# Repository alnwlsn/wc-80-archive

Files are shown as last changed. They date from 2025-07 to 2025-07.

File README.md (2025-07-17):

# The WC-80 (archive)

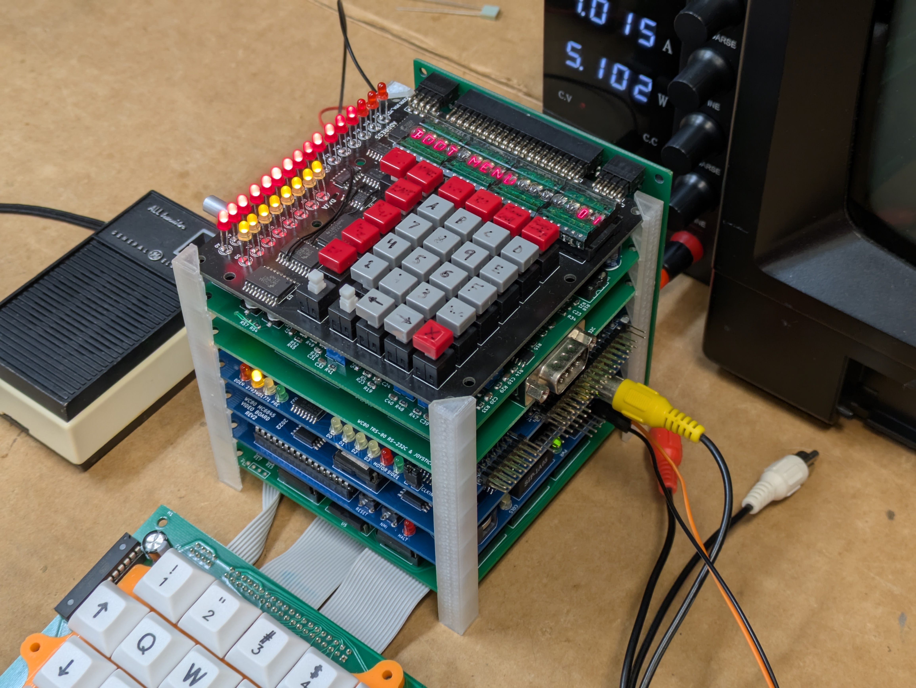
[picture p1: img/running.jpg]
image of WC-80 Cube running


My homebrew Z80 computer which is not exactly a TRS-80 Model 1 clone. Archive from 2020-2023.

## Background
Some time ago when I was in college (not that long ago, mind you, it was like 2018), I found a TRS-80 Model 1. It was the first (non-IBM PC) retrocomputer I had ever got my hands on, and in my book, is absolutely legendary, for reasons I'll have to get into some other time. What's important is that what I got was *only* the keyboard, so no power supply, no cables, no display. The first thing I tried to do with it was cobble up a power supply, and wire up an adapter so I could plug the machine into a regular TV's composite video. I powered it on. It was a working unit. 

What you get with just the base Model 1 "keyboard" is:
- Z80 CPU @ 1.77 MHz
- ROM with Level II (microsoft) BASIC
- 16K of RAM
- video output
    - "almost" NTSC / RS170 (black and white only)
    - 64 columns x 16 rows, 6x12 px character resolution, fixed character set
- cassette interface
- the keyboard itself

That's  pretty limiting if you want to do stuff(tm) with the machine. In particular, the cassette interface is a real bottleneck, taking minutes on end to load things, and it's the only way to do so besides typing it in. People thought so too in the TRS-80's heyday, so the platform evolved to have floppy disks, more memory, various operating systems, a serial port, maybe even a hard drive. These were provided by a box that plugs into the TRS-80's keyboard called the 'Expansion Interface (EI)' I did not an Expansion Interface, and they were rare and expensive on Ebay. But, the TRS-80 is old enough that it is made mostly out of standard 74 logic ICs, rather than custom chips like the C64 or later machines have, and all the schematics are right there in the manual. Having more time than any other resource back then, I thought to myself "how hard can it be?"

Following the schematics, this is what led me to create my [hand-wired Expansion Interface unit](https://alnwlsn.com/projectrepository/index.php?title=TRS-80_Model_1_-_Wilson_Expansion_Interface) and had me boot my TRS-80 from a floppy disk for possibly the first time in its life. That was not quite built as stock though:
- SRAM for extra RAM instead of DRAMs
    - why not, RAM is cheap here in the future
    - 128K ram used, in 4 swappable banks of 32K
        - just because I can, haven't done much with this
- Arduino with 1K dual port RAM put in 'hole' in TRS-80 memory map at 0x3000
    - easy and quick way to get data from modern laptop to TRS-80 RAM
- 'equivalent' logic gates, not exact chips used in EI (based on what chips I happened to have or get easily)

The hand built unit had obvious problems though:
- tedious soldering assembly
- unreliable "stacked pin header" interconnects
- not very modular, hard to add more hardware
- fragile

I then started this project to clean up the hand built unit into some real PCBs, which would go into a backplane. If I wanted to add more hardware, I could just make another card. After building most of the EI, I realized that there wasn't all that much to the rest of the computer, so I built modules for that too. Thus, the WC-80 (W Cube Z80) was born.

It's a bit like a Model 1, with some Model III (more IO on the IO ports) and Model 4 (some peripherals like the video ram and keyboard can be moved around in the memory map, and there are multiple banks of memory). The main difference is that most of the hardware options are software controlled, so it needs to boot a rom that can initialize all the hardware, then load the TRS-80 ROMs and jump to the beginning of it.

As the system took shape, I thought I might install it into a case, and make a portable machine, but soon obtained a good number of real TRS-80 machines to work on instead. I haven't touched the WC-80 much since around 2022, which means I've forgotten most of whatever I was doing on it. Still, it's probably more useful published here as incomplete than just sitting on my hard drive. When I pick up this project again, I'll probably continue in a new repo, which will be linked here if it exists.

loading frogger from a cassette

## General guidelines:
- 100x100mm typical board size
    - this is the cheap "loss leader" size offered by PCBWay and JLC. A board twice this area costs more than double the price.
- where possible, SMD SOIC packages
    - much more compact than DIP, but still easily solderable by hand with an iron
        - plus, you don't have to flip the board over
- 2 layer boards (cheapest)
- 0.2mm track width for data signals
    - fits between SOIC pads
- 74HCT (CMOS w/ TTL level inputs) over HC or LS parts, where possible
- autorouted (w/ some manual routing) with [TopoR](https://en.wikipedia.org/wiki/TopoR)
    - usually get my fill of manually routing boards at work
- designed around whatever ICs I can get for cheap
- fit as much stuff as I can onto each board
    - I paid for the whole board, I'm gonna use the whole board

## Boards
### Backplane
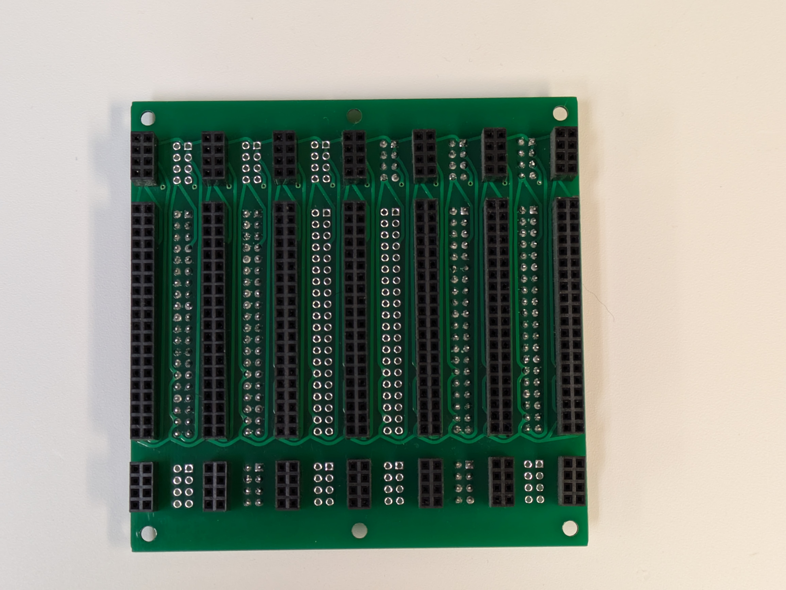
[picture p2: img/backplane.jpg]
backplane

- 40-pin interconnect is derived from the 40-pin card edge on the back of the TRS-80 Model 1, though a few pins are different, so it can't be plugged in directly.
- 8 pin connectors on either side are for power and misc. signals.
- [next revision](boards/backplane2/new/) is just a straight interconnect, which is how it probably should be.
- [this version shown](boards/backplane/) has named nets, and the power rails and GNDs are connected together on the backplane.

### CPU board
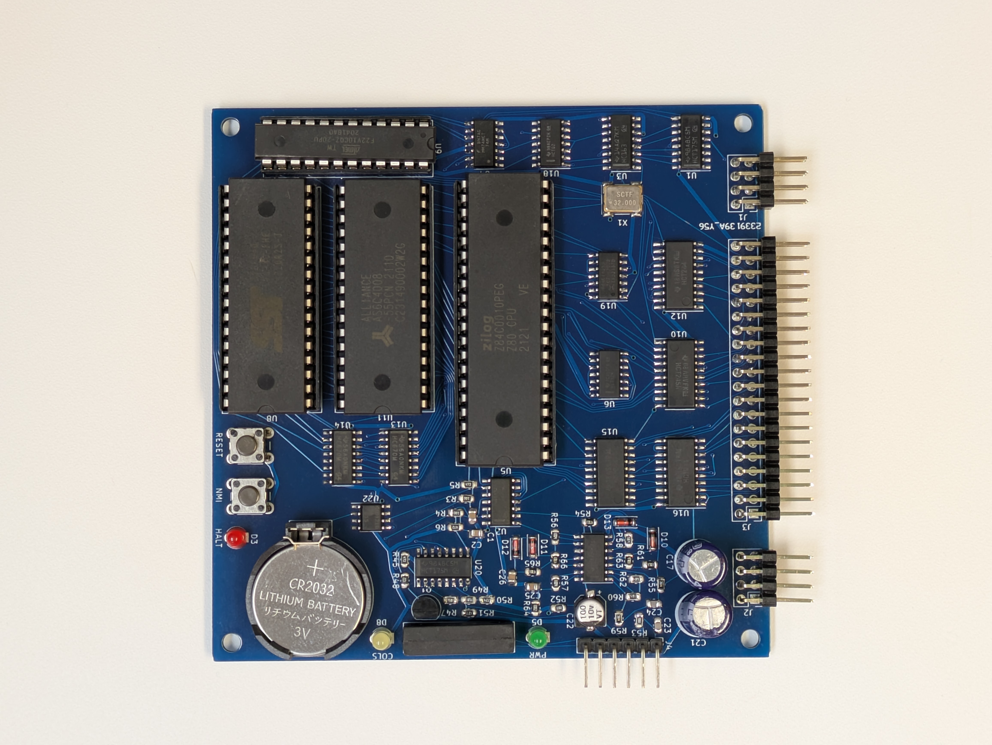
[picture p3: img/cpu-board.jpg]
cpu

- Z80 CPU
- memory map divided into 4x 16k slots, into which any 1 of 32 pages of RAM or 1 of any 32 pages of Flash ROM can be installed. 
    - bank selection by IO port
    - whole memory space is filled, but there is an INUSE pin on the backplane by which other boards can signal the CPU board that they want to use the memory space currently being accessed, in which case on-board memory will be disabled
- software selectable clock rate from 1.77MHz to 8MHz
    - CPU clock provided by a 16MHz clock feeding a counter chip which can count from 2 to 9. 16/9 happens to be pretty close to the 1.77MHz of the model 1. You also get more traditional clock rates of 2, 4 and 8Mhz.
- added the Model 1's cassette interface
    - can read and write TRS-80 Model 1 Level II tapes when running Level II ROMs
    - it can even load tapes played back at 4x speed in 8Mhz mode, seems to work just fine
    - includes reed relay for cassette remote switch
- battery backed RAM with integral RTC via [DS1315 Phantom Time chip](https://www.analog.com/en/products/ds1315.html)
    -   to get and set the RTC, you write a sequential series of special bytes to the RAM and the next byte written will come from the RTC
        - execution must be done either in a ROM or from external RAM, since you can't be both read the instructions and write the special sequence while being on the internal RAM
        - probably get rid of this in the next version, the Arduino board has the same thing already
- [I think this is the current version of the CPU](boards/cpu/cpu-rev2/)

### Keyboard
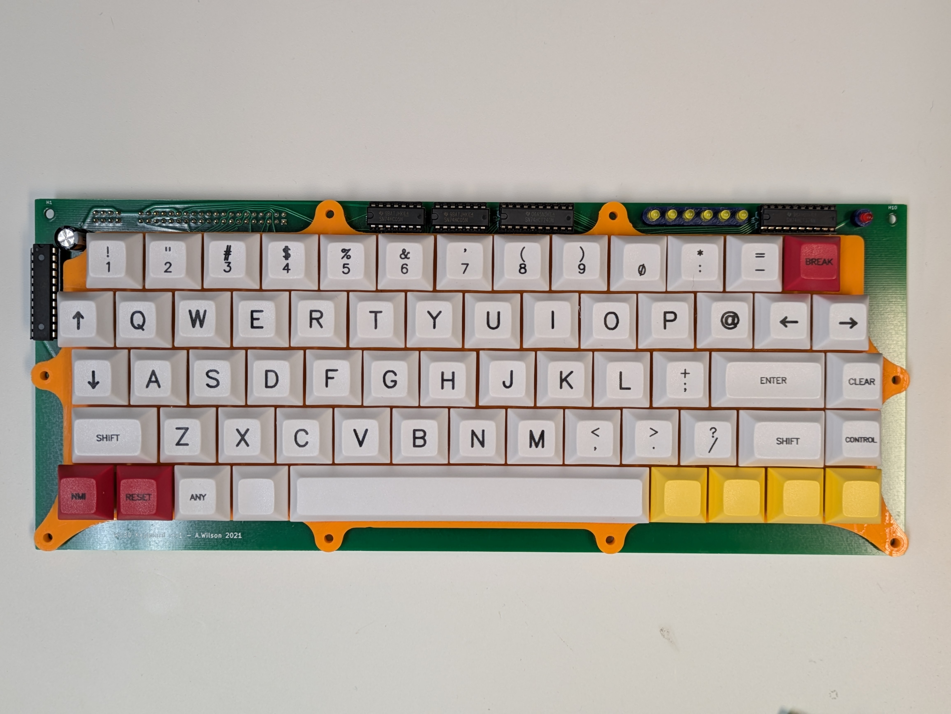
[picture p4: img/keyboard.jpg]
keyboard

- key switches wired per TRS-80 key matrix
- NMI and Reset keys broken out on board
- some extra keys for which there is room on the matrix but normally no switch there (Control key, etc) have been added 
- memory mapped, but relocatable from the default 3800 address, like a model 4
    - only uses 256 addresses, not the minimally decoded 1K the Model 1 has
- 8 leds
- a fairly standard mechanical keyboard build otherwise
- keycaps are [custom labeled](keyboard-labels/) using the [lasered toner method](https://www.youtube.com/watch?v=_V5DmHmCMaU)
- this was supposed to be a simple PCB mounted switch design, but the switches I got ended up being plate mounted. I had to reconfigure my CNC machine to be a 3D printer, as I did not have one large enough to print a full-sized backplate at the time.
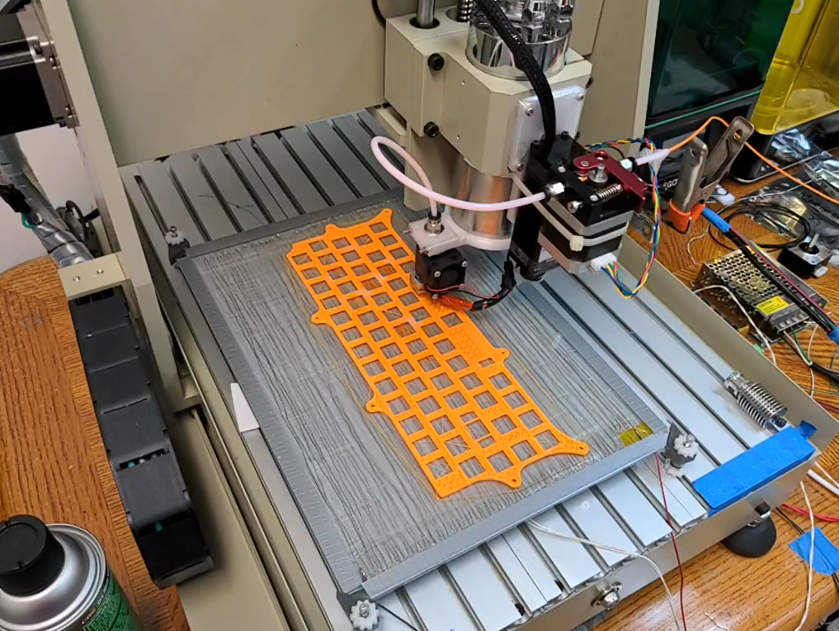
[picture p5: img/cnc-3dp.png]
cnc 3d printer


### Old CPU
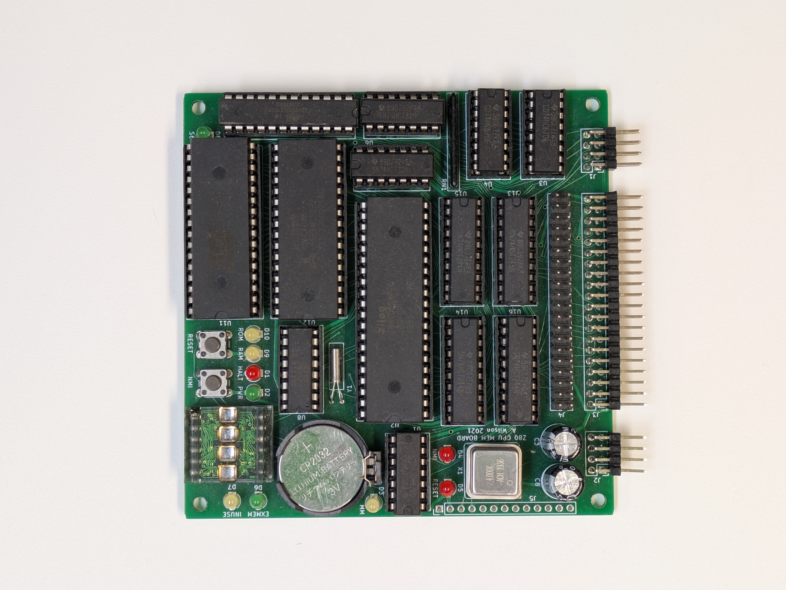
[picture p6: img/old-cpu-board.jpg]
Old CPU

- [despite being called 'cpu5' and the new one being 'cpu2', this is the older one](boards/cpu/cpu5/)
- same as the current CPU board, only using DIP chips and having a HP Dl1414 4-character LED display instead of the cassette interface. This display is usually not visible, so I got rid of it.

```alnwlsn-ssg
title: The WC-80 (archive)
subtitle: homebrew TRS-80 I made one time
date: 2025-07-16
labels: retrocomputing, trs80
```

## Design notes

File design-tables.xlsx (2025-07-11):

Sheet: io-addresses
Function | MEM | IO | 7 | 6 | 5 | 4 | 3 | 2 | 1 | 0 | 7 | 6 | 5 | 4 | 3 | 2 | 1 | 0 | value set on system reset boot
Disk Command/Status | 37EC | F0 |  |  |  |  |  |  |  |  |  |  |  |  |  |  |  |  | 0
Density Select | 37EC | F0 |  |  |  |  |  |  |  |  | 1 | 1 | 1 | 1 | 1 | x | x | DD | f8
Disk Track | 37ED | F1 |  |  |  |  |  |  |  |  |  |  |  |  |  |  |  |  | 0
Disk Sector | 37EE | F2 |  |  |  |  |  |  |  |  |  |  |  |  |  |  |  |  | 0
5/8 Select | 37EE | F2 |  |  |  |  |  |  |  |  | 1 | 8INCH | x | x | x | x | x | x | 80
Disk Data | 37EF | F3 |  |  |  |  |  |  |  |  |  |  |  |  |  |  |  |  | 0
Disk Select | 37E1 | F4 |  |  |  |  |  |  |  |  |  |  |  |  | DRV3 | DRV2 | DRV1 | DRV0 | 0
Model 3 Options | N/A | F4 |  |  |  |  |  |  |  |  | DD | x | WPRE | SIDE1 |  |  |  |  | 0
Interrupt Status | 37E0 | F6 | Clock | Disk |  |  |  |  |  |  |  |  |  |  |  |  |  |  | 0
WC80 Options | N/A | F6 |  |  |  |  |  |  |  |  |  |  |  |  | x | x | MOD3 | 2793 | 1
Printer | 37E8 | F8 |  |  |  |  |  |  |  |  |  |  |  |  |  |  |  |  | 0
mem bank 0 |  | 70 |  |  |  |  |  |  |  |  | !EXMEM 0000-3FFF |  | RAM !ROM
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

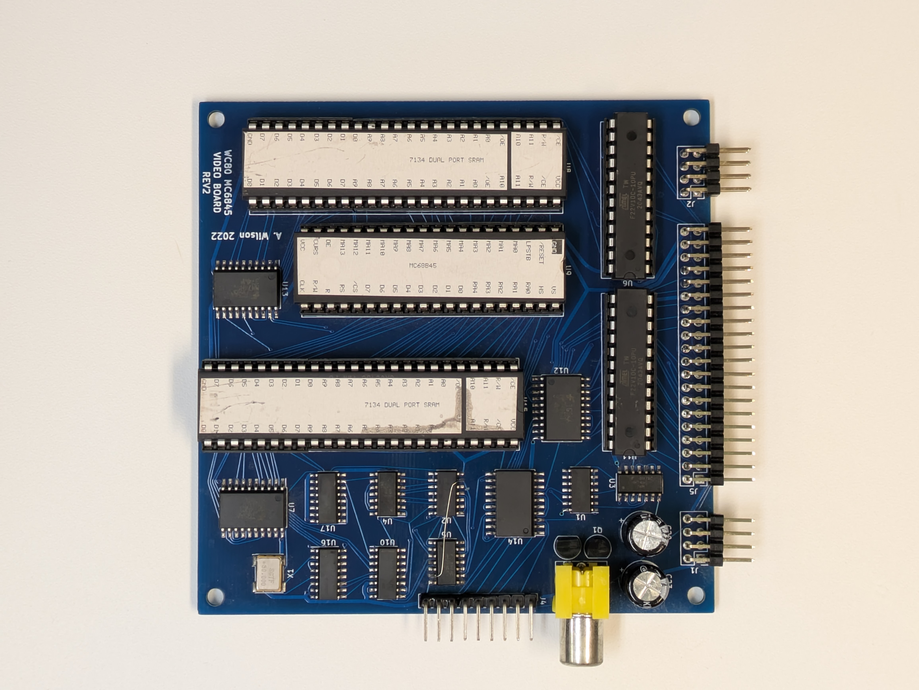
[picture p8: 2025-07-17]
img/video-board.jpg

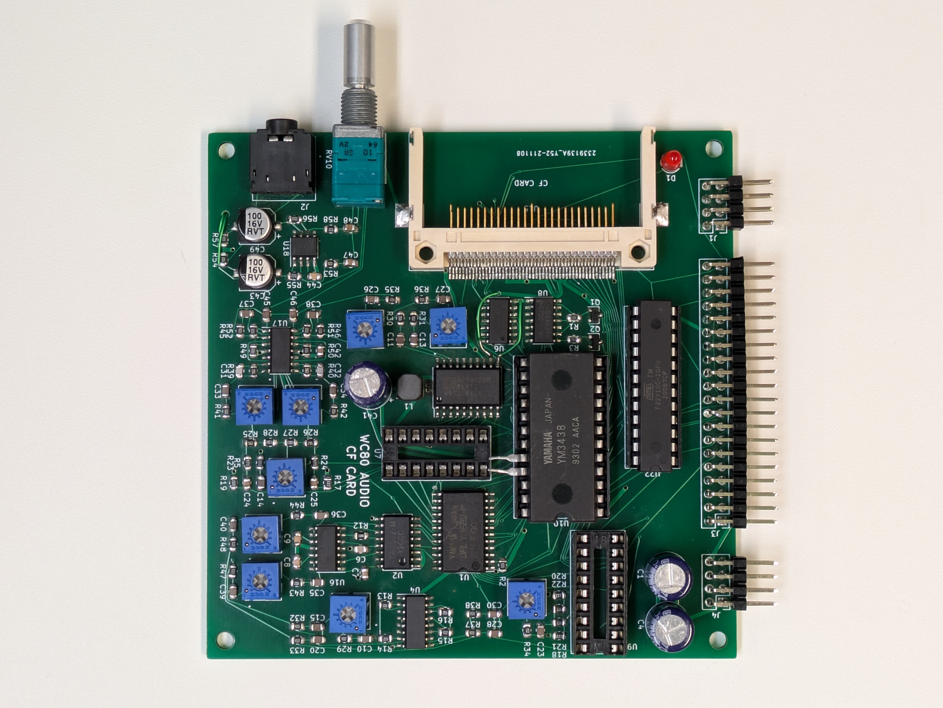
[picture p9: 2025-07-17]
img/sound-board.jpg

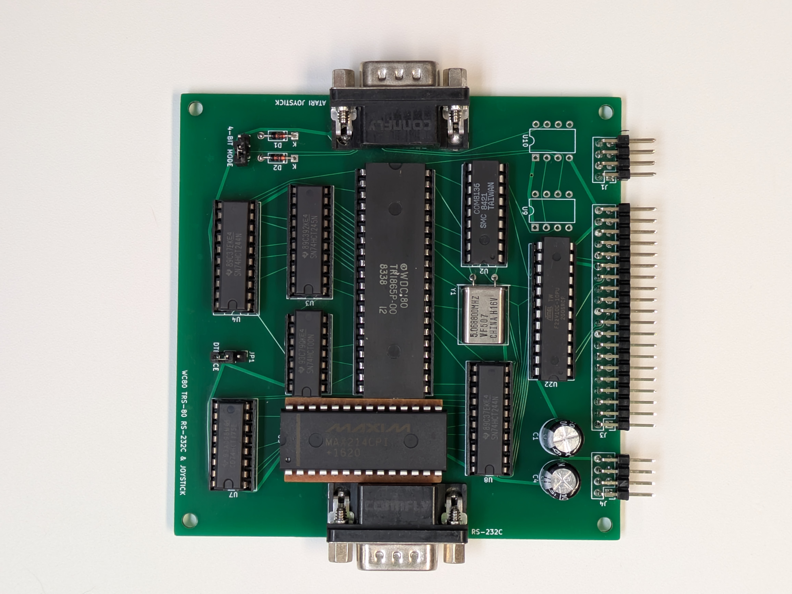
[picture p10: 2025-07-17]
img/rs-232 board.jpg

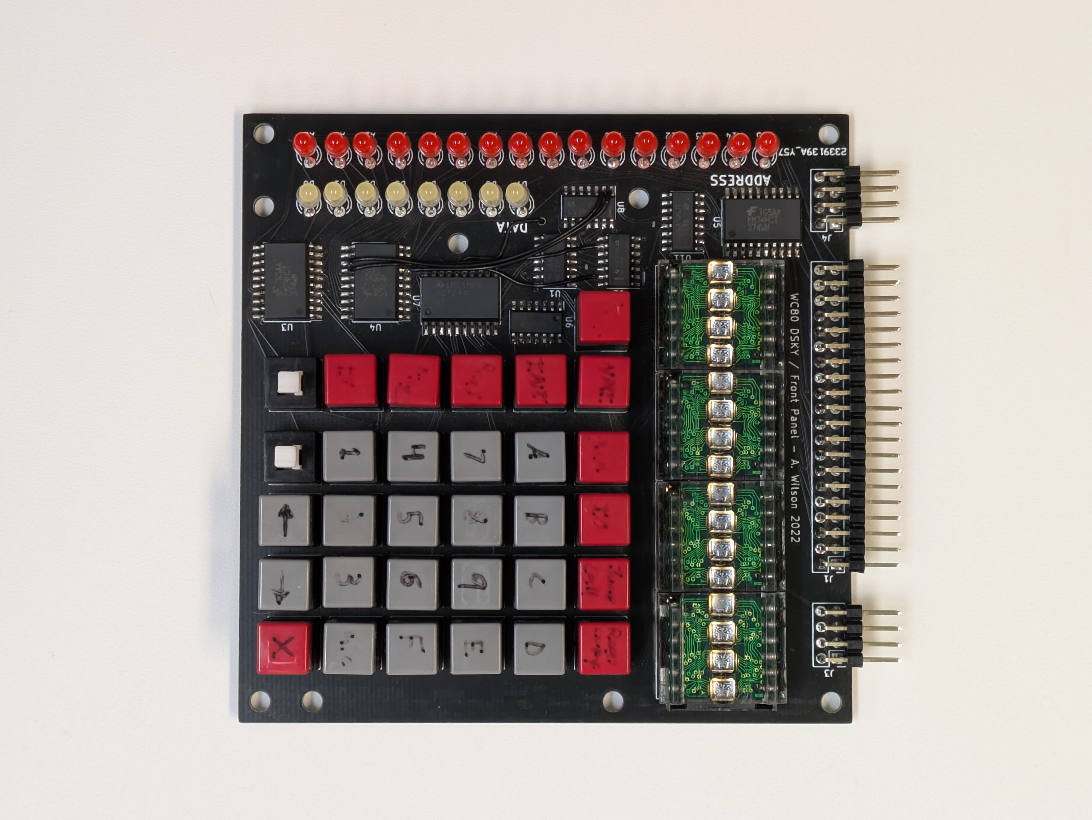
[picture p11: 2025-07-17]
img/front-panel.jpg

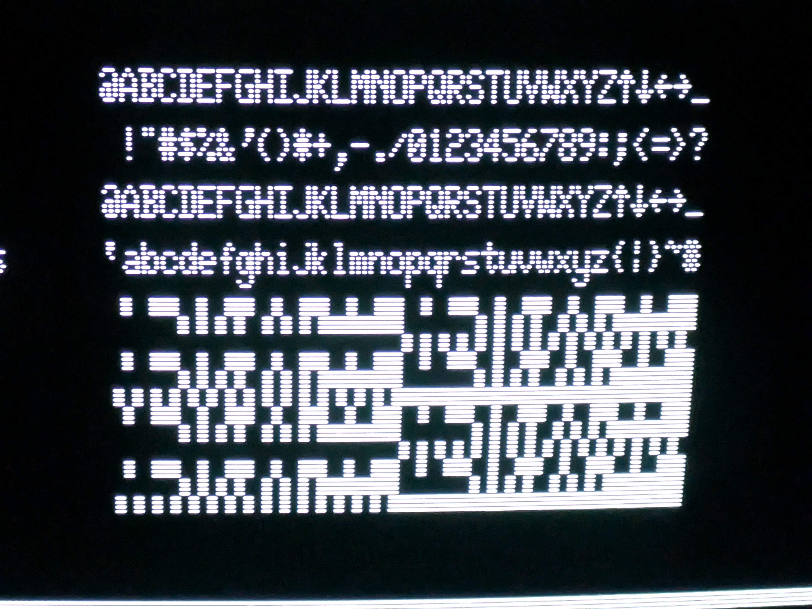
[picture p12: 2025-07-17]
img/video-quality.jpg

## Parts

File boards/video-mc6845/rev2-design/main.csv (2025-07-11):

Reference | Value | Footprint | Datasheet
C8 | 470uF | Capacitor_THT:CP_Radial_D8.0mm_P3.50mm | ~
C10 | 100n | Capacitor_SMD:C_0805_2012Metric | ~
C9 | 100n | Capacitor_SMD:C_0805_2012Metric | ~
C11 | 470uF | Capacitor_THT:CP_Radial_D8.0mm_P3.50mm | ~
J2 | Conn_02x04_Odd_Even | Connector_PinHeader_2.54mm:PinHeader_2x04_P2.54mm_Vertical | ~
J1 | Conn_02x04_Odd_Even | Connector_PinHeader_2.54mm:PinHeader_2x04_P2.54mm_Vertical | ~
C1 | 100n | Capacitor_SMD:C_0805_2012Metric | ~
C7 | 100n | Capacitor_SMD:C_0805_2012Metric | ~
C2 | 100n | Capacitor_SMD:C_0805_2012Metric | ~
C3 | 100n | Capacitor_SMD:C_0805_2012Metric | ~
C4 | 100n | Capacitor_SMD:C_0805_2012Metric | ~
C5 | 100n | Capacitor_SMD:C_0805_2012Metric | ~
C6 | 100n | Capacitor_SMD:C_0805_2012Metric | ~
U15 | 74LS175 | Package_SO:SOIC-16_3.9x9.9mm_P1.27mm | http://www.ti.com/lit/gpn/sn74LS175
R12 | 10K | Resistor_SMD:R_0805_2012Metric | ~
U13 | 74LS374 | Package_SO:SOIC-20W_7.5x12.8mm_P1.27mm | http://www.ti.com/lit/gpn/sn74LS374
U2 | 74LS02 | Package_SO:SOIC-14_3.9x8.7mm_P1.27mm | http://www.ti.com/lit/gpn/sn74ls02
U1 | 74LS02 | Package_SO:SOIC-14_3.9x8.7mm_P1.27mm | http://www.ti.com/lit/gpn/sn74ls02
U18 | 74LS165 | Package_SO:SO-16_3.9x9.9mm_P1.27mm | https://www.ti.com/lit/ds/symlink/sn74ls165a.pdf
R2 | 10K | Resistor_SMD:R_0805_2012Metric | ~
R13 | 10K | Resistor_SMD:R_0805_2012Metric | ~
U4 | 74LS74 | Package_SO:SOIC-14_3.9x8.7mm_P1.27mm | 74xx/74hc_hct74.pdf
U3 | 74LS74 | Package_SO:SOIC-14_3.9x8.7mm_P1.27mm | 74xx/74hc_hct74.pdf
U6 | 74LS374 | Package_SO:SOIC-20W_7.5x12.8mm_P1.27mm | http://www.ti.com/lit/gpn/sn74LS374
R5 | 10K | Resistor_SMD:R_0805_2012Metric | ~
R4 | 10K | Resistor_SMD:R_0805_2012Metric | ~
R15 | 10K | Resistor_SMD:R_0805_2012Metric | ~
J3 | LIGHT_PEN | Connector_PinHeader_2.54mm:PinHeader_1x04_P2.54mm_Horizontal | ~
J4 | CRT_SIGNALS | Connector_PinHeader_2.54mm:PinHeader_1x05_P2.54mm_Vertical | ~
U14 | 74LS244 | Package_SO:SOIC-20W_7.5x12.8mm_P1.27mm | http://www.ti.com/lit/ds/symlink/sn74ls244.pdf
R1 | 10K | Resistor_SMD:R_0805_2012Metric | ~
R6 | 1800 | Resistor_SMD:R_0805_2012Metric | ~
R8 | 2000 | Resistor_SMD:R_0805_2012Metric | ~
R10 | 470 | Resistor_SMD:R_0805_2012Metric | ~
R11 | 470 | Resistor_SMD:R_0805_2012Metric | ~
Q1 | 2N3904 | Package_TO_SOT_THT:TO-92_Inline | https://www.onsemi.com/pub/Collateral/2N3903-D.PDF
U17 | 74LS163 | Package_SO:SOIC-16_3.9x9.9mm_P1.27mm | http://www.ti.com/lit/gpn/sn74LS163
R14 | 10K | Resistor_SMD:R_0805_2012Metric | ~
X1 | SG-7050CAN | Oscillator:Oscillator_SMD_SeikoEpson_SG8002CA-4Pin_7.0x5.0mm | https://support.epson.biz/td/api/doc_check.php?dl=brief_SG7050CAN&lang=en
U9 | 74LS163 | Package_SO:SOIC-16_3.9x9.9mm_P1.27mm | http://www.ti.com/lit/gpn/sn74LS163
R7 | 10 | Resistor_SMD:R_0805_2012Metric | ~
R3 | optional | Resistor_SMD:R_0805_2012Metric | ~
U12 | 74LS374 | Package_SO:SOIC-20W_7.5x12.8mm_P1.27mm | http://www.ti.com/lit/gpn/sn74LS374
Q2 | BSS138 | Package_TO_SOT_SMD:SOT-23 | https://www.onsemi.com/pub/Collateral/BSS138-D.PDF
R9 | 100 | Resistor_SMD:R_0805_2012Metric | ~
R16 | 100 | Resistor_SMD:R_0805_2012Metric | ~
Q3 | BSS138 | Package_TO_SOT_SMD:SOT-23 | https://www.onsemi.com/pub/Collateral/BSS138-D.PDF
C12 | 100n | Capacitor_SMD:C_0805_2012Metric | ~
C13 | 100n | Capacitor_SMD:C_0805_2012Metric | ~
C14 | 100n | Capacitor_SMD:C_0805_2012Metric | ~
C15 | 100n | Capacitor_SMD:C_0805_2012Metric | ~
C16 | 100n | Capacitor_SMD:C_0805_2012Metric | ~
C17 | 100n | Capacitor_SMD:C_0805_2012Metric | ~
C18 | 100n | Capacitor_SMD:C_0805_2012Metric | ~
C19 | 100n | Capacitor_SMD:C_0805_2012Metric | ~
C20 | 100n | Capacitor_SMD:C_0805_2012Metric | ~
C21 | 100n | Capacitor_SMD:C_0805_2012Metric | ~
C22 | 100n | Capacitor_SMD:C_0805_2012Metric | ~
J6 | Conn_Coaxial | wilson-z80:AV-5 | ~

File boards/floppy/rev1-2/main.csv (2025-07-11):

Reference | Value | Footprint | Datasheet | Mouser
C10 | 100n | Capacitor_SMD:C_0805_2012Metric | ~
C11 | 100n | Capacitor_SMD:C_0805_2012Metric | ~
C16 | 100n | Capacitor_SMD:C_0805_2012Metric | ~
C17 | 100n | Capacitor_SMD:C_0805_2012Metric | ~
C18 | 100n | Capacitor_SMD:C_0805_2012Metric | ~
C19 | 100n | Capacitor_SMD:C_0805_2012Metric | ~
C2 | 100n | Capacitor_SMD:C_0805_2012Metric | ~
C20 | 100n | Capacitor_SMD:C_0805_2012Metric | ~
C21 | 100n | Capacitor_SMD:C_0805_2012Metric | ~
C22 | 100n | Capacitor_SMD:C_0805_2012Metric | ~
C23 | 100n | Capacitor_SMD:C_0805_2012Metric | ~
C24 | 100n | Capacitor_SMD:C_0805_2012Metric | ~
C25 | 100n | Capacitor_SMD:C_0805_2012Metric | ~
C26 | 100n | Capacitor_SMD:C_0805_2012Metric | ~
C27 | 100n | Capacitor_SMD:C_0805_2012Metric | ~
C28 | 100n | Capacitor_SMD:C_0805_2012Metric | ~
C29 | 100n | Capacitor_SMD:C_0805_2012Metric | ~
C3 | 100n | Capacitor_SMD:C_0805_2012Metric | ~
C30 | 100n | Capacitor_SMD:C_0805_2012Metric | ~
C31 | 100n | Capacitor_SMD:C_0805_2012Metric | ~
C32 | 100n | Capacitor_SMD:C_0805_2012Metric | ~
C33 | 100n | Capacitor_SMD:C_0805_2012Metric | ~
C34 | 100n | Capacitor_SMD:C_0805_2012Metric | ~
C35 | 100n | Capacitor_SMD:C_0805_2012Metric | ~
C36 | 100n | Capacitor_SMD:C_0805_2012Metric | ~
C37 | 100n | Capacitor_SMD:C_0805_2012Metric | ~
C38 | 100n | Capacitor_SMD:C_0805_2012Metric | ~
C39 | 100n | Capacitor_SMD:C_0805_2012Metric | ~
C40 | 100n | Capacitor_SMD:C_0805_2012Metric | ~
C41 | 100n | Capacitor_SMD:C_0805_2012Metric | ~
C42 | 100n | Capacitor_SMD:C_0805_2012Metric | ~
C43 | 100n | Capacitor_SMD:C_0805_2012Metric | ~
C6 | 100n | Capacitor_SMD:C_0805_2012Metric | ~
C7 | 100n | Capacitor_SMD:C_0805_2012Metric | ~
C8 | 100n | Capacitor_SMD:C_0805_2012Metric | ~
C9 | 150nF | Capacitor_SMD:C_0805_2012Metric | ~
C12 | 15pF | Capacitor_SMD:C_0805_2012Metric | ~
C13 | 15pF | Capacitor_SMD:C_0805_2012Metric | ~
C14 | 15pF | Capacitor_SMD:C_0805_2012Metric | ~
C15 | 200p | Capacitor_SMD:C_0805_2012Metric | ~
C5 | 33uF | Capacitor_SMD:C_0805_2012Metric | ~
C44 | 60pF | Capacitor_THT:C_Rect_L7.0mm_W6.0mm_P5.00mm | ~
C1 | 470uF | Capacitor_THT:CP_Radial_D8.0mm_P3.50mm | ~
C4 | 470uF | Capacitor_THT:CP_Radial_D8.0mm_P3.50mm | ~
JP1 | SIDE | Connector_PinHeader_2.54mm:PinHeader_1x02_P2.54mm_Vertical | ~
JP2 | TEST | Connector_PinHeader_2.54mm:PinHeader_1x02_P2.54mm_Vertical | ~
J1 | Conn_02x04_Odd_Even | Connector_PinHeader_2.54mm:PinHeader_2x04_P2.54mm_Vertical | ~
J4 | Conn_02x04_Odd_Even | Connector_PinHeader_2.54mm:PinHeader_2x04_P2.54mm_Vertical | ~
J5 | Conn_01x16_Male | Connector_PinHeader_2.54mm:PinHeader_2x08_P2.54mm_Vertical | ~
J2 | Floppy-header | Connector_PinHeader_2.54mm:PinHeader_2x17_P2.54mm_Vertical
J3 | TRS80W-header | Connector_PinHeader_2.54mm:PinHeader_2x20_P2.54mm_Vertical
D1 | DIODE | Diode_SMD:D_0805_2012Metric | ~
D6 | D0 | LED_THT:LED_D3.0mm | ~
D7 | D1 | LED_THT:LED_D3.0mm | ~
D8 | D2 | LED_THT:LED_D3.0mm | ~
D9 | D3 | LED_THT:LED_D3.0mm | ~
D4 | DDEN | LED_THT:LED_D3.0mm | ~
D10 | MOTOR | LED_THT:LED_D3.0mm | ~
D5 | PRE | LED_THT:LED_D3.0mm | ~
D11 | SIDE1 | LED_THT:LED_D3.0mm | ~
D3 | WD1771 | LED_THT:LED_D3.0mm | ~
D2 | WD2793 | LED_THT:LED_D3.0mm | ~
M1 | 3mm-mounting-hole | MountingHole:MountingHole_3.2mm_M3_DIN965
M2 | 3mm-mounting-hole | MountingHole:MountingHole_3.2mm_M3_DIN965
M3 | 3mm-mounting-hole | MountingHole:MountingHole_3.2mm_M3_DIN965
M4 | 3mm-mounting-hole | MountingHole:MountingHole_3.2mm_M3_DIN965
X1 | CXO_DIP8 | Oscillator:Oscillator_DIP-8 | http://cdn-reichelt.de/documents/datenblatt/B400/OSZI.pdf | 815-ACH-4-EK
U22 | ATF22V10C | Package_DIP:DIP-24_W7.62mm_Socket
U5 | WD1771 | Package_DIP:DIP-40_W15.24mm_Socket
U16 | WD2793 | Package_DIP:DIP-40_W15.24mm_Socket
U3 | 74LS123 | Package_SO:SO-16_5.3x10.2mm_P1.27mm | http://www.ti.com/lit/gpn/sn74LS123 | 595-SN74LS123NSR
U23 | 74LS244 | Package_SO:SO-20_5.3x12.6mm_P1.27mm | http://www.ti.com/lit/ds/symlink/sn74ls244.pdf | 595-SN74HCT244NSR
U17 | 74LS245 | Package_SO:SO-20_5.3x12.6mm_P1.27mm | http://www.ti.com/lit/gpn/sn74LS245 | 595-SN74LS245NS
U24 | 74LS273 | Package_SO:SO-20_5.3x12.6mm_P1.27mm | http://www.ti.com/lit/gpn/sn74LS273 | 595-SN74LS273NSR
U6 | 74LS640 | Package_SO:SO-20_5.3x12.6mm_P1.27mm | http://www.ti.com/lit/gpn/sn74LS245 | 595-SN74LS640NSR
U12 | 74LS00 | Package_SO:SOIC-14_3.9x8.7mm_P1.27mm | http://www.ti.com/lit/gpn/sn74ls00 | 595-SN74HCT00DE4
U18 | 74LS00 | Package_SO:SOIC-14_3.9x8.7mm_P1.27mm | http://www.ti.com/lit/gpn/sn74ls00 | 595-SN74HCT00DE4
U25 | 74LS00 | Package_SO:SOIC-14_3.9x8.7mm_P1.27mm | http://www.ti.com/lit/gpn/sn74ls00 | 595-SN74HCT00DE4
U30 | 74LS00 | Package_SO:SOIC-14_3.9x8.7mm_P1.27mm | http://www.ti.com/lit/gpn/sn74ls00 | 595-SN74HCT00DE4
U13 | 74LS02 | Package_SO:SOIC-14_3.9x8.7mm_P1.27mm | http://www.ti.com/lit/gpn/sn74ls02 | 595-SN74HCT02DR
U19 | 74LS02 | Package_SO:SOIC-14_3.9x8.7mm_P1.27mm | http://www.ti.com/lit/gpn/sn74ls02 | 595-SN74HCT02DR
U1 | 74LS06 | Package_SO:SOIC-14_3.9x8.7mm_P1.27mm | http://www.ti.com/lit/gpn/sn74LS06 | 595-SN74LS06D
U4 | 74LS06 | Package_SO:SOIC-14_3.9x8.7mm_P1.27mm | http://www.ti.com/lit/gpn/sn74LS06 | 595-SN74LS06D
U11 | 74LS32 | Package_SO:SOIC-14_3.9x8.7mm_P1.27mm | http://www.ti.com/lit/gpn/sn74LS32 | 595-SN74HCT32D
U20 | 74LS32 | Package_SO:SOIC-14_3.9x8.7mm_P1.27mm | http://www.ti.com/lit/gpn/sn74LS32 | 595-SN74HCT32D
U26 | 74LS32 | Package_SO:SOIC-14_3.9x8.7mm_P1.27mm | 74xx/74hc_hct74.pdf | 595-SN74HCT32D
U14 | 74LS74 | Package_SO:SOIC-14_3.9x8.7mm_P1.27mm | 74xx/74hc_hct74.pdf | 863-MC74HCT74ADR2G
U15 | 74LS74 | Package_SO:SOIC-14_3.9x8.7mm_P1.27mm | 74xx/74hc_hct74.pdf | 863-MC74HCT74ADR2G
U21 | 74LS74 | Package_SO:SOIC-14_3.9x8.7mm_P1.27mm | 74xx/74hc_hct74.pdf | 863-MC74HCT74ADR2G
U27 | 74LS74 | Package_SO:SOIC-14_3.9x8.7mm_P1.27mm | 74xx/74hc_hct74.pdf | 863-MC74HCT74ADR2G
U10 | 4518 | Package_SO:SOP-16_3.9x9.9mm_P1.27mm | http://www.intersil.com/content/dam/Intersil/documents/cd45/cd4518bms-20bms.pdf | 595-CD4518BM
U8 | 4518 | Package_SO:SOP-16_3.9x9.9mm_P1.27mm | http://www.intersil.com/content/dam/Intersil/documents/cd45/cd4518bms-20bms.pdf | 595-CD4518BM
U9 | 4518 | Package_SO:SOP-16_3.9x9.9mm_P1.27mm | http://www.intersil.com/content/dam/Intersil/documents/cd45/cd4518bms-20bms.pdf | 595-CD4518BM
U29 | 74LS157 | Package_SO:SOP-16_3.9x9.9mm_P1.27mm | http://www.ti.com/lit/gpn/sn74LS157 | 595-SN74HCT157D
U7 | 74LS157 | Package_SO:SOP-16_3.9x9.9mm_P1.27mm | http://www.ti.com/lit/gpn/sn74LS157 | 595-SN74HCT157D
U2 | 74LS175 | Package_SO:SOP-16_3.9x9.9mm_P1.27mm | http://www.ti.com/lit/gpn/sn74LS175 | 595-CD74HCT175M
U28 | 74LS175 | Package_SO:SOP-16_3.9x9.9mm_P1.27mm | http://www.ti.com/lit/gpn/sn74LS175 | 595-CD74HCT175M
RV2 | 10K | Potentiometer_THT:Potentiometer_Bourns_3266W_Vertical | ~
RV1 | 50K | Potentiometer_THT:Potentiometer_Bourns_3266W_Vertical | ~
R17 | 150 | Resistor_SMD:R_0805_2012Metric | ~
R18 | 150 | Resistor_SMD:R_0805_2012Metric | ~
R19 | 150 | Resistor_SMD:R_0805_2012Metric | ~
R20 | 150 | Resistor_SMD:R_0805_2012Metric | ~
R21 | 470 | Resistor_SMD:R_0805_2012Metric | ~
R22 | 470 | Resistor_SMD:R_0805_2012Metric | ~
R24 | 470 | Resistor_SMD:R_0805_2012Metric | ~
R25 | 470 | Resistor_SMD:R_0805_2012Metric | ~
R26 | 470 | Resistor_SMD:R_0805_2012Metric | ~
R27 | 470 | Resistor_SMD:R_0805_2012Metric | ~
R28 | 470 | Resistor_SMD:R_0805_2012Metric | ~
R29 | 470 | Resistor_SMD:R_0805_2012Metric | ~
R30 | 470 | Resistor_SMD:R_0805_2012Metric | ~
R31 | 470 | Resistor_SMD:R_0805_2012Metric | ~
R10 | 10K | Resistor_SMD:R_0805_2012Metric | ~
R12 | 10K | Resistor_SMD:R_0805_2012Metric | ~
R14 | 10K | Resistor_SMD:R_0805_2012Metric | ~
R23 | 10K | Resistor_SMD:R_0805_2012Metric | ~
R3 | 10K | Resistor_SMD:R_0805_2012Metric | ~
R4 | 10K | Resistor_SMD:R_0805_2012Metric | ~
R5 | 10K | Resistor_SMD:R_0805_2012Metric | ~
R6 | 10K | Resistor_SMD:R_0805_2012Metric | ~
R7 | 10K | Resistor_SMD:R_0805_2012Metric | ~
R8 | 10K | Resistor_SMD:R_0805_2012Metric | ~
R9 | 10K | Resistor_SMD:R_0805_2012Metric | ~
R11 | 1K | Resistor_SMD:R_0805_2012Metric | ~
R1 | 200K | Resistor_SMD:R_0805_2012Metric | ~
R13 | 20K | Resistor_SMD:R_0805_2012Metric | ~
R15 | 4K7 | Resistor_SMD:R_0805_2012Metric | ~
R16 | 4K7 | Resistor_SMD:R_0805_2012Metric | ~
R2 | 4K7 | Resistor_SMD:R_0805_2012Metric | ~

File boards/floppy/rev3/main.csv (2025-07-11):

Reference | Value | Footprint | Datasheet | Mouser
J1 | Floppy-header | Connector_PinHeader_2.54mm:PinHeader_2x17_P2.54mm_Vertical
U4 | 74LS245 | Package_SO:SO-20_5.3x12.6mm_P1.27mm | http://www.ti.com/lit/gpn/sn74LS245 | 595-SN74LS245NS
U9 | WD2793 | Package_DIP:DIP-40_W15.24mm_Socket
U8 | WD1771 | Package_DIP:DIP-40_W15.24mm_Socket
U3 | 74LS640 | Package_SO:SO-20_5.3x12.6mm_P1.27mm | http://www.ti.com/lit/gpn/sn74LS245 | 595-SN74LS640NSR
R4 | 10K | Resistor_SMD:R_0805_2012Metric | ~
U18 | 74LS06 | Package_SO:SOIC-14_3.9x8.7mm_P1.27mm | http://www.ti.com/lit/gpn/sn74LS06 | 595-SN74LS06D
U15 | 74LS157 | Package_SO:SOP-16_3.9x9.9mm_P1.27mm | http://www.ti.com/lit/gpn/sn74LS157 | 595-SN74HCT157D
R8 | 10K | Resistor_SMD:R_0805_2012Metric | ~
U13 | ATF22V10C | Package_DIP:DIP-24_W7.62mm_Socket
U19 | 74LS06 | Package_SO:SOIC-14_3.9x8.7mm_P1.27mm | http://www.ti.com/lit/gpn/sn74LS06 | 595-SN74LS06D
U10 | 74LS123 | Package_SO:SO-16_5.3x10.2mm_P1.27mm | http://www.ti.com/lit/gpn/sn74LS123 | 595-SN74LS123NSR
U14 | 74LS175 | Package_SO:SOP-16_3.9x9.9mm_P1.27mm | http://www.ti.com/lit/gpn/sn74LS175 | 595-CD74HCT175M
JP10 | SIDE | Connector_PinHeader_2.54mm:PinHeader_1x02_P2.54mm_Vertical | ~
U30 | 74LS273 | Package_SO:SO-20_5.3x12.6mm_P1.27mm | http://www.ti.com/lit/gpn/sn74LS273 | 595-SN74LS273NSR
R37 | 4K7 | Resistor_SMD:R_0805_2012Metric | ~
R36 | 20K | Resistor_SMD:R_0805_2012Metric | ~
C45 | 200p | Capacitor_SMD:C_0805_2012Metric | ~
R38 | 4K7 | Resistor_SMD:R_0805_2012Metric | ~
U26 | 74LS244 | Package_SO:SO-20_5.3x12.6mm_P1.27mm | http://www.ti.com/lit/ds/symlink/sn74ls244.pdf | 595-SN74HCT244NSR
J6 | Conn_01x16_Male | Connector_PinHeader_2.54mm:PinHeader_2x08_P2.54mm_Vertical | ~
R3 | 200K | Resistor_SMD:R_0805_2012Metric | ~
R35 | 10K | Resistor_SMD:R_0805_2012Metric | ~
U12 | 74LS02 | Package_SO:SOIC-14_3.9x8.7mm_P1.27mm | http://www.ti.com/lit/gpn/sn74ls02 | 595-SN74HCT02DR
R1 | 10K | Resistor_SMD:R_0805_2012Metric | ~
R6 | 10K | Resistor_SMD:R_0805_2012Metric | ~
R5 | 10K | Resistor_SMD:R_0805_2012Metric | ~
RV1 | 50K | Potentiometer_THT:Potentiometer_Bourns_3266W_Vertical | ~
RV2 | 10K | Potentiometer_THT:Potentiometer_Bourns_3266W_Vertical | ~
D1 | DIODE | Diode_SMD:D_0805_2012Metric | ~
C7 | 150nF | Capacitor_SMD:C_0805_2012Metric | ~
R7 | 1K | Resistor_SMD:R_0805_2012Metric | ~
JP1 | TEST | Connector_PinHeader_2.54mm:PinHeader_1x02_P2.54mm_Vertical | ~
C4 | 15pF | Capacitor_SMD:C_0805_2012Metric | ~
C5 | 15pF | Capacitor_SMD:C_0805_2012Metric | ~
C6 | 15pF | Capacitor_SMD:C_0805_2012Metric | ~
U11 | 74LS00 | Package_SO:SOIC-14_3.9x8.7mm_P1.27mm | http://www.ti.com/lit/gpn/sn74ls00 | 595-SN74HCT00DE4
U5 | 74LS02 | Package_SO:SOIC-14_3.9x8.7mm_P1.27mm | http://www.ti.com/lit/gpn/sn74ls02 | 595-SN74HCT02DR
U6 | 74LS32 | Package_SO:SOIC-14_3.9x8.7mm_P1.27mm | http://www.ti.com/lit/gpn/sn74LS32 | 595-SN74HCT32D
U7 | 74LS00 | Package_SO:SOIC-14_3.9x8.7mm_P1.27mm | http://www.ti.com/lit/gpn/sn74ls00 | 595-SN74HCT00DE4
U20 | 74LS74 | Package_SO:SOIC-14_3.9x8.7mm_P1.27mm | 74xx/74hc_hct74.pdf | 863-MC74HCT74ADR2G
R11 | 10K | Resistor_SMD:R_0805_2012Metric | ~
U17 | 74LS32 | Package_SO:SOIC-14_3.9x8.7mm_P1.27mm | 74xx/74hc_hct74.pdf | 595-SN74HCT32D
C18 | 470uF | Capacitor_THT:CP_Radial_D8.0mm_P3.50mm | ~
C13 | 100n | Capacitor_SMD:C_0805_2012Metric | ~
C14 | 100n | Capacitor_SMD:C_0805_2012Metric | ~
C15 | 100n | Capacitor_SMD:C_0805_2012Metric | ~
C16 | 100n | Capacitor_SMD:C_0805_2012Metric | ~
C17 | 100n | Capacitor_SMD:C_0805_2012Metric | ~
C20 | 100n | Capacitor_SMD:C_0805_2012Metric | ~
C19 | 100n | Capacitor_SMD:C_0805_2012Metric | ~
C21 | 470uF | Capacitor_THT:CP_Radial_D8.0mm_P3.50mm | ~
J4 | Conn_02x04_Odd_Even | Connector_PinHeader_2.54mm:PinHeader_2x04_P2.54mm_Vertical | ~
J3 | Conn_02x04_Odd_Even | Connector_PinHeader_2.54mm:PinHeader_2x04_P2.54mm_Vertical | ~
M4 | 3mm-mounting-hole | MountingHole:MountingHole_3.2mm_M3_DIN965
M3 | 3mm-mounting-hole | MountingHole:MountingHole_3.2mm_M3_DIN965
M2 | 3mm-mounting-hole | MountingHole:MountingHole_3.2mm_M3_DIN965
M1 | 3mm-mounting-hole | MountingHole:MountingHole_3.2mm_M3_DIN965
J2 | TRS80W-header | Connector_PinHeader_2.54mm:PinHeader_2x20_P2.54mm_Vertical
U25 | 4518 | Package_SO:SOP-16_3.9x9.9mm_P1.27mm | http://www.intersil.com/content/dam/Intersil/documents/cd45/cd4518bms-20bms.pdf | 595-CD4518BM
U24 | 74LS74 | Package_SO:SOIC-14_3.9x8.7mm_P1.27mm | 74xx/74hc_hct74.pdf | 863-MC74HCT74ADR2G
R33 | 10K | Resistor_SMD:R_0805_2012Metric | ~
R34 | 10K | Resistor_SMD:R_0805_2012Metric | ~
U27 | 4518 | Package_SO:SOP-16_3.9x9.9mm_P1.27mm | http://www.intersil.com/content/dam/Intersil/documents/cd45/cd4518bms-20bms.pdf | 595-CD4518BM
U28 | 4518 | Package_SO:SOP-16_3.9x9.9mm_P1.27mm | http://www.intersil.com/content/dam/Intersil/documents/cd45/cd4518bms-20bms.pdf | 595-CD4518BM
U29 | 74LS74 | Package_SO:SOIC-14_3.9x8.7mm_P1.27mm | 74xx/74hc_hct74.pdf | 863-MC74HCT74ADR2G
R39 | 10K | Resistor_SMD:R_0805_2012Metric | ~
R15 | 150 | Resistor_SMD:R_0805_2012Metric | ~
R16 | 150 | Resistor_SMD:R_0805_2012Metric | ~
R14 | 150 | Resistor_SMD:R_0805_2012Metric | ~
U16 | 74LS00 | Package_SO:SOIC-14_3.9x8.7mm_P1.27mm | http://www.ti.com/lit/gpn/sn74ls00 | 595-SN74HCT00DE4
U1 | 74LS00 | Package_SO:SOIC-14_3.9x8.7mm_P1.27mm | http://www.ti.com/lit/gpn/sn74ls00 | 595-SN74HCT00DE4
U21 | 74LS74 | Package_SO:SOIC-14_3.9x8.7mm_P1.27mm | 74xx/74hc_hct74.pdf | 863-MC74HCT74ADR2G
U23 | 74LS157 | Package_SO:SOP-16_3.9x9.9mm_P1.27mm | http://www.ti.com/lit/gpn/sn74LS157 | 595-SN74HCT157D
U22 | 74LS175 | Package_SO:SOP-16_3.9x9.9mm_P1.27mm | http://www.ti.com/lit/gpn/sn74LS175 | 595-CD74HCT175M
R20 | 10K | Resistor_SMD:R_0805_2012Metric | ~
C22 | 100n | Capacitor_SMD:C_0805_2012Metric | ~
C46 | 100n | Capacitor_SMD:C_0805_2012Metric | ~
C9 | 100n | Capacitor_SMD:C_0805_2012Metric | ~
C10 | 100n | Capacitor_SMD:C_0805_2012Metric | ~
C23 | 100n | Capacitor_SMD:C_0805_2012Metric | ~
C24 | 100n | Capacitor_SMD:C_0805_2012Metric | ~
C25 | 100n | Capacitor_SMD:C_0805_2012Metric | ~
C26 | 100n | Capacitor_SMD:C_0805_2012Metric | ~
C27 | 100n | Capacitor_SMD:C_0805_2012Metric | ~
C28 | 100n | Capacitor_SMD:C_0805_2012Metric | ~
C29 | 100n | Capacitor_SMD:C_0805_2012Metric | ~
C30 | 100n | Capacitor_SMD:C_0805_2012Metric | ~
C31 | 100n | Capacitor_SMD:C_0805_2012Metric | ~
C32 | 100n | Capacitor_SMD:C_0805_2012Metric | ~
C33 | 100n | Capacitor_SMD:C_0805_2012Metric | ~
C34 | 100n | Capacitor_SMD:C_0805_2012Metric | ~
D2 | 2793 | LED_THT:LED_D3.0mm | ~
R13 | 150 | Resistor_SMD:R_0805_2012Metric | ~
R22 | 470 | Resistor_SMD:R_0805_2012Metric | ~
R24 | 470 | Resistor_SMD:R_0805_2012Metric | ~
D4 | DDEN | LED_THT:LED_D3.0mm | ~
R25 | 470 | Resistor_SMD:R_0805_2012Metric | ~
R26 | 470 | Resistor_SMD:R_0805_2012Metric | ~
D5 | PRE | LED_THT:LED_D3.0mm | ~
R27 | 470 | Resistor_SMD:R_0805_2012Metric | ~
D6 | D0 | LED_THT:LED_D3.0mm | ~
R28 | 470 | Resistor_SMD:R_0805_2012Metric | ~
D7 | D1 | LED_THT:LED_D3.0mm | ~
R29 | 470 | Resistor_SMD:R_0805_2012Metric | ~
D8 | D2 | LED_THT:LED_D3.0mm | ~
R30 | 470 | Resistor_SMD:R_0805_2012Metric | ~
D9 | D3 | LED_THT:LED_D3.0mm | ~
R31 | 470 | Resistor_SMD:R_0805_2012Metric | ~
D10 | MOTOR | LED_THT:LED_D3.0mm | ~
R32 | 470 | Resistor_SMD:R_0805_2012Metric | ~
D11 | SIDE1 | LED_THT:LED_D3.0mm | ~
C12 | 100n | Capacitor_SMD:C_0805_2012Metric | ~
C11 | 100n | Capacitor_SMD:C_0805_2012Metric | ~
C35 | 100n | Capacitor_SMD:C_0805_2012Metric | ~
C36 | 100n | Capacitor_SMD:C_0805_2012Metric | ~
C37 | 100n | Capacitor_SMD:C_0805_2012Metric | ~
C38 | 100n | Capacitor_SMD:C_0805_2012Metric | ~
C39 | 100n | Capacitor_SMD:C_0805_2012Metric | ~
C40 | 100n | Capacitor_SMD:C_0805_2012Metric | ~
C41 | 100n | Capacitor_SMD:C_0805_2012Metric | ~
C42 | 100n | Capacitor_SMD:C_0805_2012Metric | ~
C43 | 100n | Capacitor_SMD:C_0805_2012Metric | ~
C44 | 100n | Capacitor_SMD:C_0805_2012Metric | ~
C8 | 60pF | Capacitor_THT:C_Rect_L7.0mm_W6.0mm_P5.00mm | ~
C3 | 33uF | Capacitor_SMD:C_0805_2012Metric | ~
R2 | 4K7 | Resistor_SMD:R_0805_2012Metric | ~
U2 | 74LS08 | Package_SO:SOIC-14_3.9x8.7mm_P1.27mm | http://www.ti.com/lit/gpn/sn74LS08
C2 | 33uF | Capacitor_SMD:C_0805_2012Metric | ~
C1 | 33uF | Capacitor_SMD:C_0805_2012Metric | ~
R21 | 10K | Resistor_SMD:R_0805_2012Metric | ~
J5 | 5V | Connector_PinHeader_2.54mm:PinHeader_1x02_P2.54mm_Vertical | ~
JP9 | M1 | Jumper:SolderJumper-2_P1.3mm_Bridged_RoundedPad1.0x1.5mm | ~
JP8 | M3 | Jumper:SolderJumper-2_P1.3mm_Open_RoundedPad1.0x1.5mm | ~
R19 | 10K | Resistor_SMD:R_0805_2012Metric | ~
JP6 | 2793 | Jumper:SolderJumper-2_P1.3mm_Bridged_RoundedPad1.0x1.5mm | ~
JP7 | 1771 | Jumper:SolderJumper-2_P1.3mm_Open_RoundedPad1.0x1.5mm | ~
R17 | 10K | Resistor_SMD:R_0805_2012Metric | ~
R18 | 10K | Resistor_SMD:R_0805_2012Metric | ~
JP5 | SD | Jumper:SolderJumper-2_P1.3mm_Bridged_RoundedPad1.0x1.5mm | ~
JP4 | DD | Jumper:SolderJumper-2_P1.3mm_Open_RoundedPad1.0x1.5mm | ~
R10 | 10K | Resistor_SMD:R_0805_2012Metric | ~
JP3 | SD | Jumper:SolderJumper-2_P1.3mm_Bridged_RoundedPad1.0x1.5mm | ~
JP2 | DD | Jumper:SolderJumper-2_P1.3mm_Open_RoundedPad1.0x1.5mm | ~
R12 | 10K | Resistor_SMD:R_0805_2012Metric | ~
R9 | 10K | Resistor_SMD:R_0805_2012Metric | ~
X1 | SG-7050CAN | Oscillator:Oscillator_SMD_SeikoEpson_SG8002CA-4Pin_7.0x5.0mm | https://support.epson.biz/td/api/doc_check.php?dl=brief_SG7050CAN&lang=en
JP11 | CLKINT | Connector_PinHeader_2.54mm:PinHeader_1x02_P2.54mm_Vertical | ~
D3 | WD1771 | LED_THT:LED_D3.0mm | ~

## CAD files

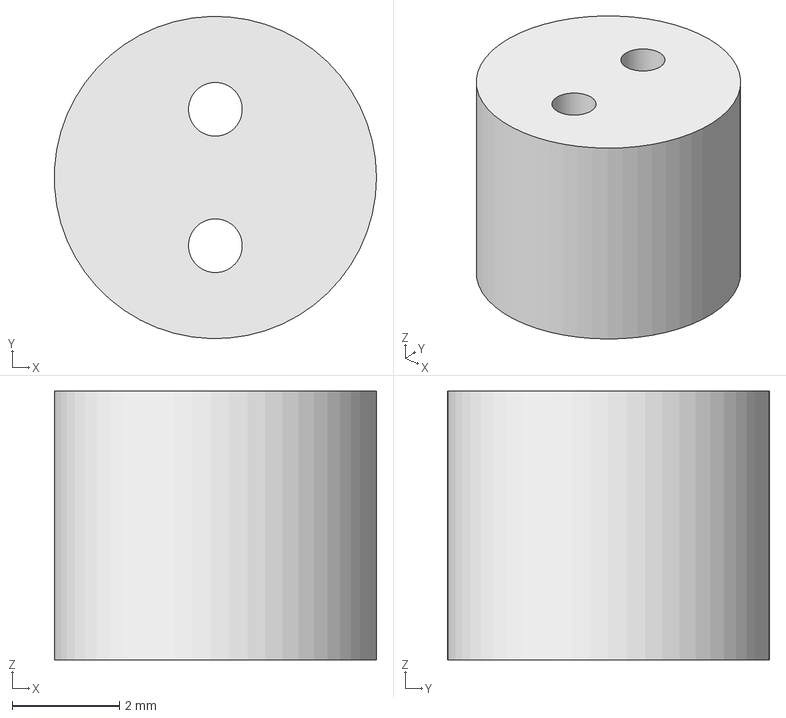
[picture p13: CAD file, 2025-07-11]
keyboard-cad/led-holder-single.FCStd
6.00 x 6.00 x 5.00 mm

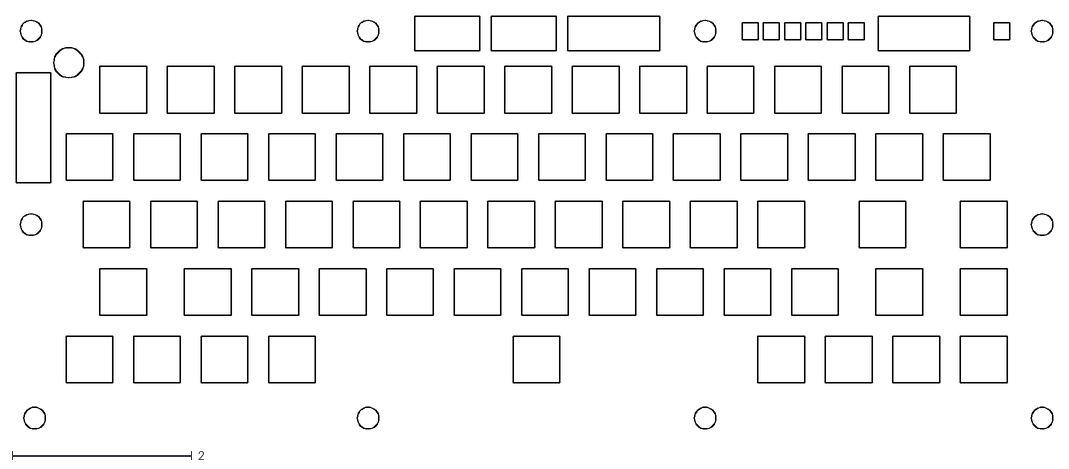
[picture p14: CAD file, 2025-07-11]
keyboard-cad/keyboard-matrix-scrap-layout-F_CrtYd.dxf
11.5 x 4.59

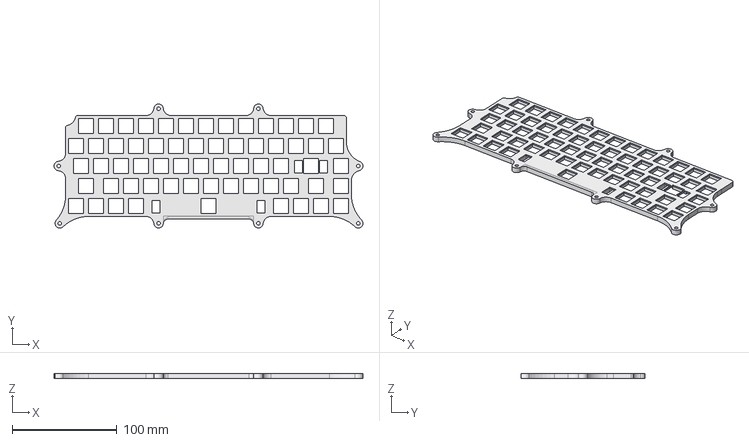
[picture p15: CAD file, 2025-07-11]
keyboard-cad/keyplate-v2.FCStd
294.5 x 118.2 x 5.00 mm

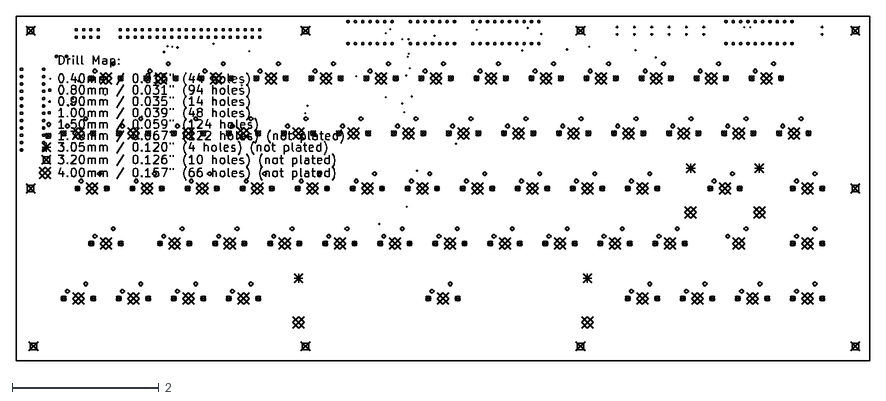
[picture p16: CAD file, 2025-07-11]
keyboard-cad/keyboard-matrix-scrap-layout-drl_map.dxf
11.6 x 4.69

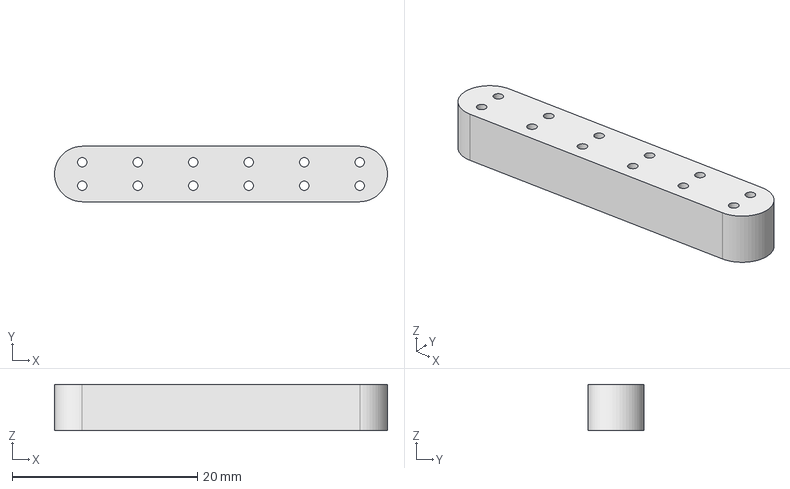
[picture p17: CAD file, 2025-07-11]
keyboard-cad/led-holder-multi.FCStd
36.0 x 6.00 x 5.00 mm

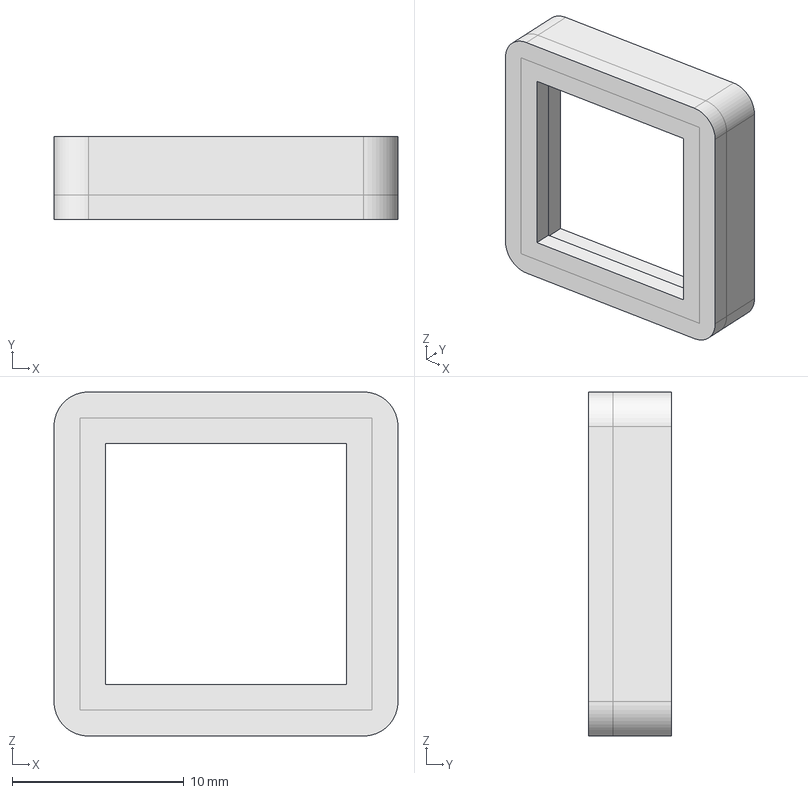
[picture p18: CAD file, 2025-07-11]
keyboard-cad/switch-fit-test1.FCStd
20.0 x 4.80 x 20.0 mm

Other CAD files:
keyboard-cad/keyplate-v1.FCStd
keyboard-cad/keyboard-matrix-scrap-layout-F_Mask.dxf

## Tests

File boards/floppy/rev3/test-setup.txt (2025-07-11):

WD-80 2793 Floppy Controller Calibration

no test link
dd mode - out (0xf0),fa
insert test link
measure 2793 pin #31 (WD)
look at pulse width
adjust write precompensation pot (RV2) so pulse width is 125 - 150 nS

measure 2793 pin #29 (TG43)
look at pulse width
adjust data seperator pot (RV1) so pulse width is 500 nS

measure 2793 pin #16 (DIRC) 
look at frequency
adjust trimmer cap so that frequency is 250 kHz

remove test link

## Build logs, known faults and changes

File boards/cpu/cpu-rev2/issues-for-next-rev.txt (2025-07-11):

silkscreen for r3 and c1 was swapped (fixed)

labels RAMROM and MEMCHIP should be swapped

possibly connect MEMCHIP to the selector register file

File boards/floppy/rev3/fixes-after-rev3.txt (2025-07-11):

diode on charge pump should be a better package

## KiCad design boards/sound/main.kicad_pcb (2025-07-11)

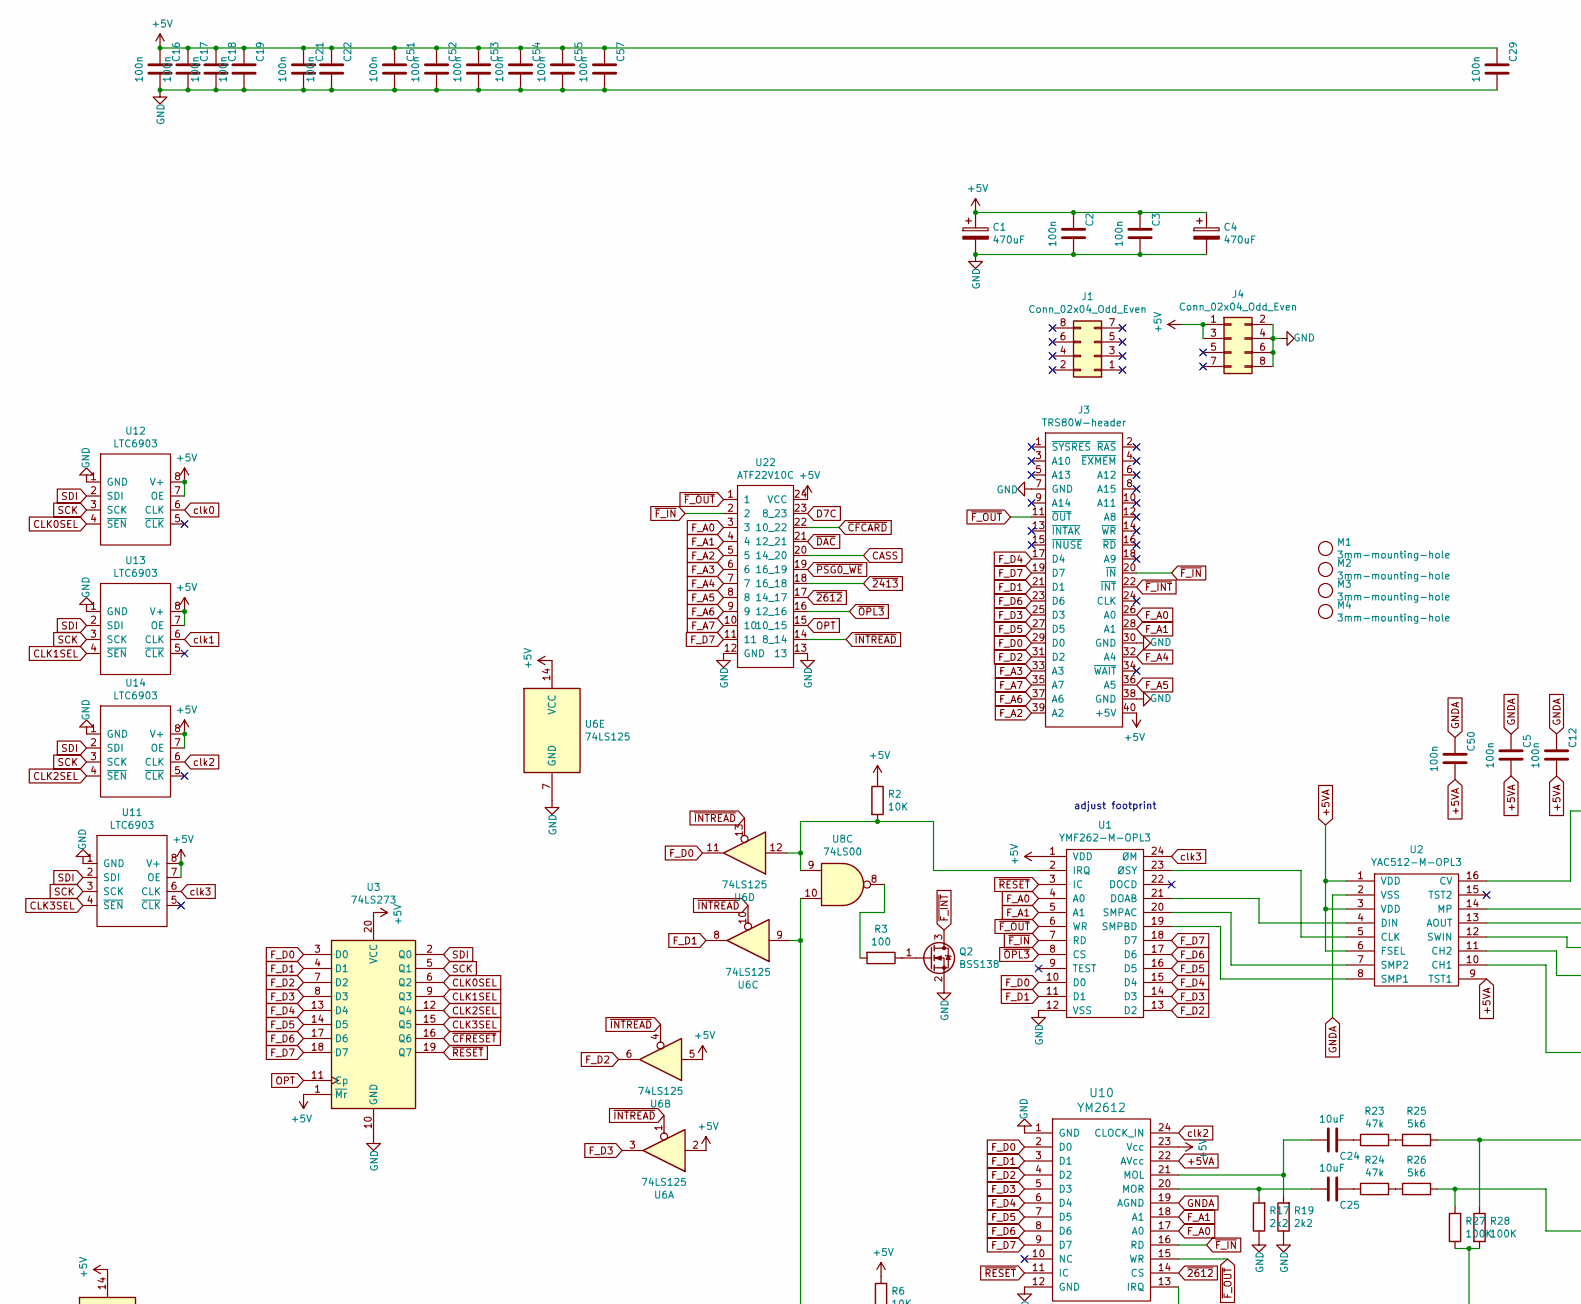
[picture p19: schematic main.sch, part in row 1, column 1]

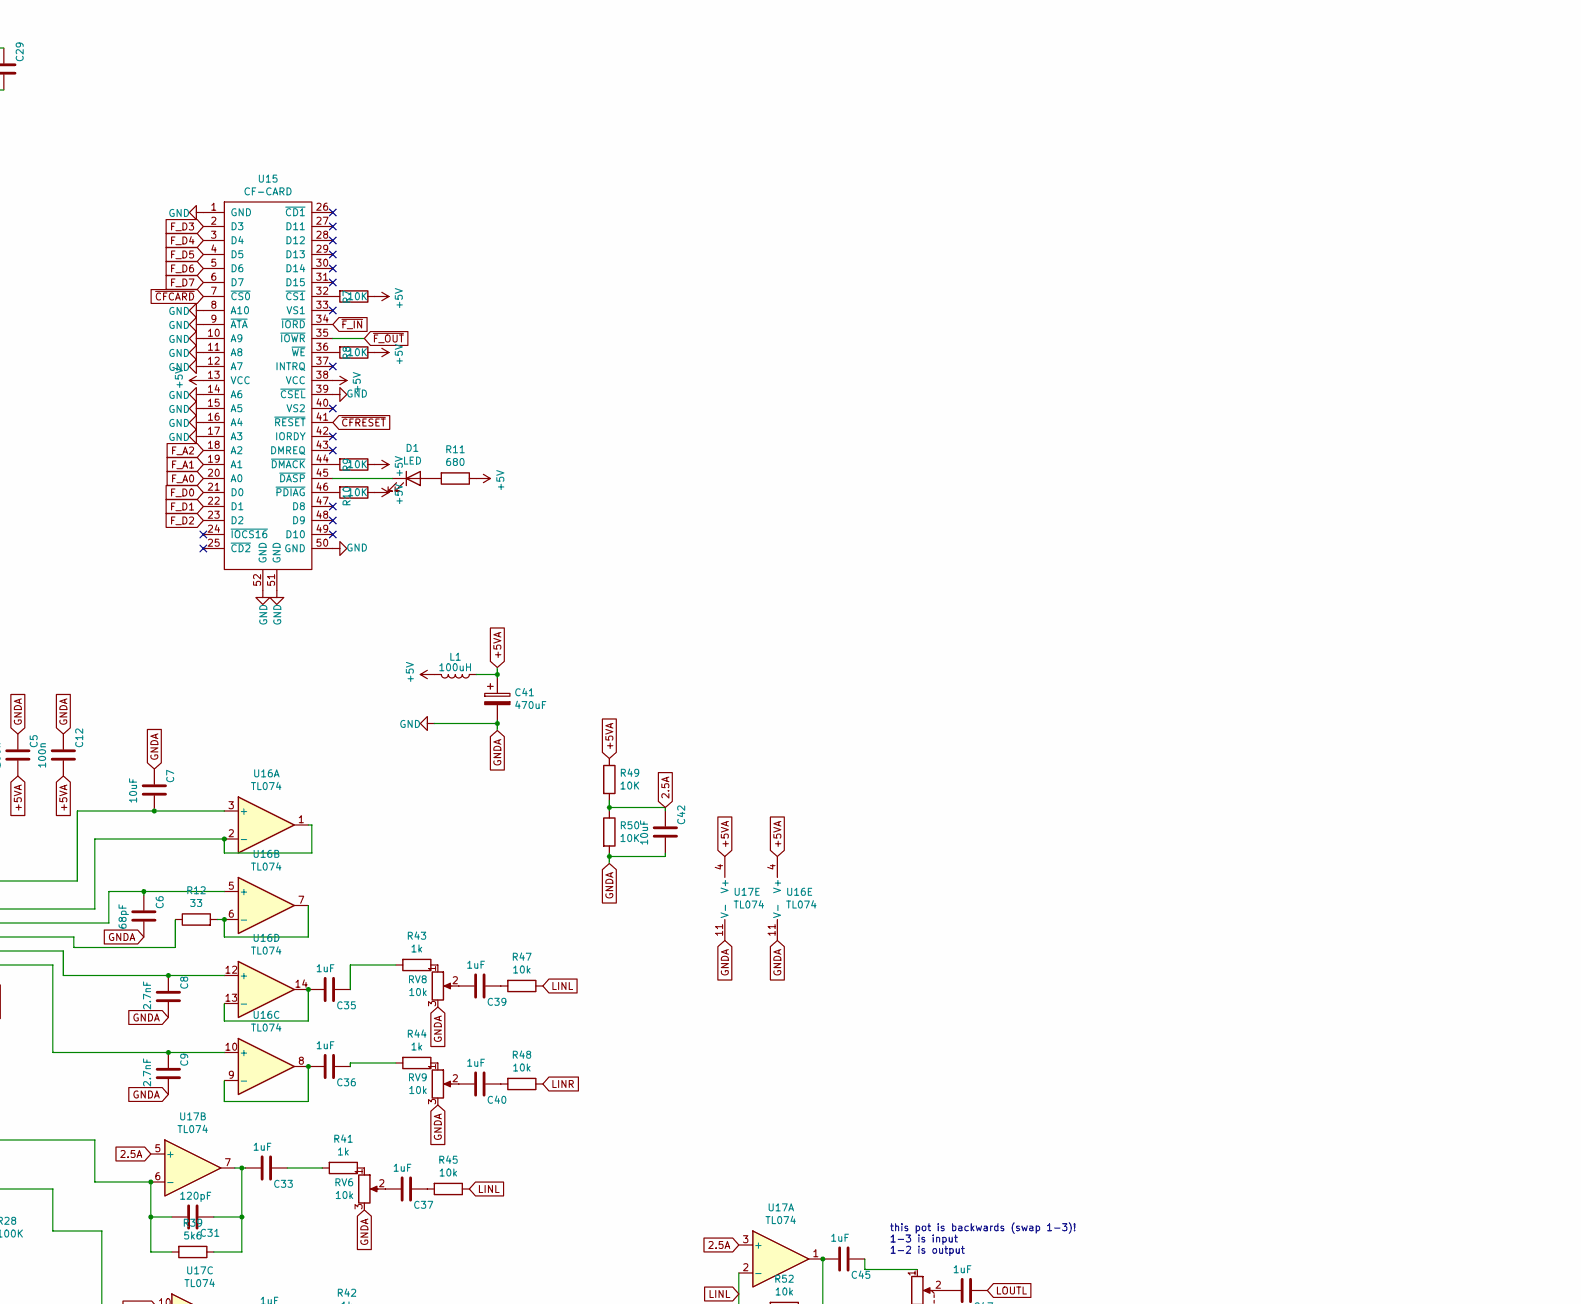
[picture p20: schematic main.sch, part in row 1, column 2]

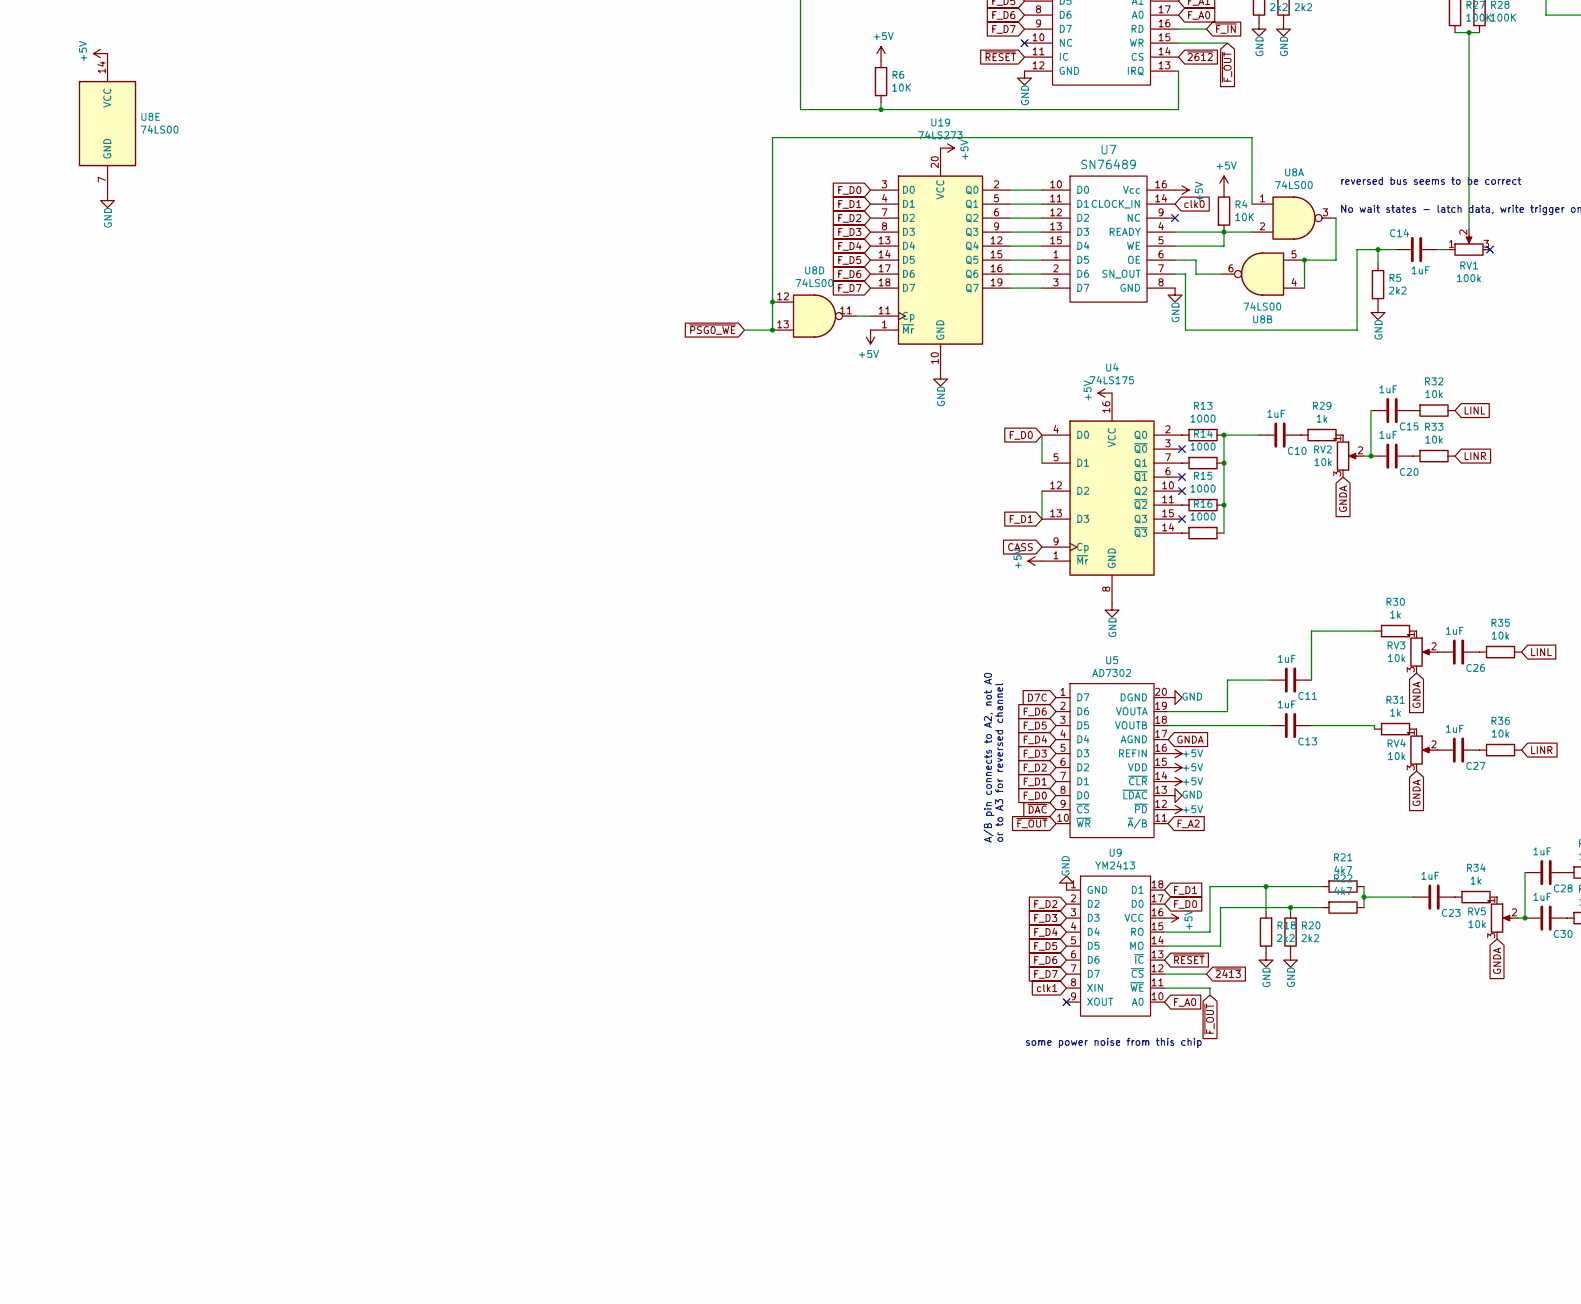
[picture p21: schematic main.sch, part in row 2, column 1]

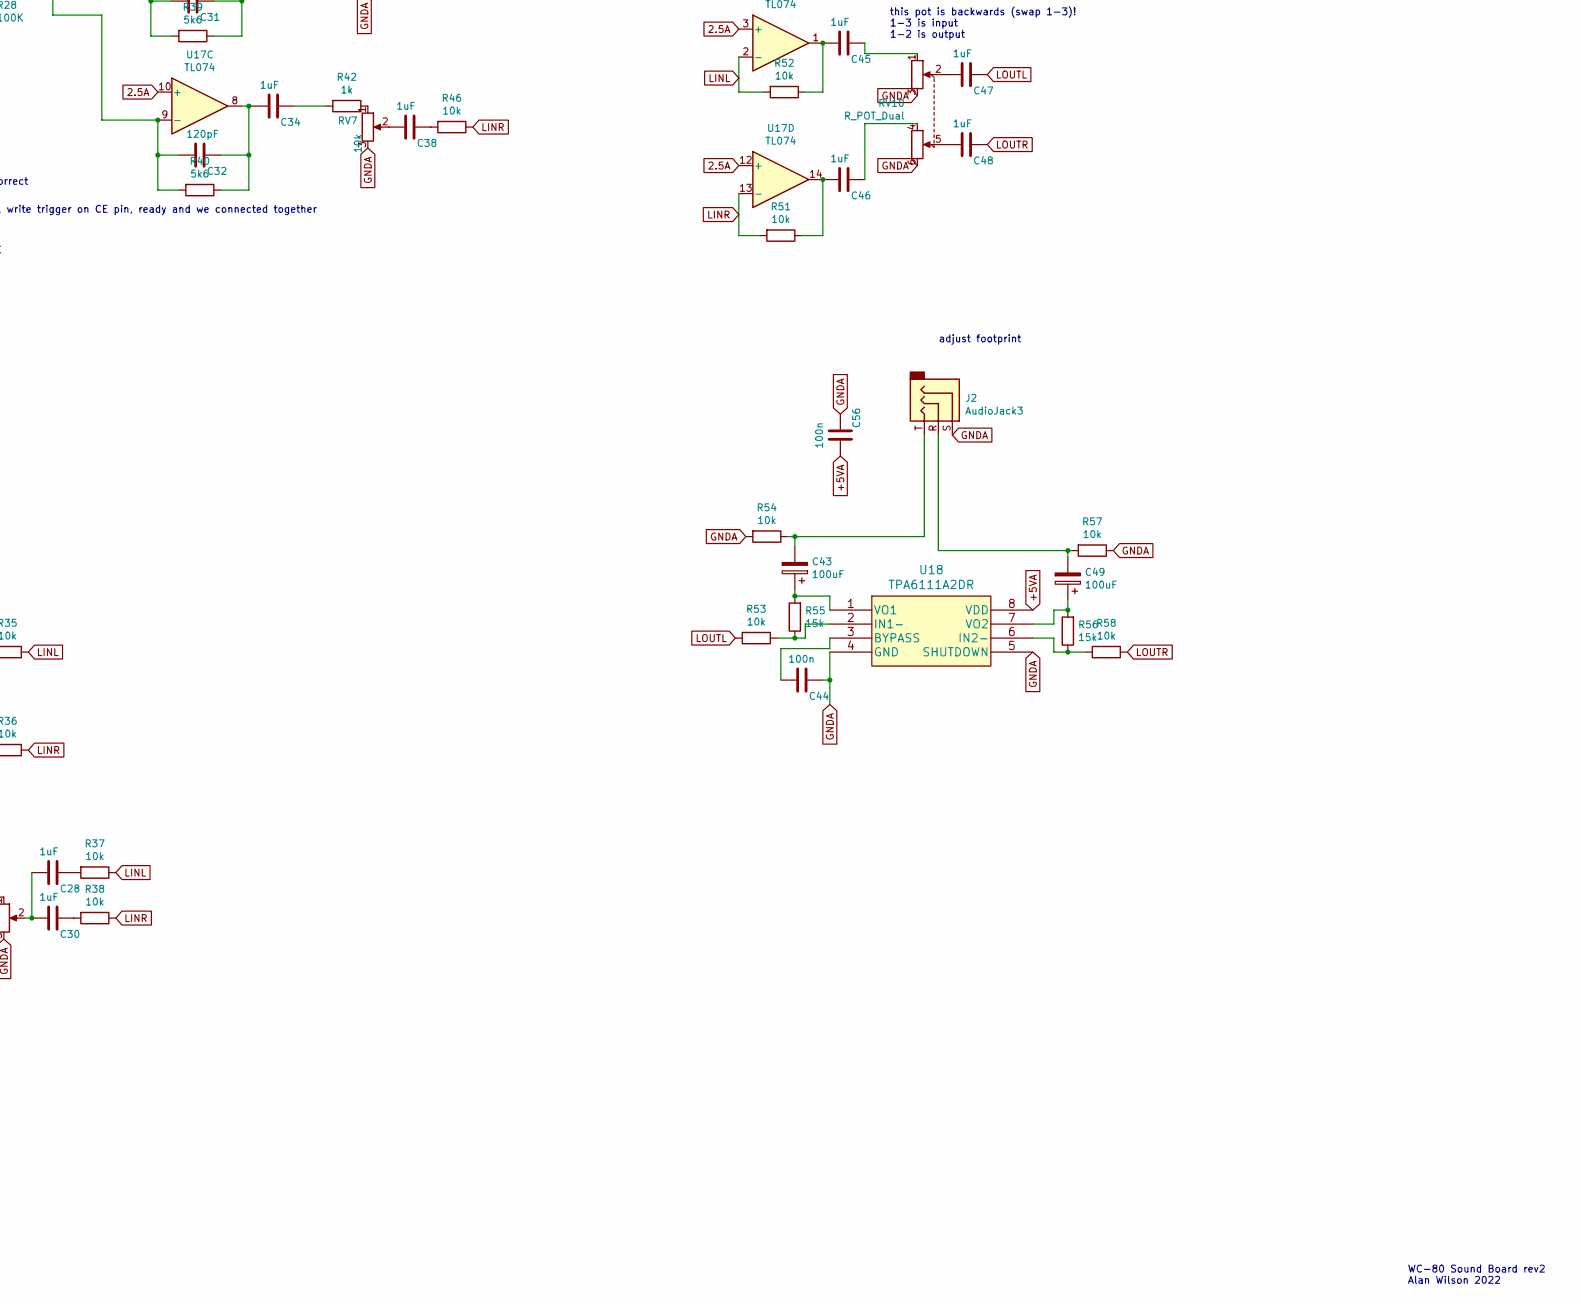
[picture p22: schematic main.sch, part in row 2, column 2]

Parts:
C1, C4, C41: 470uF; CP_Radial_D8.0mm_P3.50mm
C2, C3, C5, C12, C16, C17, C18, C19, C21, C22, C29, C44, C50, C51, C52, C53, C54, C55, C56, C57: 100n; C_0805_2012Metric
C6: 68pF; C_0805_2012Metric
C7, C24, C25, C42: 10uF; C_0805_2012Metric
C8, C9: 2.7nF; C_0805_2012Metric
C10, C11, C13, C14, C15, C20, C23, C26, C27, C28, C30, C33, C34, C35, C36, C37, C38, C39, C40, C45, C46, C47, C48: 1uF; C_0805_2012Metric
C31, C32: 120pF; C_0805_2012Metric
C43, C49: 100uF; CP_Elec_6.3x5.4
D1: LED; LED_D3.0mm
J1, J4: Conn_02x04_Odd_Even; PinHeader_2x04_P2.54mm_Vertical
J2: AudioJack3; SWITCHCRAFT_35RAPC4BHN2
J3: TRS80W-header; PinHeader_2x20_P2.54mm_Vertical
L1: 100uH; SWPA5040S
M1, M2, M3, M4: 3mm-mounting-hole; MountingHole_3.2mm_M3_DIN965
Q2: BSS138; SOT-23
R2, R4, R6, R7, R8, R9, R10, R49, R50: 10K; R_0805_2012Metric
R3: 100; R_0805_2012Metric
R5, R17, R18, R19, R20: 2k2; R_0805_2012Metric
R11: 680; R_0805_2012Metric
R12: 33; R_0805_2012Metric
R13, R14, R15, R16: 1000; R_0805_2012Metric
R21, R22: 4k7; R_0805_2012Metric
R23, R24: 47k; R_0805_2012Metric
R25, R26, R39, R40: 5k6; R_0805_2012Metric
R27, R28: 100K; R_0805_2012Metric
R29, R30, R31, R34, R41, R42, R43, R44: 1k; R_0805_2012Metric
R32, R33, R35, R36, R37, R38, R45, R46, R47, R48, R51, R52, R53, R54, R57, R58: 10k; R_0805_2012Metric
R55, R56: 15k; R_0805_2012Metric
RV1: 100k; 3362P-1-103LF
RV2, RV3, RV4, RV5, RV6, RV7, RV8, RV9: 10k; 3362P-1-103LF
RV10: R_POT_Dual; Potentiometer_Alps_RK097_Dual_Horizontal
U1: YMF262-M-OPL3; SOIC-24W_7.5x15.4mm_P1.27mm
U2: YAC512-M-OPL3; SOIC-16W_5.3x10.2mm_P1.27mm
U3, U19: 74LS273; SO-20_5.3x12.6mm_P1.27mm
U4: 74LS175; SOIC-16_3.9x9.9mm_P1.27mm
U5: AD7302; SOIC-20W_7.5x12.8mm_P1.27mm
U6: 74LS125; SOIC-14_3.9x8.7mm_P1.27mm
U7: SN76489; DIP-16_W7.62mm_Socket
U8: 74LS00; SOIC-14_3.9x8.7mm_P1.27mm
U9: YM2413; DIP-18_W7.62mm_Socket
U10: YM2612; DIP-24_W15.24mm_Socket
U11, U12, U13, U14: LTC6903; MSOP-8_3x3mm_P0.65mm
U15: CF-CARD; UMAX CFH-L3C1LBL01MN0
U16: TL074
U17: TL074; SOIC-14_3.9x8.7mm_P1.27mm
U18: TPA6111A2DR; SOIC-8_3.9x4.9mm_P1.27mm
U22: ATF22V10C; DIP-24_W7.62mm_Socket

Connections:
2.5A: C42.1, R49.2, R50.1, U17.3 (+), U17.5 (+), U17.10 (+), U17.12 (+)
+5V: C1.1, C2.1, C3.1, C4.1, C16.1, C17.1, C18.1, C19.1, C21.1, C22.1, C29.1, C51.1, C52.1, C53.1, C54.1, C55.1, C57.1, J3.40 (+5V), J4.1, J4.3, L1.2, R2.1, R4.1, R6.1, R7.1, R8.1, R9.1, R10.1, R11.1, U1.1 (VDD), U3.1 (~Mr), U3.20 (VCC), U4.1 (~Mr), U4.16 (VCC), U5.12 (~PD~), U5.14 (~CLR~), U5.15 (VDD), U5.16 (REFIN), U6.2, U6.5, U6.14 (VCC), U7.16 (Vcc), U8.14 (VCC), U9.16 (VCC), U10.23 (Vcc), U11.7 (OE), U11.8 (V+), U12.7 (OE), U12.8 (V+), U13.7 (OE), U13.8 (V+), U14.7 (OE), U14.8 (V+), U15.13 (VCC), U15.38 (VCC), U19.1 (~Mr), U19.20 (VCC), U22.24 (VCC)
+5VA: C5.2, C12.2, C41.1, C50.2, C56.2, L1.1, R49.1, U2.1 (VDD), U2.3 (VDD), U2.6 (FSEL), U2.9 (TST1), U10.22 (AVcc), U16.4 (V+), U17.4 (V+), U18.8 (VDD)
CASS: U4.9 (Cp), U22.20 (14_20)
CLK0SEL: U3.6 (Q2), U12.4 (~SEN~)
CLK1SEL: U3.9 (Q3), U13.4 (~SEN~)
CLK2SEL: U3.12 (Q4), U14.4 (~SEN~)
CLK3SEL: U3.15 (Q5), U11.4 (~SEN~)
D7C: U5.1 (D7), U22.23 (8_23)
F_A1: J3.28 (A1), U1.5 (A1), U10.18 (A1), U15.19 (A1), U22.4
F_A3: J3.33 (A3), U22.6
F_A4: J3.32 (A4), U22.7
F_A5: J3.36 (A5), U22.8
F_A6: J3.37 (A6), U22.9
F_A7: J3.35 (A7), U22.10
F_D0: J3.29 (D0), U1.10 (D0), U3.3 (D0), U4.4 (D0), U4.5 (D1), U5.8 (D0), U6.11, U7.10 (D0), U9.17 (D0), U10.2 (D0), U15.21 (D0), U19.2 (Q0), U19.3 (D0)
F_D1: J3.21 (D1), U1.11 (D1), U3.4 (D1), U4.12 (D2), U4.13 (D3), U5.7 (D1), U6.8, U7.11 (D1), U9.18 (D1), U10.3 (D1), U15.22 (D1), U19.4 (D1), U19.5 (Q1)
F_D2: J3.31 (D2), U1.13 (D2), U3.7 (D2), U5.6 (D2), U6.6, U7.12 (D2), U9.2 (D2), U10.4 (D2), U15.23 (D2), U19.6 (Q2), U19.7 (D2)
F_D3: J3.25 (D3), U1.14 (D3), U3.8 (D3), U5.5 (D3), U6.3, U7.13 (D3), U9.3 (D3), U10.5 (D3), U15.2 (D3), U19.8 (D3), U19.9 (Q3)
F_D4: J3.17 (D4), U1.15 (D4), U3.13 (D4), U5.4 (D4), U7.15 (D4), U9.4 (D4), U10.6 (D4), U15.3 (D4), U19.12 (Q4), U19.13 (D4)
F_D5: J3.27 (D5), U1.16 (D5), U3.14 (D5), U5.3 (D5), U7.1 (D5), U9.5 (D5), U10.7 (D5), U15.4 (D5), U19.14 (D5), U19.15 (Q5)
F_D6: J3.23 (D6), U1.17 (D6), U3.17 (D6), U5.2 (D6), U7.2 (D6), U9.6 (D6), U10.8 (D6), U15.5 (D6), U19.16 (Q6), U19.17 (D6)
F_D7: J3.19 (D7), U1.18 (D7), U3.18 (D7), U7.3 (D7), U9.7 (D7), U10.9 (D7), U15.6 (D7), U19.18 (D7), U19.19 (Q7), U22.11
F_WAIT: J3.34 (~WAIT~); also elsewhere on the board
LINL: R32.1, R35.1, R37.1, R45.1, R47.1, R52.2, U17.2 (-)
LINR: R33.1, R36.1, R38.1, R46.1, R48.1, R51.2, U17.13 (-)
LOUTL: C47.1, R53.2
LOUTR: C48.1, R58.1
unnamed: C6.1, U2.13 (AOUT), U16.5 (+)
unnamed: C7.2, U2.16 (CV), U16.3 (+)
unnamed: C8.1, U2.11 (CH2), U16.12 (+)
unnamed: C9.1, U2.10 (CH1), U16.10 (+)
unnamed: C10.1, R29.2
unnamed: C10.2, R13.1, R14.1, R15.1, R16.1
unnamed: C11.1, R30.2
unnamed: C11.2, U5.19 (VOUTA)
unnamed: C13.1, R31.2
unnamed: C13.2, U5.18 (VOUTB)
unnamed: C14.1, R5.1, U7.7 (SN_OUT)
unnamed: C14.2, RV1.1
unnamed: C15.1, R32.2
unnamed: C15.2, C20.2, RV2.2
unnamed: C20.1, R33.2
unnamed: C23.1, R34.2
unnamed: C23.2, R21.1, R22.1
unnamed: C24.1, R23.1
unnamed: C24.2, R19.2, U10.21 (MOL)
unnamed: C25.1, R24.1
unnamed: C25.2, R17.2, U10.20 (MOR)
unnamed: C26.1, R35.2
unnamed: C26.2, RV3.2
unnamed: C27.1, R36.2
unnamed: C27.2, RV4.2
unnamed: C28.1, R37.2
unnamed: C28.2, C30.2, RV5.2
unnamed: C30.1, R38.2
unnamed: C31.1, C33.2, R39.1, U17.7
unnamed: C31.2, R25.2, R28.1, R39.2, U17.6 (-)
unnamed: C32.1, C34.2, R40.1, U17.8
unnamed: C32.2, R26.2, R27.2, R40.2, U17.9 (-)
unnamed: C33.1, R41.2
unnamed: C34.1, R42.2
unnamed: C35.1, R43.2
unnamed: C35.2, U16.13 (-), U16.14
unnamed: C36.1, R44.2
unnamed: C36.2, U16.8, U16.9 (-)
unnamed: C37.1, R45.2
unnamed: C37.2, RV6.2
unnamed: C38.1, R46.2
unnamed: C38.2, RV7.2
unnamed: C39.1, R47.2
unnamed: C39.2, RV8.2
unnamed: C40.1, R48.2
unnamed: C40.2, RV9.2
unnamed: C43.1, R55.2, U18.1 (VO1)
unnamed: C43.2, J2.T, R54.1
unnamed: C44.2, U18.3 (BYPASS)
unnamed: C45.1, RV10.1
unnamed: C45.2, R52.1, U17.1
unnamed: C46.1, RV10.4
unnamed: C46.2, R51.1, U17.14
unnamed: C47.2, RV10.2
unnamed: C48.2, RV10.5
unnamed: C49.1, R56.2, U18.7 (VO2)
unnamed: C49.2, J2.R, R57.2
unnamed: D1.1 (K), U15.45 (~DASP~)
unnamed: D1.2 (A), R11.2
unnamed: Q2.1 (G), R3.1
unnamed 115: U8.11, U19.11 (Cp); also elsewhere on the board
unnamed: R2.2, U1.2 (IRQ), U6.12, U8.9
unnamed: R3.2, U8.8
unnamed: R6.2, U6.9, U8.10, U10.13 (IRQ)
unnamed: R7.2, U15.32 (~CS1~)
unnamed: R8.2, U15.36 (~WE~)
unnamed: R9.2, U15.44 (~DMACK~)
unnamed: R10.2, U15.46 (~PDIAG~)
unnamed: R12.1, U2.12 (SWIN)
unnamed: R12.2, U16.6 (-), U16.7
unnamed: R13.2, U4.2 (Q0)
unnamed: R14.2, U4.7 (Q1)
unnamed: R15.2, U4.11 (~Q2)
unnamed: R16.2, U4.14 (~Q3)
unnamed: R18.2, R21.2, U9.15 (RO)
unnamed: R20.2, R22.2, U9.14 (MO)
unnamed: R23.2, R25.1
unnamed: R24.2, R26.1
unnamed: R27.1, R28.2, RV1.2
unnamed: R29.1, RV2.1
unnamed: R30.1, RV3.1
unnamed: R31.1, RV4.1
unnamed: R34.1, RV5.1
unnamed: R41.1, RV6.1
unnamed: R42.1, RV7.1
unnamed: R43.1, RV8.1
unnamed: R44.1, RV9.1
unnamed: R53.1, R55.1, U18.2 (IN1-)
unnamed: R56.1, R58.2, U18.6 (IN2-)
unnamed: U1.19 (SMPBD), U2.8 (SMP1)
unnamed: U1.20 (SMPAC), U2.7 (SMP2)
unnamed: U1.21 (DOAB), U2.4 (DIN)
unnamed: U1.23 (ØSY), U2.5 (CLK)
unnamed: U2.14 (MP), U16.1, U16.2 (-)
OPT: U3.11 (Cp), U22.15 (10_15)
SCK: U3.5 (Q1), U11.3 (SCK), U12.3 (SCK), U13.3 (SCK), U14.3 (SCK)
SDI: U3.2 (Q0), U11.2 (SDI), U12.2 (SDI), U13.2 (SDI), U14.2 (SDI)
clk0: U7.14 (CLOCK_IN), U12.6 (CLK)
clk1: U9.8 (XIN), U13.6 (CLK)
clk2: U10.24 (CLOCK_IN), U14.6 (CLK)
clk3: U1.24 (ØM), U11.6 (CLK)
~2413~: U9.12 (~CS~), U22.18 (16_18)
~2612~: U10.14 (CS), U22.17 (14_17)
~CFCARD~: U15.7 (~CS0~), U22.22 (10_22)
~CFRESET~: U3.16 (Q6), U15.41 (~RESET~)
~DAC~: U5.9 (~CS~), U22.21 (12_21)
~F_INT~: J3.22 (~INT~), Q2.3 (D)
~F_IN~: J3.20 (~IN~), U1.7 (RD), U10.16 (RD), U15.34 (~IORD~), U22.2
~F_OUT~: J3.11 (~OUT~), U1.6 (WR), U5.10 (~WR~), U9.11 (~WE~), U10.15 (WR), U15.35 (~IOWR~), U22.1
~INTREAD~: U6.1, U6.4, U6.10, U6.13, U22.14 (8_14)
~OPL3~: U1.8 (CS), U22.16 (12_16)
~RESET~: U1.3 (IC), U3.19 (Q7), U9.13 (~IC~), U10.11 (IC)

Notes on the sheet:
WC-80 Sound Board rev2 Alan Wilson 2022
adjust footprint
A/B pin connects to A2, not A0 or to A3 for reversed channel
this pot is backwards (swap 1-3)! 1-3 is input 1-2 is output
reversed bus seems to be correct
No wait states - latch data, write trigger on CE pin, ready and we connected together
some power noise from this chip

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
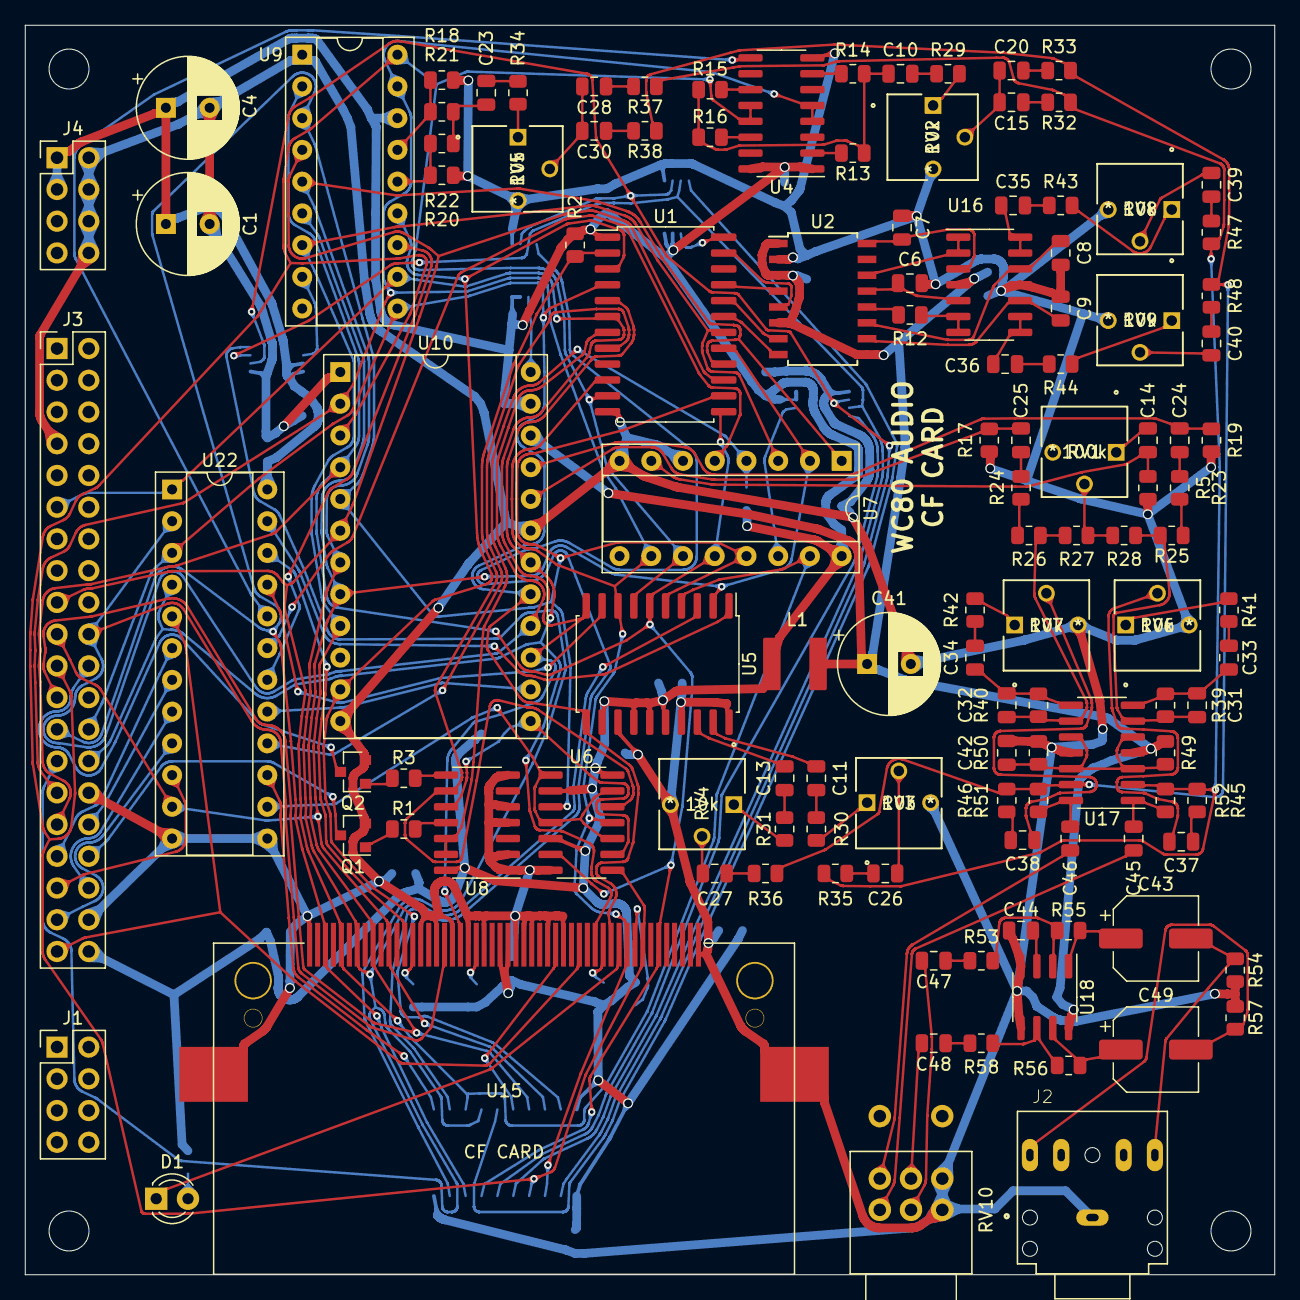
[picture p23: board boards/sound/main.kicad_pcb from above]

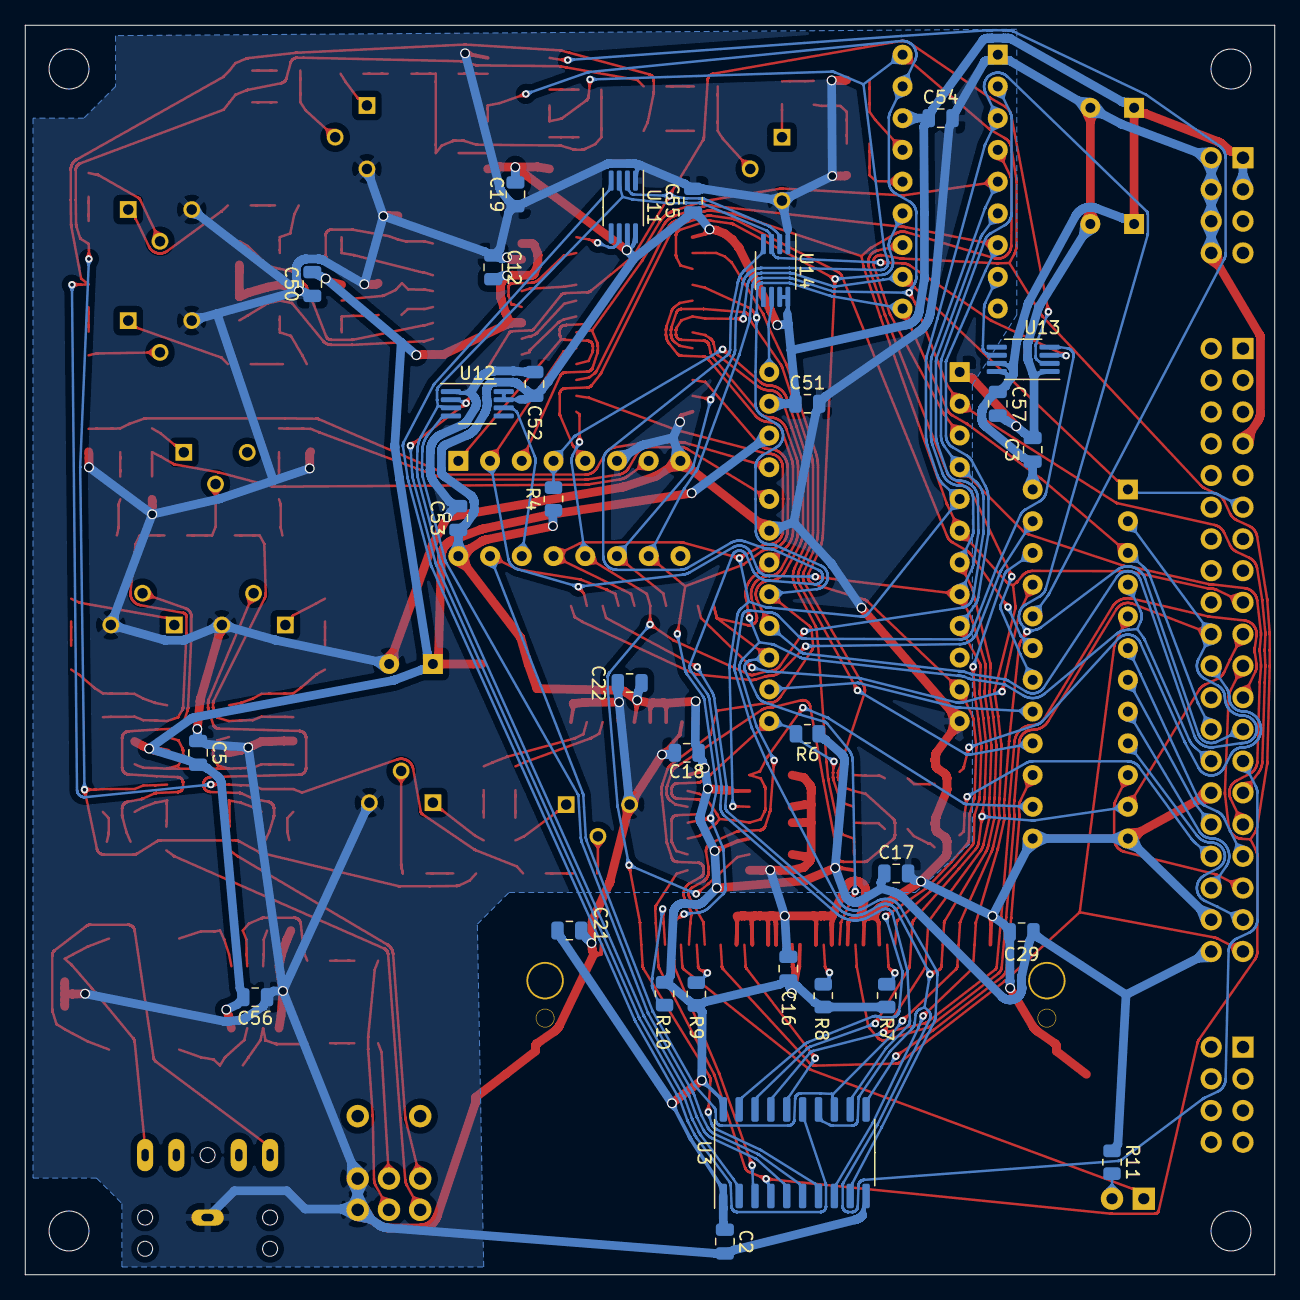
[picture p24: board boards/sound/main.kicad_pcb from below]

Board: 2 copper layers, 100.0 x 100.0 mm, 156 parts (31 on the bottom side), 146 nets.

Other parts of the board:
Q1: BSS138; SOT-23
R1: 100; R_0805_2012Metric

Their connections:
F_WAIT: Q1.3; also elsewhere on the board
unnamed: Q1.1, R1.1
unnamed 115: R1.2; also elsewhere on the board

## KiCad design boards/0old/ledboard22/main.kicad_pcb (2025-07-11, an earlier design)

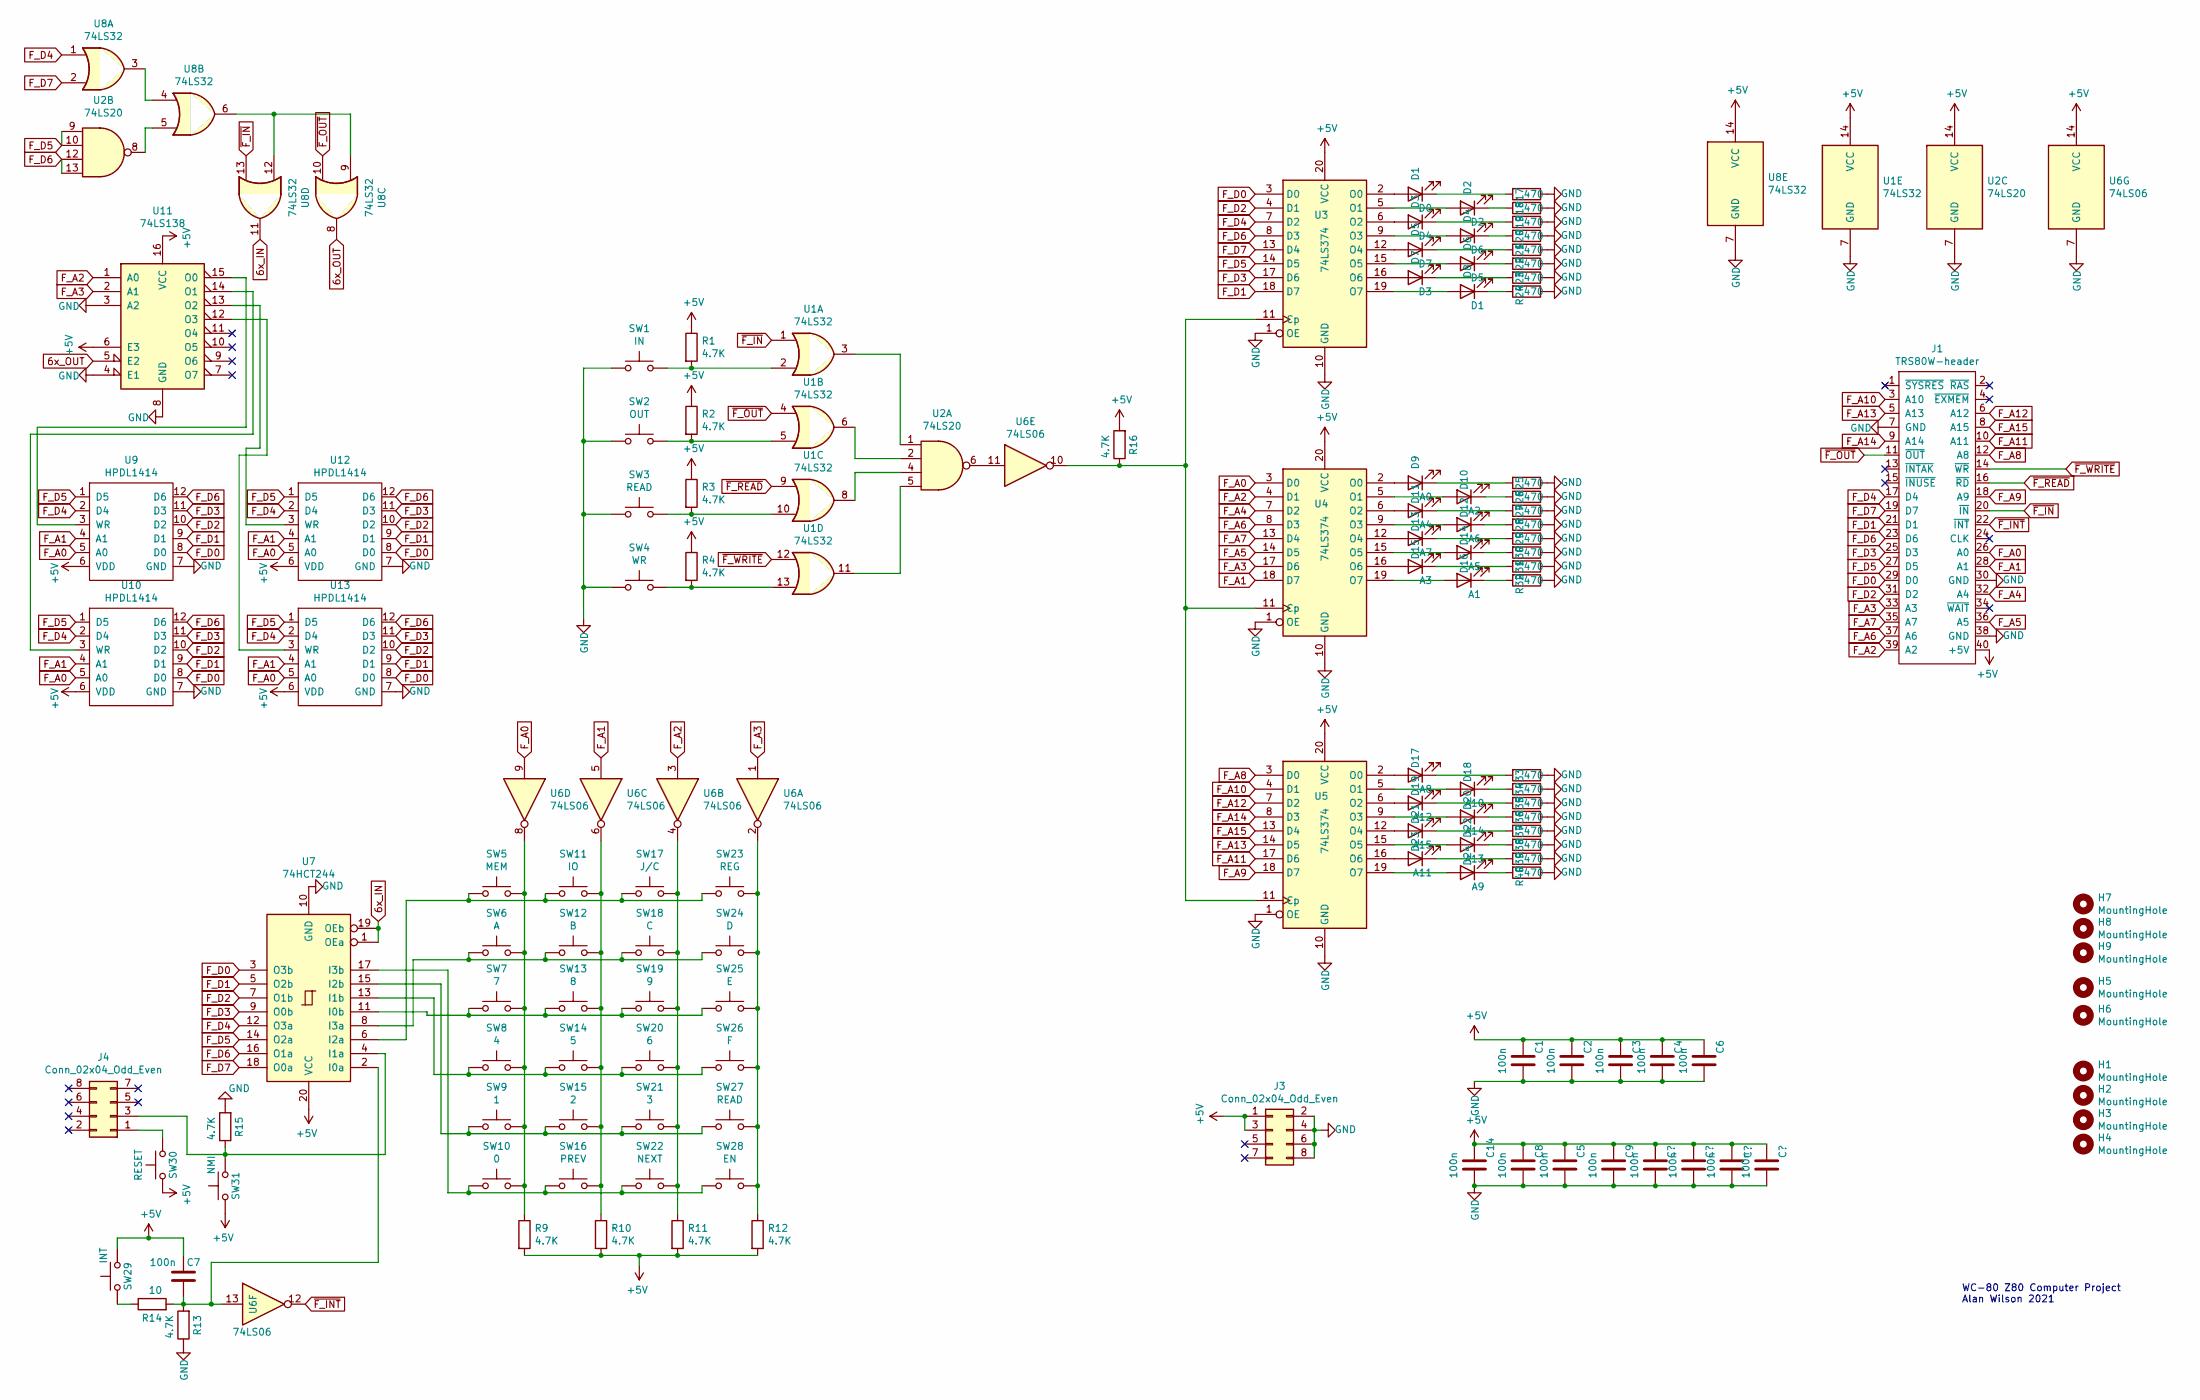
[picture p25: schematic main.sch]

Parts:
C1, C2, C3, C4, C5, C6, C7, C8, C9, C14: 100n; C_0805_2012Metric
D1: D0; LED_D3.0mm_FlatTop
D2: D2; LED_D3.0mm_FlatTop
D3: D4; LED_D3.0mm_FlatTop
D4: D6; LED_D3.0mm_FlatTop
D5: D7; LED_D3.0mm_FlatTop
D6: D5; LED_D3.0mm_FlatTop
D7: D3; LED_D3.0mm_FlatTop
D8: D1; LED_D3.0mm_FlatTop
D9: A0; LED_D3.0mm_FlatTop
D10: A2; LED_D3.0mm_FlatTop
D11: A4; LED_D3.0mm_FlatTop
D12: A6; LED_D3.0mm_FlatTop
D13: A7; LED_D3.0mm_FlatTop
D14: A5; LED_D3.0mm_FlatTop
D15: A3; LED_D3.0mm_FlatTop
D16: A1; LED_D3.0mm_FlatTop
D17: A8; LED_D3.0mm_FlatTop
D18: A10; LED_D3.0mm_FlatTop
D19: A12; LED_D3.0mm_FlatTop
D20: A14; LED_D3.0mm_FlatTop
D21: A15; LED_D3.0mm_FlatTop
D22: A13; LED_D3.0mm_FlatTop
D23: A11; LED_D3.0mm_FlatTop
D24: A9; LED_D3.0mm_FlatTop
H1, H2, H3, H4, H5, H6, H7, H8, H9: MountingHole; MountingHole_3.2mm_M3_DIN965
J1: TRS80W-header; PinHeader_2x20_P2.54mm_Vertical
J3, J4: Conn_02x04_Odd_Even; PinHeader_2x04_P2.54mm_Vertical
R1, R2, R3, R4, R9, R10, R11, R12, R13, R15, R16: 4.7K; R_0805_2012Metric
R14: 10; R_0805_2012Metric
R17, R18, R19, R20, R21, R22, R23, R24, R25, R26, R27, R28, R29, R30, R31, R32, R33, R34, R35, R36, R37, R38, R39, R40: 470; R_0805_2012Metric
SW1: IN; 8.5x8.5-DPDT-SP
SW2: OUT; 8.5x8.5-DPDT-SP
SW3, SW27: READ; 8.5x8.5-DPDT-SP
SW4: WR; 8.5x8.5-DPDT-SP
SW5: MEM; 8.5x8.5-DPDT-SP
SW6: A; 8.5x8.5-DPDT-SP
SW7: 7; 8.5x8.5-DPDT-SP
SW8: 4; 8.5x8.5-DPDT-SP
SW9: 1; 8.5x8.5-DPDT-SP
SW10: 0; 8.5x8.5-DPDT-SP
SW11: IO; 8.5x8.5-DPDT-SP
SW12: B; 8.5x8.5-DPDT-SP
SW13: 8; 8.5x8.5-DPDT-SP
SW14: 5; 8.5x8.5-DPDT-SP
SW15: 2; 8.5x8.5-DPDT-SP
SW16: PREV; 8.5x8.5-DPDT-SP
SW17: J/C; 8.5x8.5-DPDT-SP
SW18: C; 8.5x8.5-DPDT-SP
SW19: 9; 8.5x8.5-DPDT-SP
SW20: 6; 8.5x8.5-DPDT-SP
SW21: 3; 8.5x8.5-DPDT-SP
SW22: NEXT; 8.5x8.5-DPDT-SP
SW23: REG; 8.5x8.5-DPDT-SP
SW24: D; 8.5x8.5-DPDT-SP
SW25: E; 8.5x8.5-DPDT-SP
SW26: F; 8.5x8.5-DPDT-SP
SW28: EN; 8.5x8.5-DPDT-SP
SW29: INT; 8.5x8.5-DPDT-SP
SW30: RESET; 8.5x8.5-DPDT-SP
SW31: NMI; 8.5x8.5-DPDT-SP
U1, U8: 74LS32; SOIC-14_3.9x8.7mm_P1.27mm
U2: 74LS20; SOIC-14_3.9x8.7mm_P1.27mm
U3, U4, U5: 74LS374; SOIC-20W_7.5x12.8mm_P1.27mm
U6: 74LS06; SOIC-14_3.9x8.7mm_P1.27mm
U7: 74HCT244; SOIC-20W_7.5x12.8mm_P1.27mm
U9, U10, U12, U13: HPDL1414; DIP-24_W15.24mm_Socket
U11: 74LS138; SOIC-16_3.9x9.9mm_P1.27mm

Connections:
6x_IN: U7.1 (OEa), U7.19 (OEb), U8.11
6x_OUT: U8.8, U11.5 (E2)
+5V: C1.1, C2.1, C3.1, C4.1, C5.1, C6.1, C7.2, C8.1, C9.1, C14.1, J1.40 (+5V), J3.1, J3.3, R1.1, R2.1, R3.1, R4.1, R9.2, R10.2, R11.2, R12.2, R16.2, SW29.2, SW30.1, SW31.1, U1.14 (VCC), U2.14 (VCC), U3.20 (VCC), U4.20 (VCC), U5.20 (VCC), U6.14 (VCC), U7.20 (VCC), U8.14 (VCC), U9.6 (VDD), U10.6 (VDD), U11.6 (E3), U11.16 (VCC), U12.6 (VDD), U13.6 (VDD); also elsewhere on the board
F_A0: J1.26 (A0), U4.3 (D0), U6.9, U9.5 (A0), U10.5 (A0), U12.5 (A0), U13.5 (A0)
F_A1: J1.28 (A1), U4.18 (D7), U6.5, U9.4 (A1), U10.4 (A1), U12.4 (A1), U13.4 (A1)
F_A2: J1.39 (A2), U4.4 (D1), U6.3, U11.1 (A0)
F_A3: J1.33 (A3), U4.17 (D6), U6.1, U11.2 (A1)
F_A4: J1.32 (A4), U4.7 (D2)
F_A5: J1.36 (A5), U4.14 (D5)
F_A6: J1.37 (A6), U4.8 (D3)
F_A7: J1.35 (A7), U4.13 (D4)
F_A8: J1.12 (A8), U5.3 (D0)
F_A9: J1.18 (A9), U5.18 (D7)
F_A10: J1.3 (A10), U5.4 (D1)
F_A11: J1.10 (A11), U5.17 (D6)
F_A12: J1.6 (A12), U5.7 (D2)
F_A13: J1.5 (A13), U5.14 (D5)
F_A14: J1.9 (A14), U5.8 (D3)
F_A15: J1.8 (A15), U5.13 (D4)
F_D0: J1.29 (D0), U3.3 (D0), U7.3 (O3b), U9.8 (D0), U10.8 (D0), U12.8 (D0), U13.8 (D0)
F_D1: J1.21 (D1), U3.18 (D7), U7.5 (O2b), U9.9 (D1), U10.9 (D1), U12.9 (D1), U13.9 (D1)
F_D2: J1.31 (D2), U3.4 (D1), U7.7 (O1b), U9.10 (D2), U10.10 (D2), U12.10 (D2), U13.10 (D2)
F_D3: J1.25 (D3), U3.17 (D6), U7.9 (O0b), U9.11 (D3), U10.11 (D3), U12.11 (D3), U13.11 (D3)
F_D4: J1.17 (D4), U3.7 (D2), U7.12 (O3a), U8.1, U9.2 (D4), U10.2 (D4), U12.2 (D4), U13.2 (D4)
F_D5: J1.27 (D5), U2.9, U2.10, U3.14 (D5), U7.14 (O2a), U9.1 (D5), U10.1 (D5), U12.1 (D5), U13.1 (D5)
F_D6: J1.23 (D6), U2.12, U2.13, U3.8 (D3), U7.16 (O1a), U9.12 (D6), U10.12 (D6), U12.12 (D6), U13.12 (D6)
F_D7: J1.19 (D7), U3.13 (D4), U7.18 (O0a), U8.2
GND: C1.2, C2.2, C3.2, C4.2, C5.2, C6.2, C8.2, C9.2, C14.2, J1.7 (GND), J1.30 (GND), J1.38 (GND), J3.2, J3.4, J3.6, J3.8, R13.1, R15.2, R17.1, R18.1, R19.1, R20.1, R21.1, R22.1, R23.1, R24.1, R25.1, R26.1, R27.1, R28.1, R29.1, R30.1, R31.1, R32.1, R33.1, R34.1, R35.1, R36.1, R37.1, R38.1, R39.1, R40.1, SW1.1, SW2.1, SW3.1, SW4.1, U1.7 (GND), U2.7 (GND), U3.1 (OE), U3.10 (GND), U4.1 (OE), U4.10 (GND), U5.1 (OE), U5.10 (GND), U6.7 (GND), U7.10 (GND), U8.7 (GND), U9.7 (GND), U10.7 (GND), U11.3 (A2), U11.4 (E1), U11.8 (GND), U12.7 (GND), U13.7 (GND); also elsewhere on the board
unnamed: C7.1, R13.2, R14.2, U6.13, U7.2 (I0a)
unnamed: D1.1 (K), R17.2
unnamed: D1.2 (A), U3.2 (O0)
unnamed: D2.1 (K), R18.2
unnamed: D2.2 (A), U3.5 (O1)
unnamed: D3.1 (K), R19.2
unnamed: D3.2 (A), U3.6 (O2)
unnamed: D4.1 (K), R20.2
unnamed: D4.2 (A), U3.9 (O3)
unnamed: D5.1 (K), R21.2
unnamed: D5.2 (A), U3.12 (O4)
unnamed: D6.1 (K), R22.2
unnamed: D6.2 (A), U3.15 (O5)
unnamed: D7.1 (K), R23.2
unnamed: D7.2 (A), U3.16 (O6)
unnamed: D8.1 (K), R24.2
unnamed: D8.2 (A), U3.19 (O7)
unnamed: D9.1 (K), R25.2
unnamed: D9.2 (A), U4.2 (O0)
unnamed: D10.1 (K), R26.2
unnamed: D10.2 (A), U4.5 (O1)
unnamed: D11.1 (K), R27.2
unnamed: D11.2 (A), U4.6 (O2)
unnamed: D12.1 (K), R28.2
unnamed: D12.2 (A), U4.9 (O3)
unnamed: D13.1 (K), R29.2
unnamed: D13.2 (A), U4.12 (O4)
unnamed: D14.1 (K), R30.2
unnamed: D14.2 (A), U4.15 (O5)
unnamed: D15.1 (K), R31.2
unnamed: D15.2 (A), U4.16 (O6)
unnamed: D16.1 (K), R32.2
unnamed: D16.2 (A), U4.19 (O7)
unnamed: D17.1 (K), R33.2
unnamed: D17.2 (A), U5.2 (O0)
unnamed: D18.1 (K), R34.2
unnamed: D18.2 (A), U5.5 (O1)
unnamed: D19.1 (K), R35.2
unnamed: D19.2 (A), U5.6 (O2)
unnamed: D20.1 (K), R36.2
unnamed: D20.2 (A), U5.9 (O3)
unnamed: D21.1 (K), R37.2
unnamed: D21.2 (A), U5.12 (O4)
unnamed: D22.1 (K), R38.2
unnamed: D22.2 (A), U5.15 (O5)
unnamed: D23.1 (K), R39.2
unnamed: D23.2 (A), U5.16 (O6)
unnamed: D24.1 (K), R40.2
unnamed: D24.2 (A), U5.19 (O7)
unnamed: J4.1, SW30.2
unnamed: J4.3, R15.1, SW31.2, U7.4 (I1a)
unnamed: R1.2, SW1.2, U1.2
unnamed: R2.2, SW2.2, U1.5
unnamed: R3.2, SW3.2, U1.10
unnamed: R4.2, SW4.2, U1.13
unnamed: R9.1, SW5.2, SW6.2, SW7.2, SW8.2, SW9.2, SW10.2, U6.8
unnamed: R10.1, SW11.2, SW12.2, SW13.2, SW14.2, SW15.2, SW16.2, U6.6
unnamed: R11.1, SW17.2, SW18.2, SW19.2, SW20.2, SW21.2, SW22.2, U6.4
unnamed: R12.1, SW23.2, SW24.2, SW25.2, SW26.2, SW27.2, SW28.2, U6.2
unnamed: R14.1, SW29.1
unnamed: R16.1, U3.11 (Cp), U4.11 (Cp), U5.11 (Cp), U6.10
unnamed: SW10.1, SW16.1, SW22.1, SW28.1, U7.17 (I3b)
unnamed: SW5.1, SW11.1, SW17.1, SW23.1, U7.6 (I2a)
unnamed: SW6.1, SW12.1, SW18.1, SW24.1, U7.8 (I3a)
unnamed: SW7.1, SW13.1, SW19.1, SW25.1, U7.11 (I0b)
unnamed: SW8.1, SW14.1, SW20.1, SW26.1, U7.13 (I1b)
unnamed: SW9.1, SW15.1, SW21.1, SW27.1, U7.15 (I2b)
unnamed: U1.3, U2.1
unnamed: U1.6, U2.2
unnamed: U1.8, U2.4
unnamed: U1.11, U2.5
unnamed: U2.6, U6.11
unnamed: U2.8, U8.5
unnamed: U8.3, U8.4
unnamed: U8.6, U8.9, U8.12
unnamed: U10.3 (WR), U11.14 (O1)
unnamed: U11.12 (O3), U13.3 (WR)
unnamed: U11.13 (O2), U12.3 (WR)
unnamed: U9.3 (WR), U11.15 (O0)
~F_INT~: J1.22 (~INT~), U6.12
~F_IN~: J1.20 (~IN~), U1.1, U8.13
~F_OUT~: J1.11 (~OUT~), U1.4, U8.10
~F_READ~: J1.16 (~RD~), U1.9
~F_WRITE~: J1.14 (~WR~), U1.12

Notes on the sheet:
WC-80 Z80 Computer Project Alan Wilson 2021

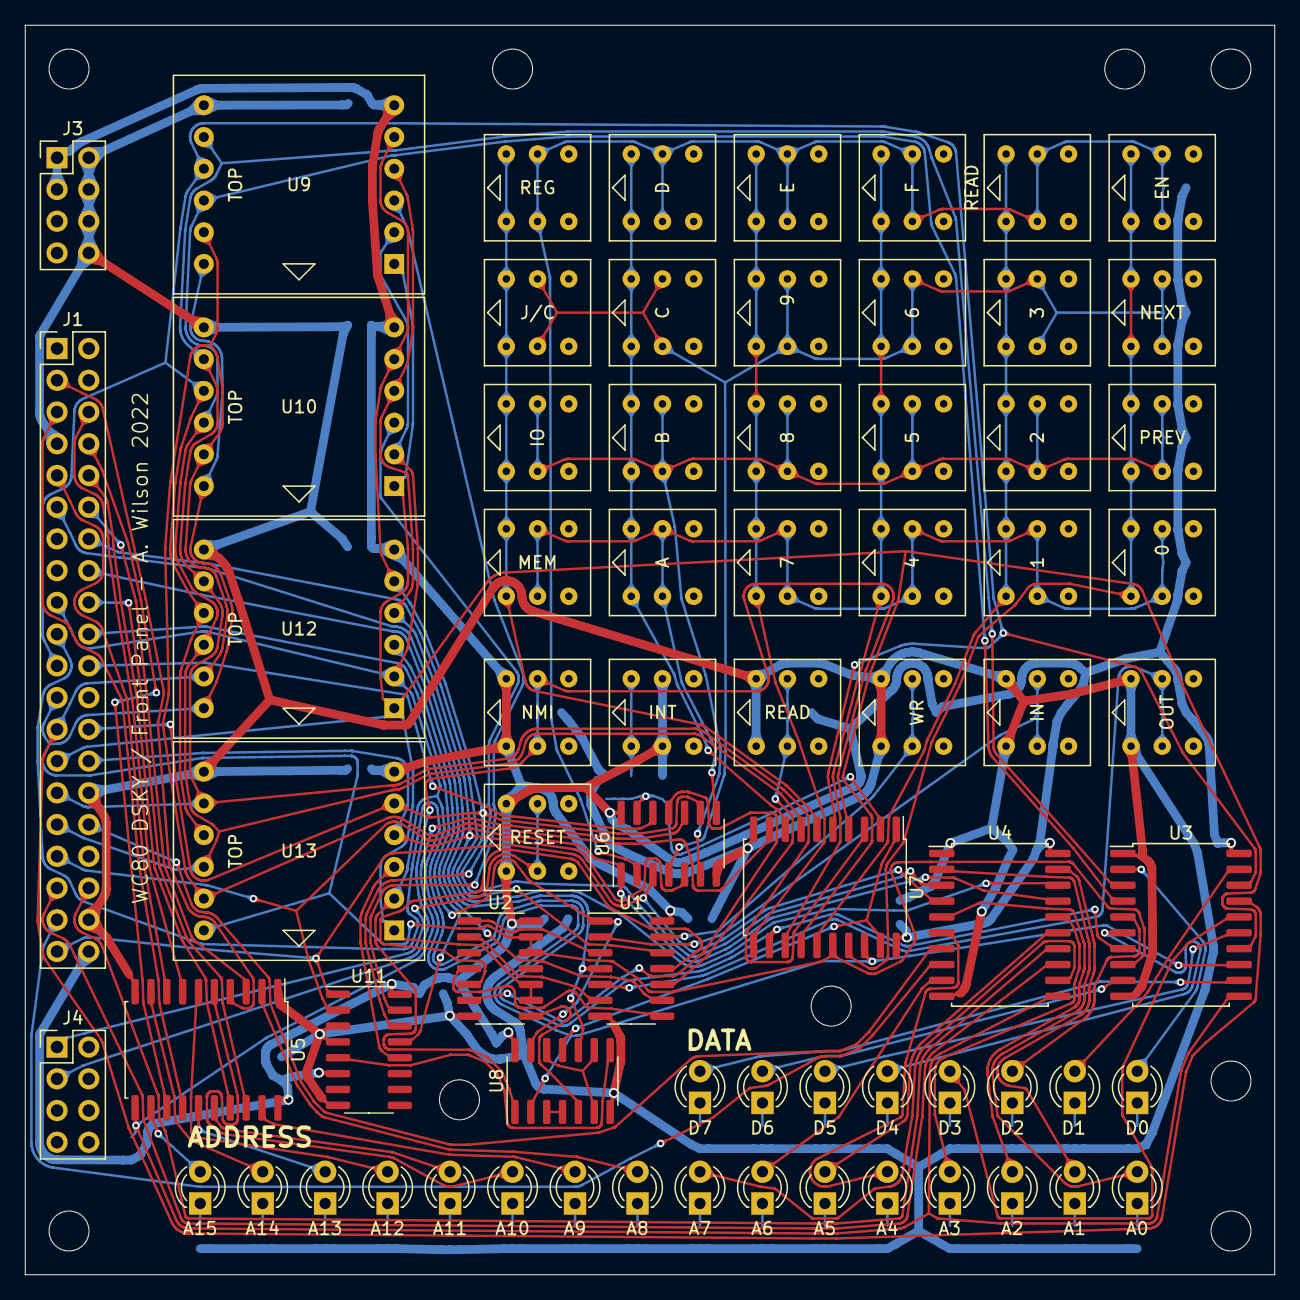
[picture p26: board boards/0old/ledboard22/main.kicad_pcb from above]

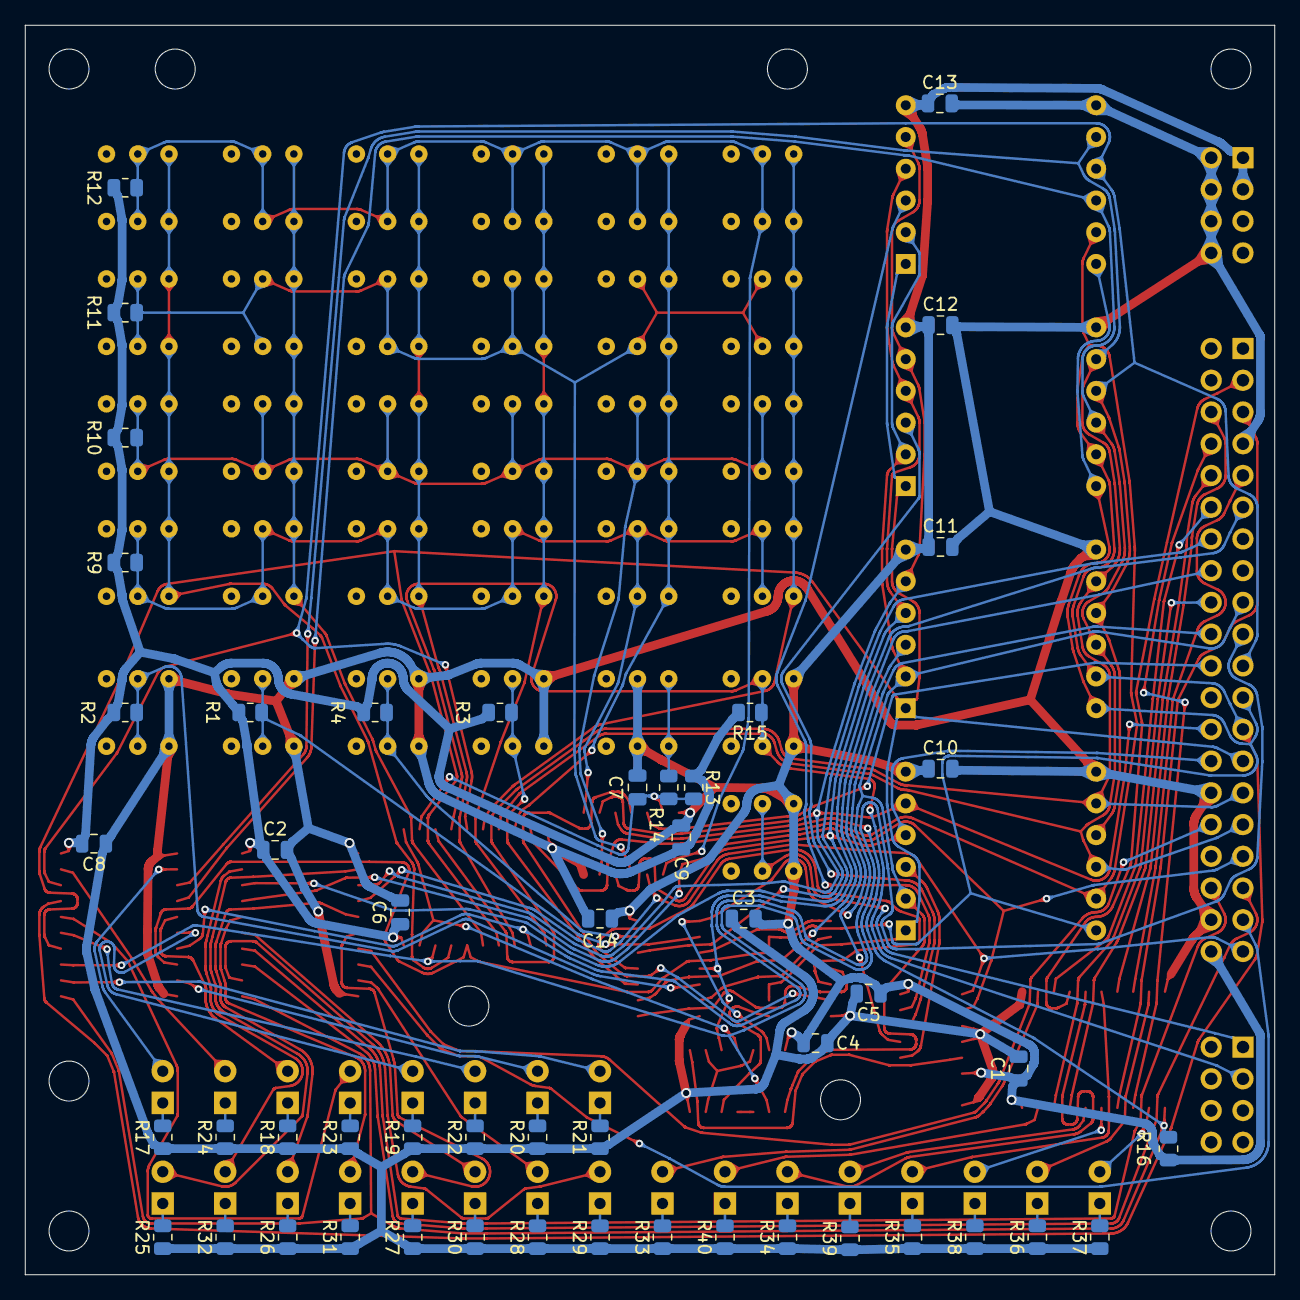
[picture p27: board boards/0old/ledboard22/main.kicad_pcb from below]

Board: 2 copper layers, 100.0 x 100.0 mm, 130 parts (50 on the bottom side), 112 nets.

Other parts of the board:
C10, C11, C12, C13: 100n; C_0805_2012Metric

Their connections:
+5V: C10.1, C11.1, C12.1, C13.1; also elsewhere on the board
GND: C10.2, C11.2, C12.2, C13.2; also elsewhere on the board

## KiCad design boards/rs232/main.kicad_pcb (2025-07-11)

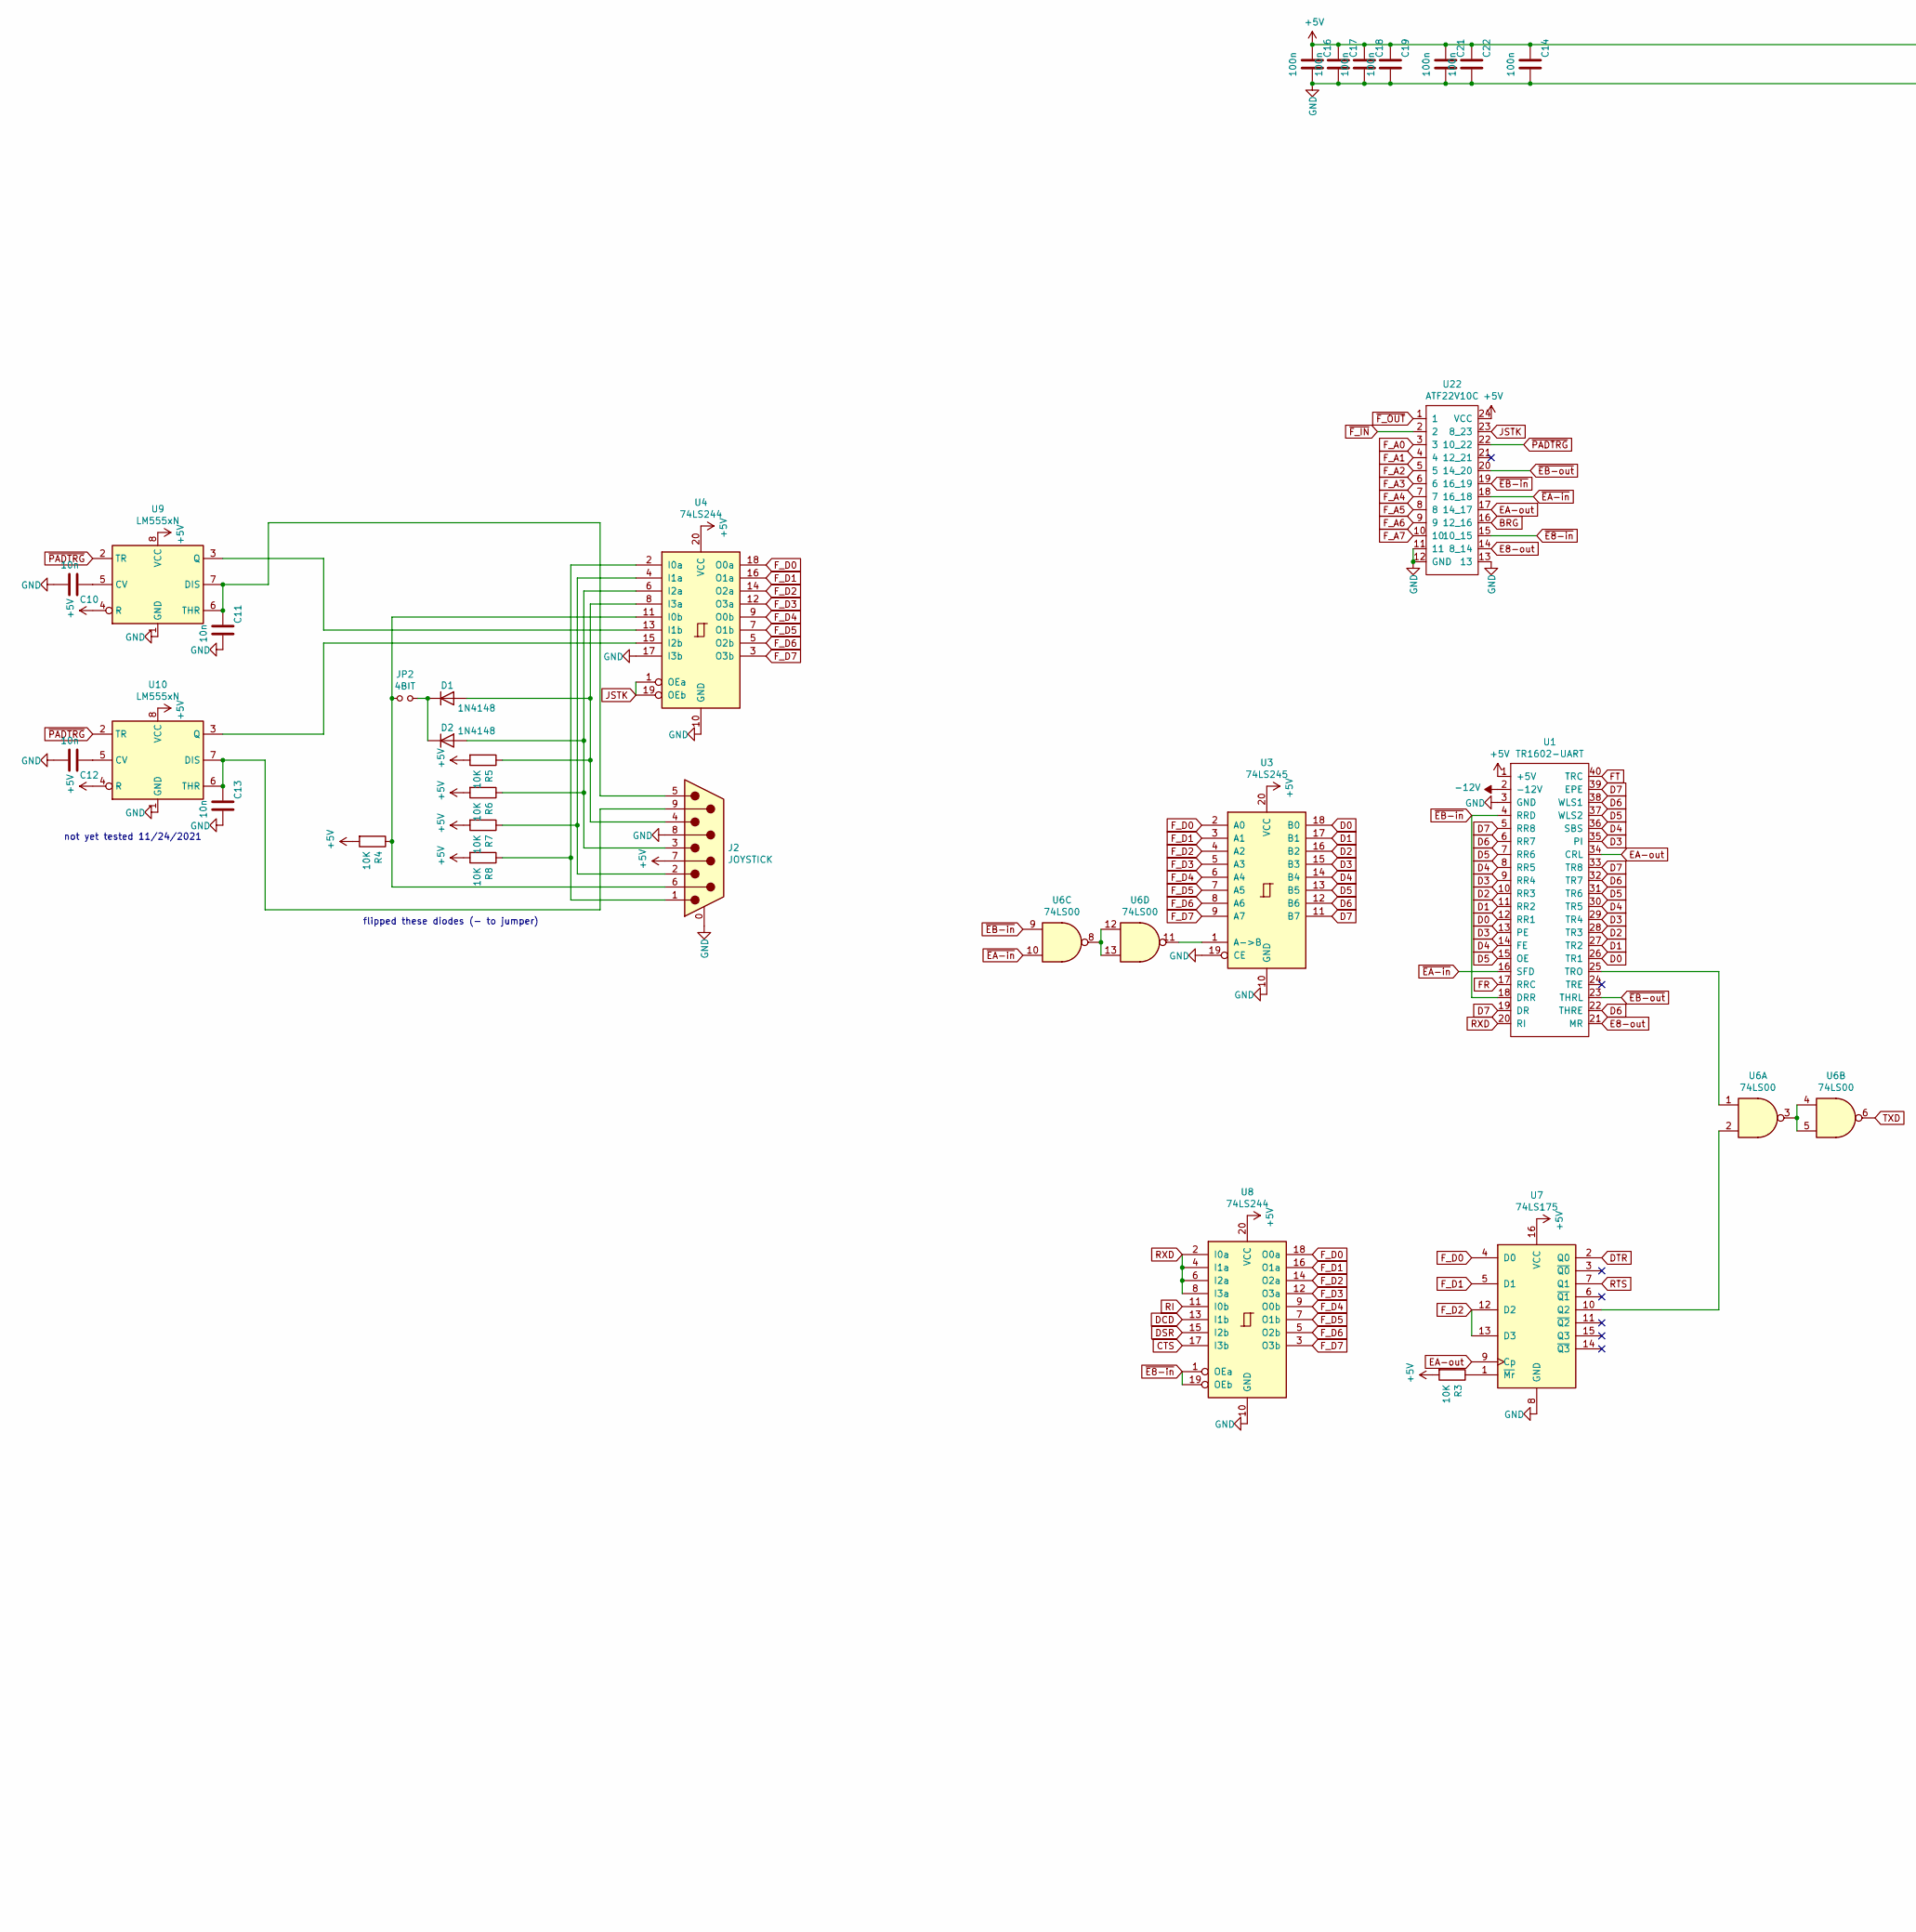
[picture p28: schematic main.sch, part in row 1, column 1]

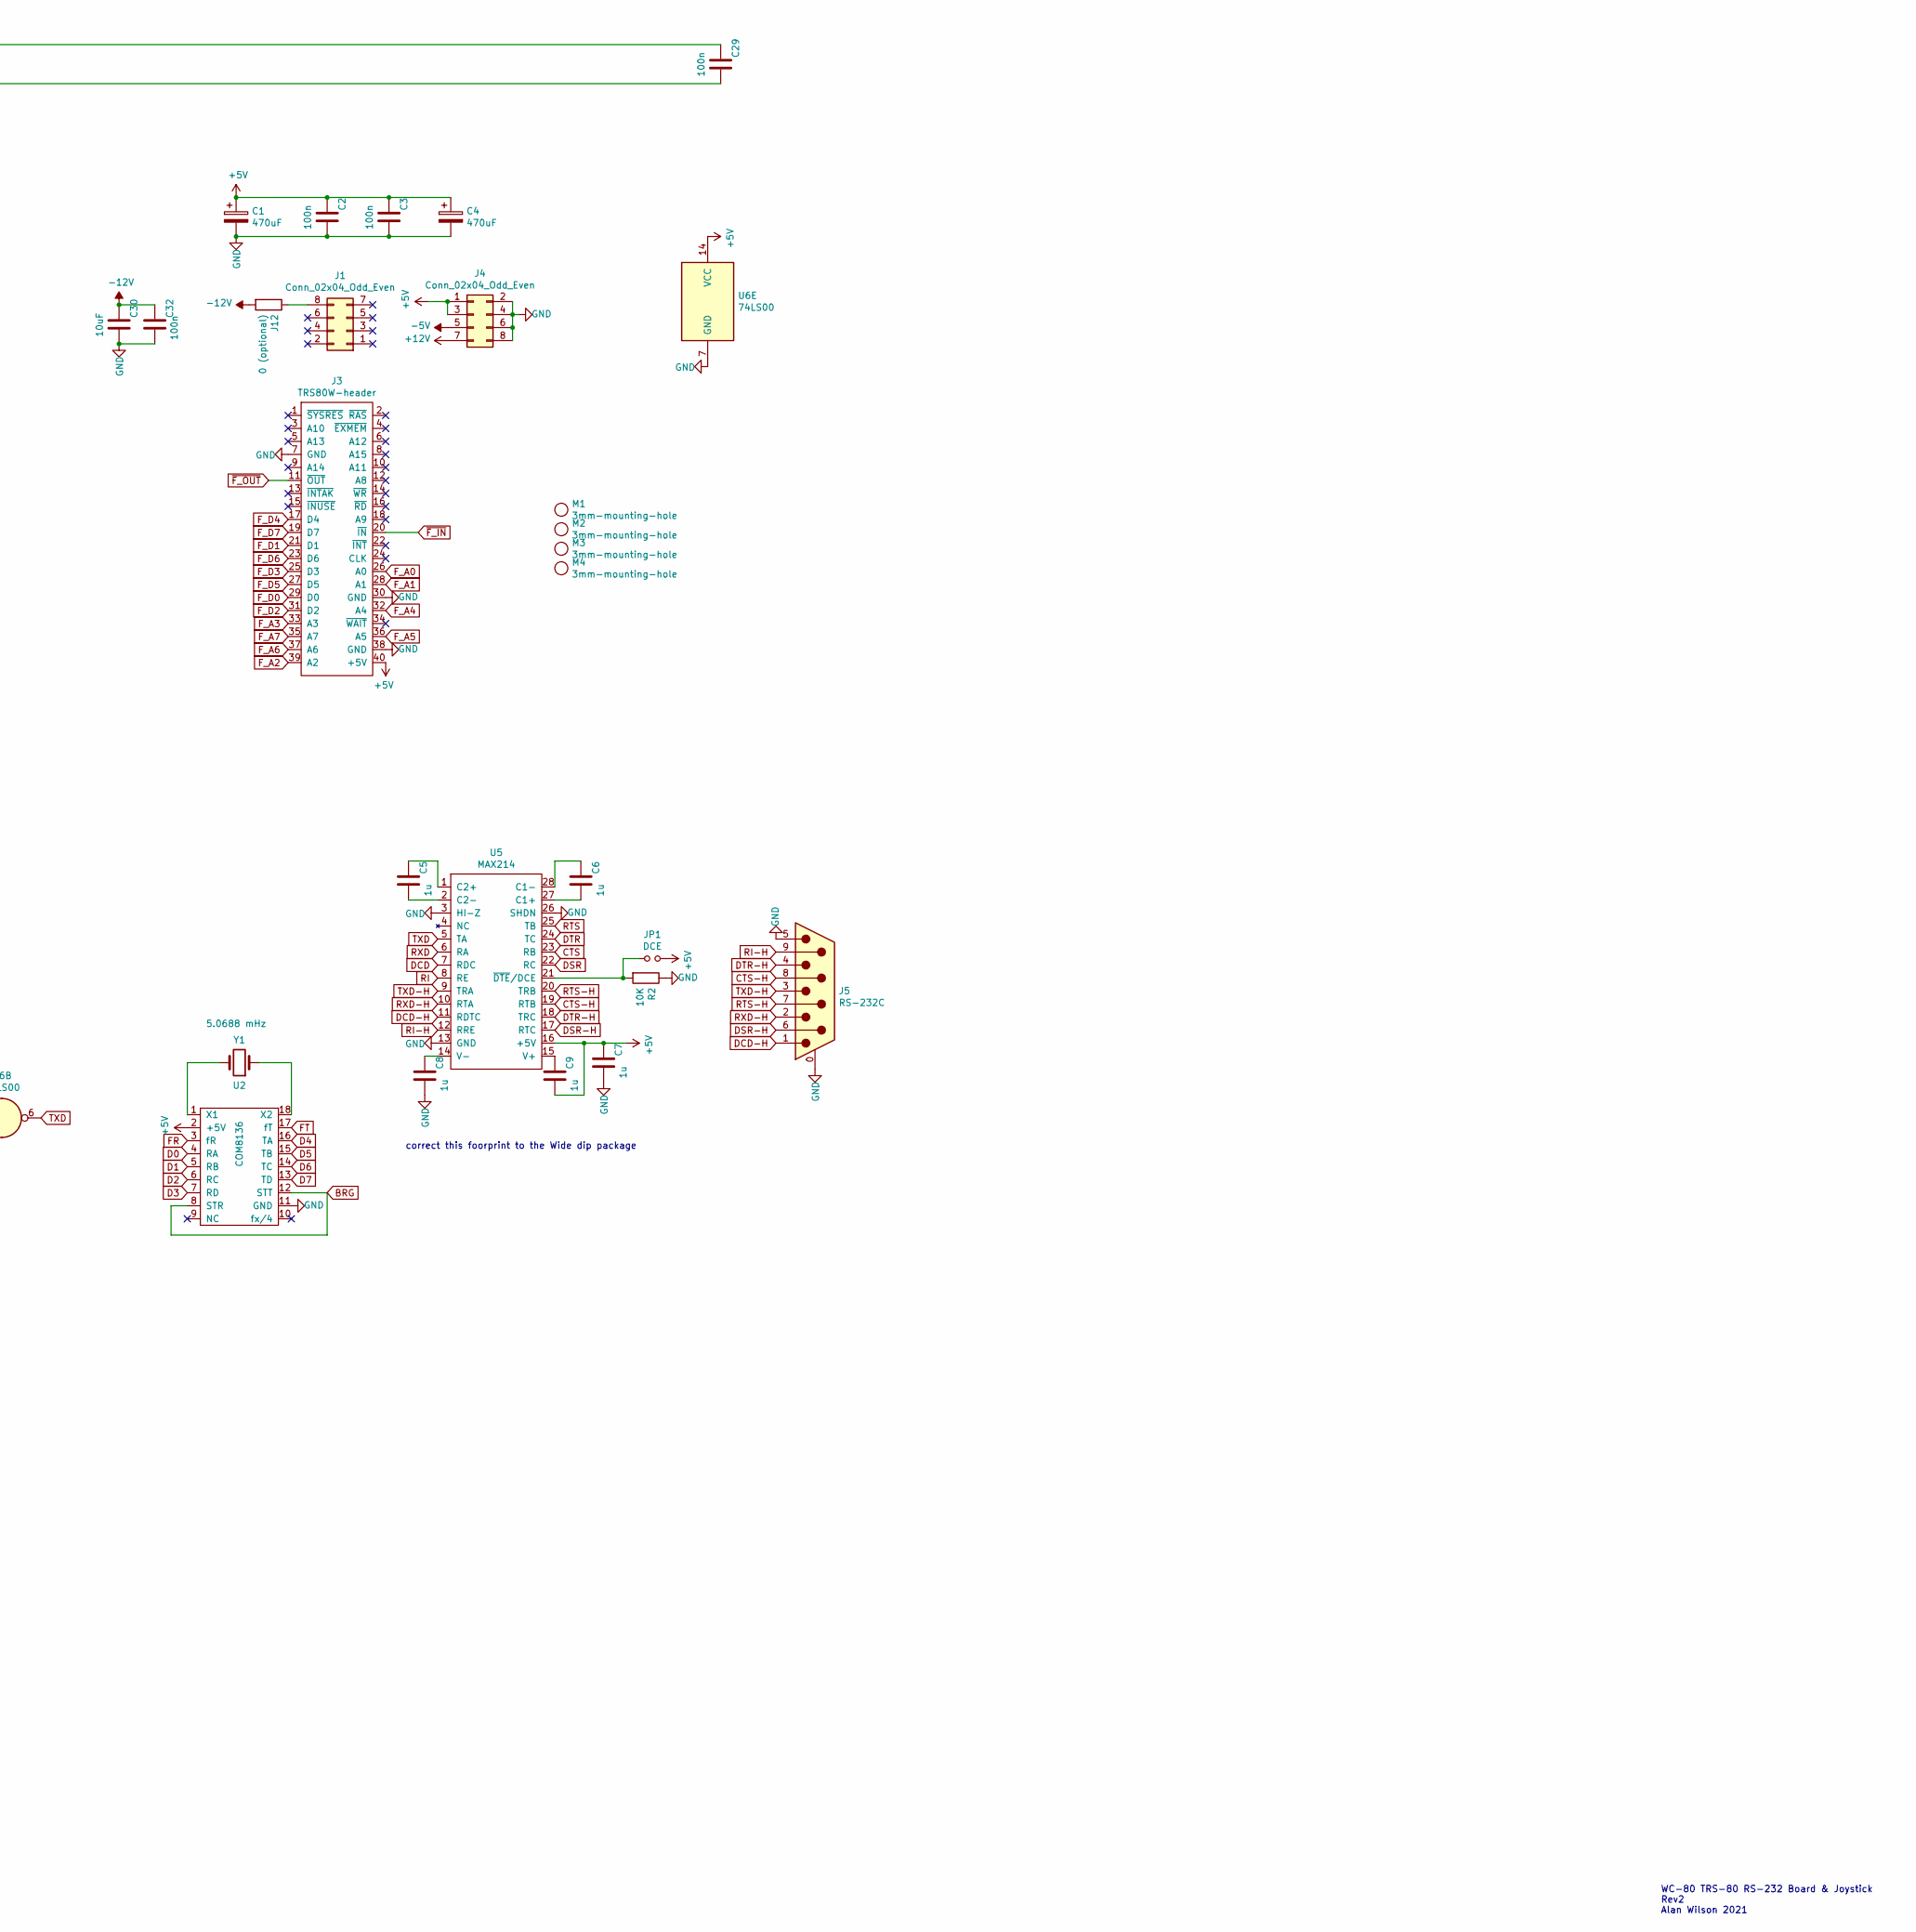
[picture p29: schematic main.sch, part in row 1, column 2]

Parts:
C1, C4: 470uF; CP_Radial_D8.0mm_P3.50mm
C2, C3, C14, C16, C17, C18, C19, C21, C22, C29, C32: 100n; C_0805_2012Metric
C5, C6, C7, C8, C9: 1u; C_0805_2012Metric
C10, C11, C12, C13: 10n; C_0805_2012Metric
C30: 10uF; C_0805_2012Metric
D1, D2: 1N4148; D_DO-35_SOD27_P7.62mm_Horizontal
J1, J4: Conn_02x04_Odd_Even; PinHeader_2x04_P2.54mm_Vertical
J2: JOYSTICK; DS1037-09MNAKT74-0CC
J3: TRS80W-header; PinHeader_2x20_P2.54mm_Vertical
J5: RS-232C; DS1037-09MNAKT74-0CC
J12: 0 (optional); R_0805_2012Metric
JP1: DCE; PinHeader_1x02_P2.54mm_Vertical
JP2: 4BIT; PinHeader_1x02_P2.54mm_Vertical
M1, M2, M3, M4: 3mm-mounting-hole; MountingHole_3.2mm_M3_DIN965
R2, R3, R4, R5, R6, R7, R8: 10K; R_0805_2012Metric
U1: TR1602-UART; DIP-40_W15.24mm_Socket
U2: COM8136; DIP-18_W7.62mm_Socket
U3: 74LS245; DIP-20_W7.62mm_Socket
U4, U8: 74LS244; DIP-20_W7.62mm_Socket
U5: MAX214; DIP-28_W15.24mm_Socket
U6: 74LS00; DIP-14_W7.62mm_Socket
U7: 74LS175; DIP-16_W7.62mm_Socket
U9, U10: LM555xN; DIP-8_W7.62mm
U22: ATF22V10C; DIP-24_W7.62mm_Socket
Y1: 5.0688 mHz; Crystal_HC49-U_Horizontal

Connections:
+5V: C1.1, C2.1, C3.1, C4.1, C7.1, C9.2, C14.1, C16.1, C17.1, C18.1, C19.1, C21.1, C22.1, C29.1, J2.7, J3.40 (+5V), J4.1, J4.3, JP1.2, R3.2, R4.2, R5.2, R6.2, R7.2, R8.2, U1.1 (+5V), U2.2 (+5V), U3.20 (VCC), U4.20 (VCC), U5.16 (+5V), U6.14 (VCC), U7.16 (VCC), U8.20 (VCC), U9.4 (R), U9.8 (VCC), U10.4 (R), U10.8 (VCC), U22.24 (VCC)
+12V: J4.7
-5V: J4.5
-12V: C30.1, C32.1, J12.2, U1.2 (-12V)
BRG: U2.8 (STR), U2.12 (STT), U22.16 (12_16)
CTS: U5.23 (RB), U8.17 (I3b)
CTS-H: J5.8, U5.19 (RTB)
D0: U1.12 (RR1), U1.26 (TR1), U2.4 (RA), U3.18 (B0)
D1: U1.11 (RR2), U1.27 (TR2), U2.5 (RB), U3.17 (B1)
D2: U1.10 (RR3), U1.28 (TR3), U2.6 (RC), U3.16 (B2)
D3: U1.9 (RR4), U1.13 (PE), U1.29 (TR4), U1.35 (PI), U2.7 (RD), U3.15 (B3)
D4: U1.8 (RR5), U1.14 (FE), U1.30 (TR5), U1.36 (SBS), U2.16 (TA), U3.14 (B4)
D5: U1.7 (RR6), U1.15 (OE), U1.31 (TR6), U1.37 (WLS2), U2.15 (TB), U3.13 (B5)
D6: U1.6 (RR7), U1.22 (THRE), U1.32 (TR7), U1.38 (WLS1), U2.14 (TC), U3.12 (B6)
D7: U1.5 (RR8), U1.19 (DR), U1.33 (TR8), U1.39 (EPE), U2.13 (TD), U3.11 (B7)
DCD: U5.7 (RDC), U8.13 (I1b)
DCD-H: J5.1, U5.11 (RDTC)
DSR: U5.22 (RC), U8.15 (I2b)
DSR-H: J5.6, U5.17 (RTC)
DTR: U5.24 (TC), U7.2 (Q0)
DTR-H: J5.4, U5.18 (TRC)
E8-out: U1.21 (MR), U22.14 (8_14)
EA-out: U1.34 (CRL), U7.9 (Cp), U22.17 (14_17)
FR: U1.17 (RRC), U2.3 (fR)
FT: U1.40 (TRC), U2.17 (fT)
F_A0: J3.26 (A0), U22.3
F_A1: J3.28 (A1), U22.4
F_A2: J3.39 (A2), U22.5
F_A3: J3.33 (A3), U22.6
F_A4: J3.32 (A4), U22.7
F_A5: J3.36 (A5), U22.8
F_A6: J3.37 (A6), U22.9
F_A7: J3.35 (A7), U22.10
F_D0: J3.29 (D0), U3.2 (A0), U4.18 (O0a), U7.4 (D0), U8.18 (O0a)
F_D1: J3.21 (D1), U3.3 (A1), U4.16 (O1a), U7.5 (D1), U8.16 (O1a)
F_D2: J3.31 (D2), U3.4 (A2), U4.14 (O2a), U7.12 (D2), U7.13 (D3), U8.14 (O2a)
F_D3: J3.25 (D3), U3.5 (A3), U4.12 (O3a), U8.12 (O3a)
F_D4: J3.17 (D4), U3.6 (A4), U4.9 (O0b), U8.9 (O0b)
F_D5: J3.27 (D5), U3.7 (A5), U4.7 (O1b), U8.7 (O1b)
F_D6: J3.23 (D6), U3.8 (A6), U4.5 (O2b), U8.5 (O2b)
F_D7: J3.19 (D7), U3.9 (A7), U4.3 (O3b), U8.3 (O3b)
GND: C1.2, C2.2, C3.2, C4.2, C7.2, C8.2, C10.2, C11.2, C12.2, C13.2, C14.2, C16.2, C17.2, C18.2, C19.2, C21.2, C22.2, C29.2, C30.2, C32.2, J2.0 (PAD), J2.8, J3.7 (GND), J3.30 (GND), J3.38 (GND), J4.2, J4.4, J4.6, J4.8, J5.0 (PAD), J5.5, R2.1, U1.3 (GND), U2.11 (GND), U3.10 (GND), U3.19 (CE), U4.10 (GND), U4.17 (I3b), U5.3 (HI-Z), U5.13 (GND), U5.26 (SHDN), U6.7 (GND), U7.8 (GND), U8.10 (GND), U9.1 (GND), U10.1 (GND), U22.11, U22.12 (GND), U22.13
JSTK: U4.1 (OEa), U4.19 (OEb), U22.23 (8_23)
unnamed: C5.1, U5.1 (C2+)
unnamed: C5.2, U5.2 (C2-)
unnamed: C6.1, U5.28 (C1-)
unnamed: C6.2, U5.27 (C1+)
unnamed: C8.1, U5.14 (V-)
unnamed: C9.1, U5.15 (V+)
unnamed: C10.1, U9.5 (CV)
unnamed: C11.1, J2.5, U9.6 (THR), U9.7 (DIS)
unnamed: C12.1, U10.5 (CV)
unnamed: C13.1, J2.9, U10.6 (THR), U10.7 (DIS)
unnamed: J1.8, J12.1
unnamed: J2.1, R8.1, U4.2 (I0a)
unnamed: J2.2, R7.1, U4.4 (I1a)
unnamed: J2.6, JP2.1, R4.1, U4.11 (I0b)
unnamed: JP1.1, R2.2, U5.21 (~DTE~/DCE)
unnamed: R3.1, U7.1 (~Mr)
unnamed: U1.25 (TRO), U6.1
unnamed: U2.1 (X1), Y1.2
unnamed: U2.18 (X2), Y1.1
unnamed: U3.1 (A->B), U6.11
unnamed: U4.13 (I1b), U9.3 (Q)
unnamed: U6.2, U7.10 (Q2)
unnamed: U6.3, U6.4, U6.5
unnamed: U6.8, U6.12, U6.13
unnamed: U4.15 (I2b), U10.3 (Q)
RI: U5.8 (RE), U8.11 (I0b)
RI-H: J5.9, U5.12 (RRE)
RTS: U5.25 (TB), U7.7 (Q1)
RTS-H: J5.7, U5.20 (TRB)
RXD: U1.20 (RI), U5.6 (RA), U8.2 (I0a), U8.4 (I1a), U8.6 (I2a), U8.8 (I3a)
RXD-H: J5.2, U5.10 (RTA)
TXD: U5.5 (TA), U6.6
TXD-H: J5.3, U5.9 (TRA)
~E8-in~: U8.1 (OEa), U8.19 (OEb), U22.15 (10_15)
~EA-in~: U1.16 (SFD), U6.10, U22.18 (16_18)
~EB-in~: U1.4 (RRD), U1.18 (DRR), U6.9, U22.19 (16_19)
~EB-out~: U1.23 (THRL), U22.20 (14_20)
~F_IN~: J3.20 (~IN~), U22.2
~F_OUT~: J3.11 (~OUT~), U22.1
~PADTRG~: U9.2 (TR), U10.2 (TR), U22.22 (10_22)

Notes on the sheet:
WC-80 TRS-80 RS-232 Board & Joystick Rev2 Alan Wilson 2021
not yet tested 11/24/2021
flipped these diodes (- to jumper)
correct this foorprint to the Wide dip package

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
Board: 2 copper layers, 56 parts (29 on the bottom side), 84 nets, no tracks yet.

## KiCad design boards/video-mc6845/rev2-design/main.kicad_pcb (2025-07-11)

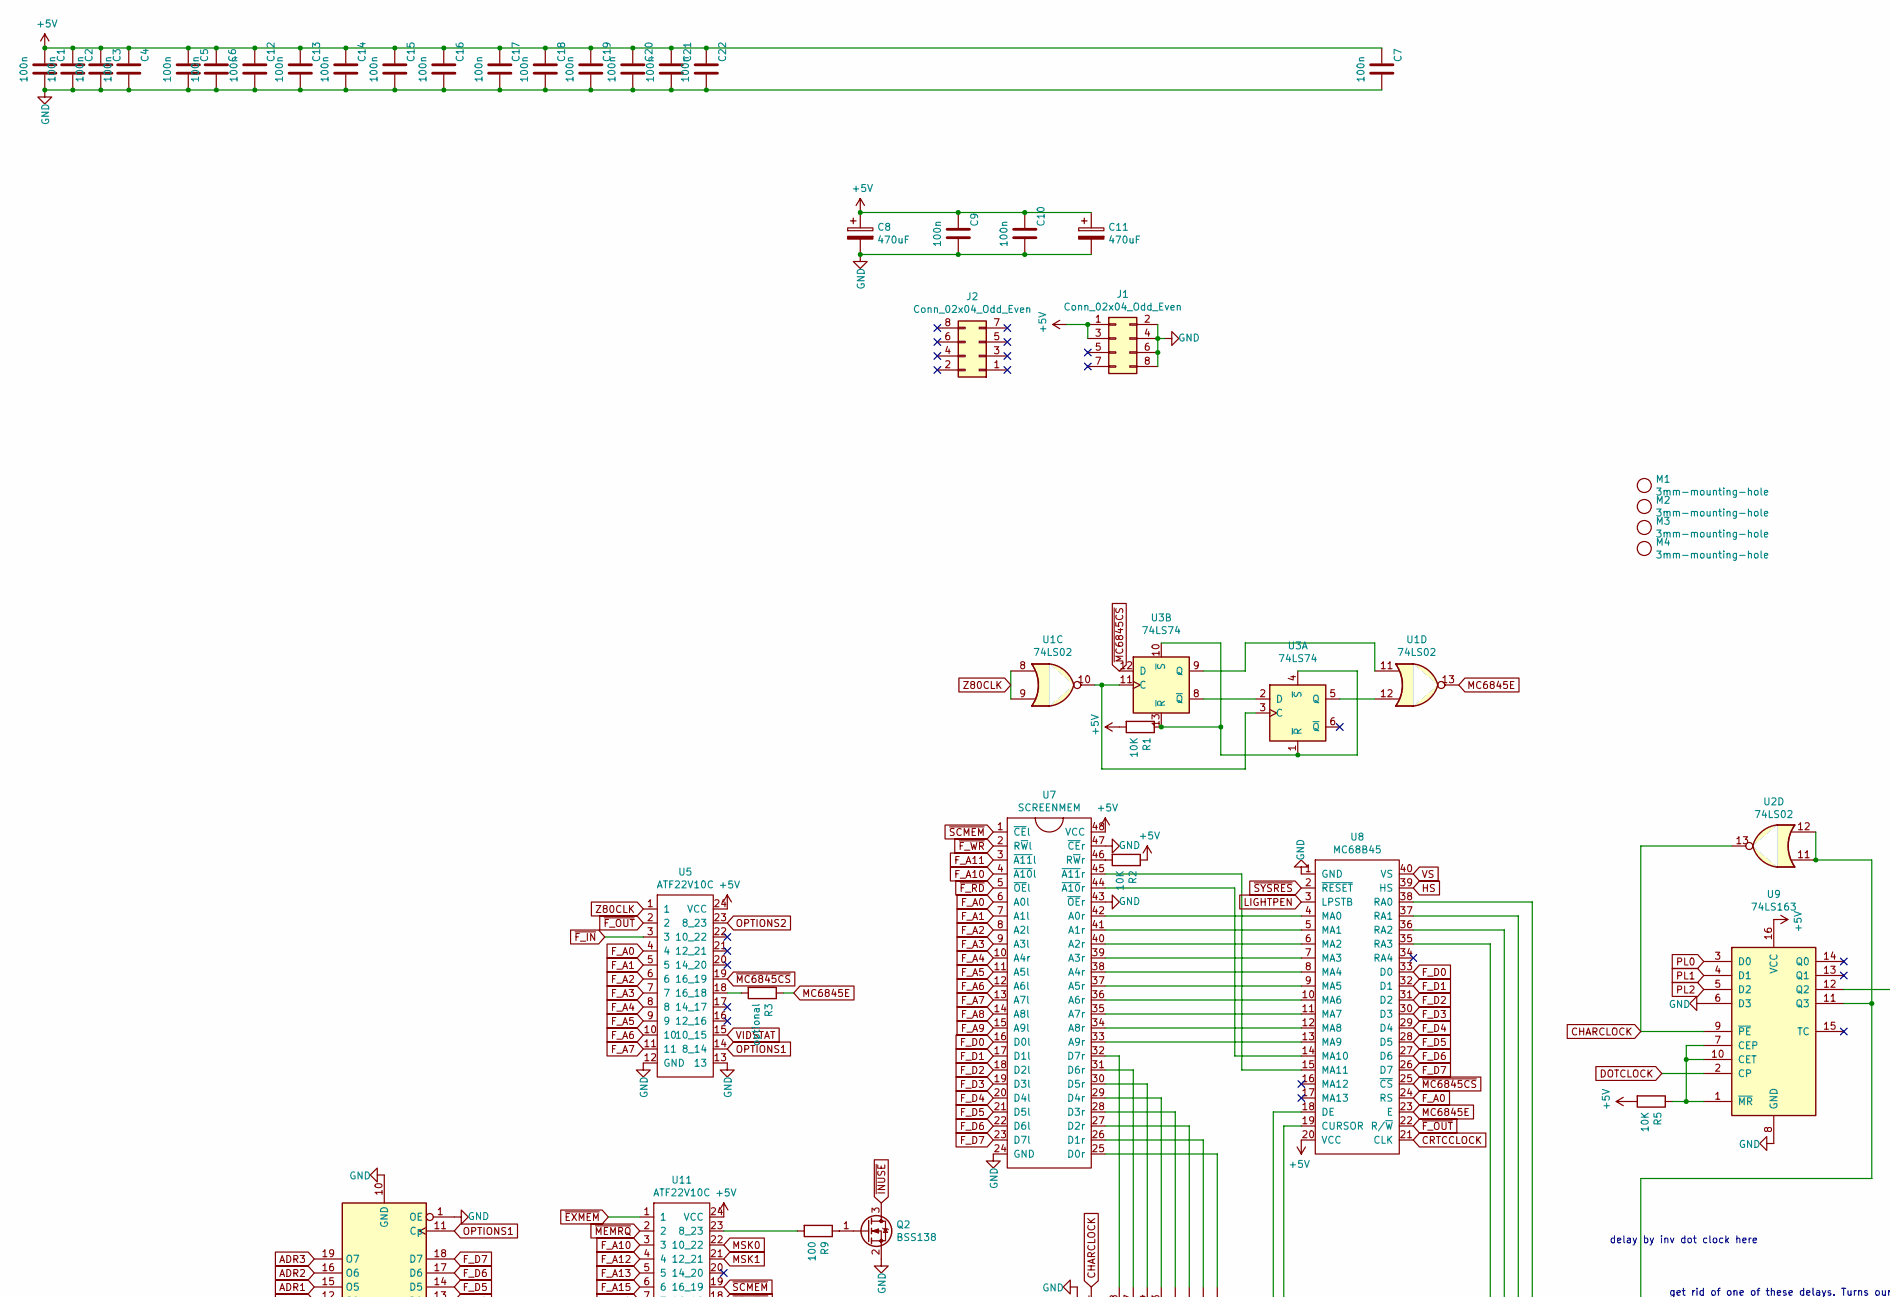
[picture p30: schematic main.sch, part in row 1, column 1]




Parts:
C1, C2, C3, C4, C5, C6, C7, C9, C10, C12, C13, C14, C15, C16, C17, C18, C19, C20, C21, C22: 100n; C_0805_2012Metric
C8, C11: 470uF; CP_Radial_D8.0mm_P3.50mm
J1, J2: Conn_02x04_Odd_Even; PinHeader_2x04_P2.54mm_Vertical
J3: LIGHT_PEN; PinHeader_1x04_P2.54mm_Horizontal
J4: CRT_SIGNALS; PinHeader_1x05_P2.54mm_Vertical
J5: TRS80W-header; PinHeader_2x20_P2.54mm_Vertical
J6: Conn_Coaxial; AV-5
M1, M2, M3, M4: 3mm-mounting-hole; MountingHole_3.2mm_M3_DIN965
Q1: 2N3904; TO-92_Inline
Q2, Q3: BSS138; SOT-23
R1, R2, R4, R5, R12, R13, R14, R15: 10K; R_0805_2012Metric
R3: optional; R_0805_2012Metric
R6: 1800; R_0805_2012Metric
R7: 10; R_0805_2012Metric
R8: 2000; R_0805_2012Metric
R9, R16: 100; R_0805_2012Metric
R10: 470; R_0805_2012Metric
R11: 68; R_0805_2012Metric
U1, U2: 74LS02; SOIC-14_3.9x8.7mm_P1.27mm
U3, U4: 74LS74; SOIC-14_3.9x8.7mm_P1.27mm
U5, U11: ATF22V10C; DIP-24_W7.62mm_Socket
U6, U12, U13: 74LS374; SOIC-20W_7.5x12.8mm_P1.27mm
U7: SCREENMEM; DIP-48_W15.24mm_Socket
U8: MC68B45; DIP-40_W15.24mm_Socket
U9, U17: 74LS163; SOIC-16_3.9x9.9mm_P1.27mm
U10: LTC6903; MSOP-8_3x3mm_P0.65mm
U14: 74LS244; SOIC-20W_7.5x12.8mm_P1.27mm
U15: 74LS175; SOIC-16_3.9x9.9mm_P1.27mm
U16: CHARROM; DIP-48_W15.24mm_Socket
U18: 74LS165; SO-16_3.9x9.9mm_P1.27mm
X1: SG-7050CAN; Oscillator_SMD_SeikoEpson_SG8002CA-4Pin_7.0x5.0mm

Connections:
/CURSOR: U2.2, U15.10 (Q2)
/~DISPEN~: U2.6, U15.6 (~Q1)
CHARCLOCK: U2.13, U9.9 (~PE), U13.11 (Cp), U18.1 (~PL)
DC0: U6.12 (O4), U10.2 (SDI), U17.3 (D0)
DC1: U6.15 (O5), U10.3 (SCK), U17.4 (D1)
DC2: U6.16 (O6), U10.4 (~SEN~), U17.5 (D2)
F_A0: J5.26 (A0), U5.4, U7.6 (A0l), U8.24 (RS), U16.6 (A0l)
F_A1: J5.28 (A1), U5.5, U7.7 (A1l), U16.7 (A1l)
F_A2: J5.39 (A2), U5.6, U7.8 (A2l), U16.8 (A2l)
F_A3: J5.33 (A3), U5.7, U7.9 (A3l), U16.9 (A3l)
F_A4: J5.32 (A4), U5.8, U7.10 (A4r), U16.10 (A4r)
F_A5: J5.36 (A5), U5.9, U7.11 (A5l), U16.11 (A5l)
F_A6: J5.37 (A6), U5.10, U7.12 (A6l), U16.12 (A6l)
F_A7: J5.35 (A7), U5.11, U7.13 (A7l), U16.13 (A7l)
F_A8: J5.12 (A8), U7.14 (A8l), U16.14 (A8l)
F_A9: J5.18 (A9), U7.15 (A9l), U16.15 (A9l)
F_A10: J5.3 (A10), U7.4 (~A10~l), U11.3, U16.4 (~A10~l)
F_A11: J5.10 (A11), U7.3 (~A11~l), U11.8, U16.3 (~A11~l)
F_A12: J5.6 (A12), U11.4
F_A13: J5.5 (A13), U11.5
F_A14: J5.9 (A14), U11.7
F_A15: J5.8 (A15), U11.6
F_D0: J5.29 (D0), U6.3 (D0), U7.16 (D0l), U8.33 (D0), U12.3 (D0), U14.12 (O3a), U16.16 (D0l)
F_D1: J5.21 (D1), U6.4 (D1), U7.17 (D1l), U8.32 (D1), U12.4 (D1), U14.14 (O2a), U16.17 (D1l)
F_D2: J5.31 (D2), U6.7 (D2), U7.18 (D2l), U8.31 (D2), U12.7 (D2), U14.16 (O1a), U16.18 (D2l)
F_D3: J5.25 (D3), U6.8 (D3), U7.19 (D3l), U8.30 (D3), U12.8 (D3), U14.18 (O0a), U16.19 (D3l)
F_D4: J5.17 (D4), U6.13 (D4), U7.20 (D4l), U8.29 (D4), U12.13 (D4), U16.20 (D4l)
F_D5: J5.27 (D5), U6.14 (D5), U7.21 (D5l), U8.28 (D5), U12.14 (D5), U16.21 (D5l)
F_D6: J5.23 (D6), U6.17 (D6), U7.22 (D6l), U8.27 (D6), U12.17 (D6), U16.22 (D6l)
F_D7: J5.19 (D7), U6.18 (D7), U7.23 (D7l), U8.26 (D7), U12.18 (D7), U16.23 (D7l)
HS: U8.39 (HS), U14.4 (I1a), U14.13 (I1b)
IMAGE: U4.9 (Q), U14.17 (I3b)
LIGHTPEN: U8.3 (LPSTB), U14.9 (O0b)
MC6845E: R3.1, U1.13, U8.23 (E)
unnamed: J3.2, U14.8 (I3a), U14.11 (I0b)
unnamed: J3.3, U14.6 (I2a)
unnamed: J4.2, R8.2, U14.3 (O3b)
unnamed: J4.3, U1.3, U14.5 (O2b)
unnamed: J4.4, U1.2, U14.7 (O1b)
unnamed: J6.1 (In), Q1.1 (E), R11.2
unnamed: Q1.2 (B), R6.1, R8.1, R10.2
unnamed: Q2.1 (G), R9.1
unnamed: Q3.1 (G), R16.1
unnamed: R1.1, U3.1 (~R), U3.4 (~S), U3.10 (~S), U3.13 (~R)
unnamed: R2.2, U7.46 (R~W~r)
unnamed: R3.2, U5.18 (16_18)
unnamed: R4.1, U4.1 (~R), U4.4 (~S)
unnamed: R5.1, U9.1 (~MR), U9.7 (CEP), U9.10 (CET)
unnamed: R6.2, U1.1
unnamed: R7.2, U10.6 (CLK)
unnamed: R9.2, U11.23 (8_23)
unnamed: R12.1, U15.1 (~Mr)
unnamed: R13.1, U16.46 (R~W~r)
unnamed: R14.1, U17.1 (~MR), U17.7 (CEP), U17.10 (CET)
unnamed: R15.1, U4.10 (~S), U4.13 (~R)
unnamed: U1.10, U3.3 (C), U3.11 (C)
unnamed: U1.11, U3.9 (Q)
unnamed: U1.12, U3.5 (Q)
unnamed: U2.1, U2.5
unnamed: U2.4, U4.12 (D)
unnamed: U3.2 (D), U3.8 (~Q)
unnamed: U7.33 (A9r), U8.13 (MA9)
unnamed: U7.34 (A8r), U8.12 (MA8)
unnamed: U7.35 (A7r), U8.11 (MA7)
unnamed: U7.36 (A6r), U8.10 (MA6)
unnamed: U7.37 (A5r), U8.9 (MA5)
unnamed: U7.38 (A4r), U8.8 (MA4)
unnamed: U7.39 (A3r), U8.7 (MA3)
unnamed: U7.40 (A2r), U8.6 (MA2)
unnamed: U7.41 (A1r), U8.5 (MA1)
unnamed: U7.42 (A0r), U8.4 (MA0)
unnamed: U7.44 (~A10~r), U8.14 (MA10)
unnamed: U7.45 (~A11~r), U8.15 (MA11)
unnamed: U13.2 (O0), U16.38 (A4r)
unnamed: U7.25 (D0r), U13.3 (D0)
unnamed: U7.26 (D1r), U13.4 (D1)
unnamed: U13.5 (O1), U16.37 (A5r)
unnamed: U13.6 (O2), U16.36 (A6r)
unnamed: U7.27 (D2r), U13.7 (D2)
unnamed: U7.28 (D3r), U13.8 (D3)
unnamed: U13.9 (O3), U16.35 (A7r)
unnamed: U13.12 (O4), U16.34 (A8r)
unnamed: U7.29 (D4r), U13.13 (D4)
unnamed: U7.30 (D5r), U13.14 (D5)
unnamed: U13.15 (O5), U16.33 (A9r)
unnamed: U13.16 (O6), U16.44 (~A10~r)
unnamed: U7.31 (D6r), U13.17 (D6)
unnamed: U7.32 (D7r), U13.18 (D7)
unnamed: U13.19 (O7), U16.45 (~A11~r)
unnamed: U15.2 (Q0), U15.5 (D1)
unnamed: U8.18 (DE), U15.4 (D0)
unnamed: U2.11, U2.12, U9.11 (Q3), U15.9 (Cp)
unnamed: U15.12 (D2), U15.15 (Q3)
unnamed: U8.19 (CURSOR), U15.13 (D3)
unnamed: U16.25 (D0r), U18.6 (D7)
unnamed: U16.26 (D1r), U18.5 (D6)
unnamed: U16.27 (D2r), U18.4 (D5)
unnamed: U16.28 (D3r), U18.3 (D4)
unnamed: U16.29 (D4r), U18.14 (D3)
unnamed: U16.30 (D5r), U18.13 (D2)
unnamed: U16.31 (D6r), U18.12 (D1)
unnamed: U16.32 (D7r), U18.11 (D0)
unnamed: U8.35 (RA3), U16.39 (A3r)
unnamed: U8.36 (RA2), U16.40 (A2r)
unnamed: U8.37 (RA1), U16.41 (A1r)
unnamed: U8.38 (RA0), U16.42 (A0r)
unnamed: U17.2 (CP), X1.3 (OUT)
unnamed: U2.3, U18.9 (Q7)
OPT0: U11.22 (10_22), U12.2 (O0)
OPT1: U11.21 (12_21), U12.5 (O1)
OPT2: U11.9, U12.6 (O2)
OPT3: U11.15 (10_15), U12.9 (O3)
OPT4: U11.10, U12.12 (O4)
OPT5: U11.14 (8_14), U12.15 (O5)
OPT6: U11.11, U12.16 (O6)
OPT7: U11.13, U12.19 (O7)
OPT8: U6.2 (O0), U11.16 (12_16)
OPTIONS1: U5.14 (8_14), U12.11 (Cp)
OPTIONS2: U5.23 (8_23), U6.11 (Cp)
PL0: U6.5 (O1), U9.3 (D0)
PL1: U6.6 (O2), U9.4 (D1)
PL2: U6.9 (O3), U9.5 (D2)
VIDSTAT: U5.15 (10_15), U14.1 (OEa)
VS: R16.2, U8.40 (VS), U14.2 (I0a), U14.15 (I2b)
Z80CLK: J5.24 (CLK), U1.8, U1.9, U5.1
~CRMEM~: U11.18 (16_18), U16.1 (~CE~l)
~EXMEM~: J5.4 (~EXMEM~), U11.1
~F_IN~: J5.20 (~IN~), U5.3
~F_OUT~: J5.11 (~OUT~), U5.2, U8.22 (R/~W~)
~F_RD~: J5.16 (~RD~), U7.5 (~OE~l), U16.5 (~OE~l)
~F_WR~: J5.14 (~WR~), U7.2 (R~W~l), U16.2 (R~W~l)
~INT~: J5.22 (~INT~), Q3.3 (D)
~INUSE~: J5.15 (~INUSE~), Q2.3 (D)
~MC6845CS~: U3.12 (D), U5.19 (16_19), U8.25 (~CS~)
~MEMRQ~: J5.2 (~RAS~), U11.2
~SCMEM~: U7.1 (~CE~l), U11.19 (16_19)
~SYSRES~: U6.19 (O7), U8.2 (~RESET~)

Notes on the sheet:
WC-80 MC6845 Video Board Alan Wilson 2021
rev3 - for my osc, you need to tie pin 1 to vcc
rev3 - use the inverter closest to this chip
rev3 -TODO - maybe combine light pen and this onto one header?
rev3 - crtc clock is just fine here
rev3 - need to change this to ls166
rev3 - todo - change to inverted dotclock
rev3 - renamed these labels to be better
rev3 - this buffer doesn't seem to work very well
nevermind, this resistor just needed to be dropped to like 50
rev3 - clone output buffer from model 1?
also change direction - D7 should come out first
delay by inv dot clock here
get rid of one of these delays. Turns our we only need a delay by 1, not 2
2021/12/05 - this is NOT how NTSC/Composite video is supossed to work - 1V pk-pk at 75 ohm impedance!

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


Board: 2 copper layers, 100.0 x 100.0 mm, 70 parts (39 on the bottom side), 143 nets.

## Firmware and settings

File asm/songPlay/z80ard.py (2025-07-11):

# thingy for loading via ARVMON program / board for my Z80 computer project
# uses AVRMON2 running on the onboard AVR and the shared dual port RAM (sometimes with z80 code inside)
from fileinput import filename
import serial
import sys

# USAGE: z80ard <port> <method> <address (paramater to command)> <filename of binary>

tFilename = "dol.bin"
tAddress = 0
tPort = "COM9"
tMethod = "lww"

tPort = sys.argv[1]
tMethod = sys.argv[2]
tAddress = int(sys.argv[3], 16)
tFilename = sys.argv[4]

print("Uploading", tFilename, "via", tPort, "using", tMethod, "to", tAddress)

s = serial.Serial(tPort, 1000000)

#on Serial port open, AVRMON will restart
w = b""
while w != b">":
    w = s.read()  # wait for > prompt

if(tMethod == "exl"):
    s.write(b'lm 1 \r')
    print("Jump to 3000, then press Enter")
    input()

    f = open(tFilename, "rb")

    chunkIndex = 0
    chunk = 0
    exitflag = 0
    while True:
        if(exitflag == 0):
            b = f.read(1)
            if not b:
                f.close()
                exitflag = 1
        if(exitflag == 1):
            b = b'\x00'
        if(chunkIndex == 0):
            w = b' '
            while w != b">":
                s.write(b'\r')
                w = s.read()
            s.write(b'exl ')
            s.write("{:02x}".format(tAddress+(chunk*128)).encode())
            s.write(b'\r')
            if(chunk % 8 == 0):
                print("\r",int((chunk*128)/1024), "K", sep='',end='', flush=True)
            s.write(b)
            chunkIndex = 1
        elif(chunkIndex == 127):
            s.write(b)
            s.flush()
            w = b' '
            while w != b"<":
                w = s.read()
            w = s.read()
            if(w == b'3'):
                chunk += 1
            chunkIndex = 0
            s.flush()
            if(exitflag == 1):
                break
        else:
            s.write(b)
            chunkIndex += 1
    s.write(b'\r')
    s.flush()
    w = b' '
    while w != b">":
        w = s.read()
    s.write(b'lw 300 0\r')
    w = b' '
    while w != b">":
        w = s.read()
    s.write(b'lw 300 ff\r')
    quit()

if(tMethod == "lww"):
    s.write(b'lww ')
    s.write("{:02x}".format(tAddress).encode())
    s.write(b'\r')

    f = open(tFilename,"rb")

    count = 0
    while True:
        b = f.read(1)
        if not b:
            f.close()
            break
        else:
            print(count, "{:02x}".format(ord(b)))
            s.write("{:02x}".format(ord(b)).encode())
            s.write(b'\r')
            w = b""
            while w!= b">":
                w=s.read() #wait for > prompt
            count += 1 

    s.write(b'\r\r\r')
    print("done")
    quit()

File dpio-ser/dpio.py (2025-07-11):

# thingy for loading via DPIO on AVRMON - Alnwlsn's WC80 Computer Project
# uses AVRMON2 running on the onboard AVR and the shared dual port RAM
from fileinput import filename
from socket import timeout
from cv2 import add
from parso import parse
import serial
import argparse

parser = argparse.ArgumentParser(
    description='Writes a file to the WC80 memory using DPIO')
parser.add_argument(
    'COM', type=str, help='COM port on which AVR board is attached')
parser.add_argument(
    'ADR', type=str, help='[HEX] address at which to start write')
parser.add_argument(
    '-j', type=str, help='[HEX] address at which to jump after writing')
parser.add_argument('FILE', type=str, help='file to write')
args = parser.parse_args()


class dpio:
    def __init__(self, port):
        self.s = serial.Serial(port, 1000000, timeout=1)
        # on Serial port open, AVRMON will restart
        w = b""
        while w != b">":
            w = self.s.read()  # wait for > prompt
        self.s.write(b'*\r')  # enter DPIO terminal
        while w != b"\x00":
            w = self.s.read()  # wait for null (DPIO) prompt
        self.s.reset_input_buffer()

    def txn(self, command, address, data):  # complete DPIO transaction
        self.s.write(command.to_bytes(1, 'little'))
        self.s.write(address.to_bytes(2, 'little'))
        self.s.write(data.to_bytes(1, 'little'))
        rxd = self.s.read()
        if(rxd == b''):
            print("Serial timed out - quitting")
            quit()
        return rxd

    def read(self, address):
        return self.txn(2, address, 0)

    def write(self, address, data):
        return self.txn(1, address, data)

    def inp(self, address):
        return self.txn(4, address, 0)

    def out(self, address, data):
        return self.txn(3, address, data)

    def jump(self, address):
        self.s.write((5).to_bytes(1, 'little'))
        self.s.write(address.to_bytes(2, 'little'))
        self.s.write((0).to_bytes(1, 'little'))


tAddress = int(args.ADR, 16)

print("Sending", args.FILE, "to address 0x{:04x}".format(tAddress))

m = dpio("COM10")
with open(args.FILE, "rb") as f:
    while (tx := f.read(1)):
        m.write(tAddress, tx[0])
        rx = m.read(tAddress)
        if(rx != tx):
            print("verify failed at 0x{:04x}".format(tAddress))
            quit()
        tAddress += 1
if(args.j != None):
    m.jump(int(args.j, 16))

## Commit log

2025-07-11 bulk file add
    [cpu.kicad_pcb, cpu.sch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]
2025-07-17 cpu boards

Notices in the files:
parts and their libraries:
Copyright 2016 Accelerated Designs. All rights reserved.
